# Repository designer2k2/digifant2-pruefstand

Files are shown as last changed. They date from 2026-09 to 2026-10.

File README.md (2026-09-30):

# Digifant-2 Prüfstand




Hardware for a fully-automated test bench for the VW Golf 1 Cabrio **Digifant-2** ECU:
signal simulator + capture front-end, driven by a Raspberry Pi Pico 2, with a
high-side load switch so the bench can cold-boot the ECU and cut power on
overcurrent. Scope here is the **Signal-Simulator + Erfassungseinheit** only — the
EPROM emulator is a separate future board.

The schematic is generated from Python with
[circuit-synth](https://github.com/circuit-synth/circuit-synth); the PCB is placed
and autorouted headless (`pcbnew` + Freerouting).

**[`firmware/OPERATION.md`](firmware/OPERATION.md) — how to operate the
bench: display and buttons, PC control and scripting, reading the
measurements.**

**[`BRINGUP.md`](BRINGUP.md) — step-by-step first power-on checklist, tools
needed, and the open questions to settle on the bench.**

**[`DESIGN.md`](DESIGN.md) — what every block does, part-selection rationale, the
GPIO / I²C / VW-harness maps.** [`USE_CASES.md`](USE_CASES.md) traces every real
bench use case through the schematic to concrete numbers (voltage/current/timing
headroom) — a requirements/test matrix for the hardware, and where the AD9833
decoupling-cap gap turned up before it got fixed.

## Layout

| path | what |
|---|---|
| `digifant2_pruefstand.py` | the circuit — one `@circuit` function, flat single sheet |
| `gen_custom_symbols.py` | builds `kicad-symbols/Custom_Digifant2.kicad_sym` (INA226, AD9833, 2N7002, DPAK P-FET, VW connector — pinouts verified against datasheets) |
| `gen_project.py` | `python3 gen_project.py <name>` → full KiCad project + netlist + lib tables, runs ERC/DRC via `kicad-cli`, auto-applies no-connect flags |
| `place_and_route.py` | `pcbnew` functional-zone placement → Specctra DSN → Freerouting → SES import (run inside the KiCad flatpak; `java` runs outside it) |
| `add_nc_flags.py` | stamps `no_connect` flags from an ERC report (circuit-synth has no NC API) |
| `fix_layout.py` | post-route layout surgery (real netclasses, GND/Kelvin re-routing) — see the header comment for the 2-phase, 2-process invocation it needs |
| `reroute_missing.py` | re-exports a Specctra DSN from a partially-ripped-up board so Freerouting only has to fill the reopened ratsnest |
| [`firmware/`](firmware/README.md) | Pico firmware (Pico SDK, C): USB serial command protocol, build/flash instructions, what's implemented vs. stubbed |
| `host/bench.py` | PC-side client for the firmware protocol: interactive prompt, one-shot CLI, or importable `Bench` class; `host/examples/` has a scripted rpm sweep |
| `board/` | the current KiCad project (144×150 mm, 2-layer, 4× M3 corner holes, isolated OLED + USB clearance zones) |
| [`board/bom_output/bom.html`](board/bom_output/bom.html) | interactive BOM ([InteractiveHtmlBom](https://github.com/openscopeproject/InteractiveHtmlBom)) — click a part to highlight it on the board, no KiCad needed |
| [`BOM.md`](BOM.md) | Mouser sourcing: part numbers for every line item, with confidence notes — 6 of 30 need manual confirmation, see the file |
| [`mouser_cart.csv`](mouser_cart.csv) | only the Mouser-verified part numbers, ready to paste into Mouser's bulk order tool |
| [`JLCPCB_ASSEMBLY.md`](JLCPCB_ASSEMBLY.md) | hybrid plan: JLCPCB machine-places the SMD parts, you hand-solder THT + 4 unconfirmed SMD parts — read this before submitting |
| [`jlcpcb_bom.csv`](jlcpcb_bom.csv) / [`jlcpcb_cpl.csv`](jlcpcb_cpl.csv) | JLCPCB SMT-assembly BOM + pick-and-place, 42 of 46 SMD parts (real positions from `board/`, real LCSC part numbers) |
| `UPSTREAM_BUGS.md` | circuit-synth bugs found, drafted for upstream filing |
| `kicad-symbols/`, `kicad-footprints/` | libraries — custom/community committed, stock via `./fetch_libs.sh` |
| `.github/workflows/` | CI: firmware build + tests, spell check, KiCad ERC/DRC, firmware releases (see below) |

## Build

```sh
./fetch_libs.sh                        # one-time: pull stock KiCad 9.0 libs
python3 gen_custom_symbols.py          # if the custom symbols changed
python3 gen_project.py digifant2_pruefstand_cs_v1
```

Placement + routing needs KiCad's `pcbnew` Python API (KiCad ≥ 10) and a
non-headless JRE for Freerouting — see the header of `place_and_route.py`.

## Status

Schematic ERC-clean; VW harness pinout verified against the cabby-info.com
Digifant II reference and the user's own hands-on HiL notes (see `DESIGN.md`).
Board placed + autorouted (144 × 150 mm, 2-layer, 4 × M3 holes, isolated OLED + USB
clearance zones), real Power/Gnd netclasses, GND re-routed as one connected net
(was 4 islands), dedicated Kelvin sense traces for both shunts. The tight
U1/U3/RS1/RS2 pocket (2 shorting_items, 2 clearance, 5 tracks_crossing left by
the scripted Kelvin routing) was cleaned up by hand in KiCad's interactive
router, and a B.Cu GND pour was added. Added the two AD9833 decoupling caps
(C7, C8), fully routed. Fixed RS2 (idle-valve shunt) to be truly in series
with the ECU's VW-23 driver instead of a parallel path to GND that was
corrupting the current reading — this reopened one small pocket at U3 pin 9
(2 `shorting_items`, confined to that one spot after extensive
hand-routing/Freerouting attempts, same class of residual as the historical
U1/U3/RS1/RS2 items). Gave the AD9833 knock output a defined path out
(TP1/TP2 test points for VW-4/VW-5) instead of a dead end. Added 12 more
THT scope-probe test points (TP3–TP14, real drilled holes — an earlier pass
used bare SMD pads and put 10 of them physically underneath the Pico module,
both corrected) on the main GPIO signals, both buses, and both 12 V rails.
Found and fixed a real bug along the way: footprints cloned via
`pcbnew.FOOTPRINT(template)` inherit the template's UUID unless you
explicitly reset it, which had corrupted DRC's item-identity tracking for
every cloned part this session (C7/C8 and all of TP1–TP14) — several
"violations" turned out to be real defects reported against the wrong
footprint. See DESIGN.md's "Known open points" for details if you script
further additions. Remaining warnings are cosmetic (silkscreen overlap,
lib_footprint_mismatch, and one starved_thermal note on a single Pico GND
pad with only 1 pour spoke instead of 2 — connected fine, just a slightly
weaker thermal/mechanical joint). Thermal copper for D1/Q2 still optional to
add by hand. Added a 12×16 perfboard-style proto area (PROTO1, isolated THT
pads on 0.1″ pitch) in the empty space bottom-right of J0. Checked the whole
board against JLCPCB's published fab minimums (trace/spacing, via/hole sizes,
hole-to-hole, copper-to-edge, board thickness) — everything copper- and
hole-related had 1.5×–14× margin already. The one real miss was silkscreen:
KiCad's default 0.1mm line width and 0.8mm text height are both below
JLCPCB's stated minimums (0.15mm / 1.0mm), risking thin/dropped silkscreen.
Bumped the project defaults and widened/enlarged every existing silkscreen
line and text item on the board to meet those minimums.

Checked +3V3 for adequate trace width (it's on the thinnest `Default`
netclass, 0.2mm, despite feeding ~15 chips) — worked out the real numbers
(thermal capacity ~0.77A at 10°C rise, worst-case drop a few mV) and it's
fine as-is; not worth the rerouting risk in this densely-packed board.
Checked decoupling instead: per each part's own datasheet, U1 and U3 (the
two INA226 current-sense amps) had no bypass cap at all, unlike U2/U4 which
already have theirs (C6, C2/C7/C8). Added C9 (U1) and C10 (U3), 100nF 0805,
tapped directly off the existing +3V3 B.Cu trunk and the GND pour a few mm
south of the packed U1/U3/RS1/RS2 pocket (no room to place them right at the
pins) — verified DRC-clean (the only residuals are the same
new-copper-vs-stale-zone-fill noise that clears on a zone refill, same as
after the TP resort). U6/U7/U8 (the sensor-disconnect analog switches) are
still without a bypass cap; lower priority since they're not
noise-sensitive, but could use the same treatment.

Added the thermal copper for D1/Q2 that was flagged as a real (not
cosmetic) risk in USE_CASES.md — D1 dissipates ~1.25W at sustained ~2.5A
with no thermal relief otherwise. Both pours verified electrically
connected to their pads (not just overlapping) and DRC-clean. Q2's is
small since there's almost no open board space around its DPAK tab; D1's
is generous since F1/RS1 (same nets, either side) leave a wide open
corridor.

**All 14 test points (TP1–TP14) are now fully routed** — the user hand-routed
7 of the 10 remaining GPIO test points after the resort (TP3, TP10, TP11,
TP4, TP12, TP5, TP6); the last 3 (TP9, TP8, TP7 — all on U5's east side, the
tightest part of the board) were routed with a grid-based pathfinder (A* over
a 0.1mm grid, spatial-bucket-indexed for speed) purpose-built for this corridor
after several rounds of manual/heuristic routing kept snagging on real
obstacles: the Pico's own pin column has no gap wide enough for a second
trace anywhere along its length (confirmed by direct probing — routed escape
stubs from other GPIOs fill in what would otherwise be a 0.49mm theoretical
gap between pin pads), so both TP8 and TP9 had to detour around the *south*
end of the Pico footprint entirely, and — since that detour corridor is
itself only wide enough for one trace at a time — needed genuinely different
physical crossing points, not just parallel lanes. Verified via real
`kicad-cli pcb drc`, not just the pathfinder's own clearance model (which
undercounted real collisions during development in two ways worth noting for
next time: it modeled non-circular pads by their half-width instead of their
half-diagonal, and it didn't check hole-to-hole spacing against a net's own
via near its own pad — both are now fixed in the approach, see `DESIGN.md`).
GND zone refilled after all of the above (TP9/TP8 routing, C9/C10, D1/Q2
thermal pours) — DRC dropped from 136 to 101 violations, all pre-existing
cosmetic categories plus the one known `starved_thermal` note, zero
clearance/short/crossing issues. (The "whole-board refill introduces ~115
spurious violations" finding earlier this session was a testing artifact —
running `kicad-cli` against a bare copy of the `.kicad_pcb` without its
paired `.kicad_pro` silently falls back to stricter default netclass rules;
with the project file present, the refill is clean.)

Trimmed the board from 144×169mm to 144×150mm — the bottom 19mm was
completely empty (bare GND pour, nothing below PROTO1/J3 until the old
mounting holes). H3/H4 moved up to keep the same 4.5mm hole-to-edge margin
as H1/H2; DRC stayed clean (99 violations, same pre-existing cosmetic set).

Added functional silkscreen labels next to J0 (the VW harness connector) and
every test point, instead of leaving bare unlabeled pads. J0 gets each pin's
real VW harness number (VW-2, VW-9, ... or GND / +12V SW) in the clear strip
just outside its footprint. The TPs already had descriptive text (e.g.
`GP2_CRANK`) sitting on them from earlier in the session — turned out it was
on **F.Fab**, a documentation-only layer that doesn't actually get printed on
the physical board, so none of it was ever going to be visible with a probe
in hand. Moved it to F.SilkS and shortened the long ones (e.g.
`GP6_THROTTLE_IDLE_SW` → `IDLE SW`) since the west-margin TP column only has
about 10mm of clearance between the board edge and the Pico's pin column —
the original full-length strings would have run off the board edge once
actually rendered as real silkscreen (checked via real bounding-box widths,
not by eye). This did add some new `silk_overlap` hits — mostly TP labels
sitting close to the Pico module's own tiny per-pin silkscreen text in that
same tight corridor — all cosmetic, same accepted category as the rest of
this board's silkscreen warnings, verified via DRC to introduce zero
clearance/short/crossing issues.

Added fab-identification text on the back silkscreen (B.SilkS, previously
completely empty — no back components, nothing on that layer at all):
project name, revision, date, and designer, so a bare board can still be
identified later. Set via the board's title block (`${TITLE}`,
`${REVISION}`, `${ISSUE_DATE}`, `${COMPANY}`) rather than hardcoded text, so
updating the revision/date for a future respin is a one-place edit in
KiCad's Page Settings, not a silkscreen re-edit. Verified the variables
resolve correctly (checked the exported SVG's embedded text, since this
sandbox can't render the actual glyphs) and confirmed zero new DRC
violations. Not yet fabbed.

## Continuous integration

Every push and pull request runs on GitHub Actions:

| Workflow | What it checks |
|---|---|
| **CI** (`ci.yml`) | Builds the firmware with Pico SDK 2.1.1, warnings as errors, and uploads `pruefstand.uf2` as a build artifact. Runs `firmware/test/run_all.sh`: all PC unit tests, the command parser, `host/bench.py` over a virtual serial port, and the crank PIO program in an emulator. |
| | Spell check with [codespell](https://github.com/codespell-project/codespell) over code, comments and docs (`.codespellrc`). |
| **Board** (`board.yml`, only when `board/` changes) | KiCad 10 ERC, and DRC with schematic parity. Fails on errors (unconnected nets, clearance, shorts); the known cosmetic warnings are only reported. Full reports are attached to the run. |

Before opening a pull request, the same checks run locally with
`firmware/test/run_all.sh` (after a firmware build) and `codespell`.

**Firmware releases:** bump `FW_VERSION` in `firmware/src/cmd.h`, commit, then
push a matching tag, e.g. `git tag fw-v0.9.0 && git push origin fw-v0.9.0`. CI
checks the tag against `FW_VERSION`, runs everything above, and publishes a
GitHub Release with `pruefstand-<version>.uf2` to download and flash.

## License

MIT (see `LICENSE`) for everything authored here — scripts, custom symbols, the
board design. Bundled third-party files (the Raspberry Pi Pico symbol/footprint
from [ncarandini/KiCad-RP-Pico](https://github.com/ncarandini/KiCad-RP-Pico),
CC-BY-SA-4.0) keep their own licenses — see `NOTICE`.

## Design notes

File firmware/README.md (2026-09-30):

# Pruefstand firmware (Raspberry Pi Pico 2, Pico SDK / C)

USB serial command protocol plus the hardware blocks behind it. **To use the
bench, start with [`OPERATION.md`](OPERATION.md)** (display, buttons, PC
control, how to read the measurements); this file is the developer reference. The PC side
(`../host/bench.py`) and later Claude Code drive the bench through this.
Milestones so far: 1 skeleton and protocol, 2 crank signal, 3 sensor DAC,
4 current/voltage sensing, 5 knock generator, 6 ignition/injector capture,
7 crank-synchronised knock bursts, 8 OLED and button menu, 0.9 review fixes
(ECU over-current trip, output parking, watchdog, capture/burst timing).
Every hardware block on the board now has a real driver.

## Build and flash

```sh
git clone --depth 1 --branch 2.1.1 https://github.com/raspberrypi/pico-sdk.git ~/pico-sdk
(cd ~/pico-sdk && git submodule update --init --depth 1 lib/tinyusb)
export PICO_SDK_PATH=~/pico-sdk

cmake -S . -B build -DPICO_BOARD=pico2
make -C build -j
```

Needs `cmake` and `gcc-arm-none-eabi` (plus `libnewlib-arm-none-eabi`); the same
toolchain covers the RP2350's Cortex-M33 (`PICO_BOARD` is forced to `pico2` in
`CMakeLists.txt`, so `-DPICO_BOARD=pico` above is only for clarity, not required
-- the original Pico/RP2040 isn't supported). To flash, hold BOOTSEL while
plugging in the Pico 2 and copy `build/pruefstand.uf2` onto the `RP2350` drive.

The whole program is linked to run from RAM (`copy_to_ram`, ~60 KB of 264 KB),
so interrupt handlers never wait on flash-cache misses.

## What is real and what is a stub

| Module | State | Hardware |
|---|---|---|
| ECU power with over-current trip, idle switch, sensor disconnect | **real** | GP13 + U1, GP6, GP8/9/11 |
| VW-17 reference (`read` → `afm_ref_mv`) | **real** | GP26/ADC0, ×3 divider |
| Crank / Hall signal (`rpm`, `crank`) | **real** | GP2 → Q1, PIO0 SM0 |
| Sensor DACs (`dac`) | **real** | MCP4728 @ 0x60 |
| Current/voltage sense (`read` → `ecu_*`, `valve_*`) | **real** | INA226 @ 0x40 / 0x41 |
| Knock DDS (`knock`, `burst`) | **real**, continuous or crank-synced bursts | AD9833 on SPI0 |
| Ignition / injector capture (`capture`) | **real** | GP14 / GP15, crank reference on GP2 |
| OLED + buttons | **real** | SSD1306 @ 0x3C on J3, SW1–SW3 on GP20–22 |

Power-up state, set before any pin becomes an output: ECU **off**, idle switch
**open**, all three sensors **connected**, crank stopped (VW-18 high), DAC
outputs at 0 V. USB is the Pico's only power (VSYS/VBUS aren't wired to the
board), so unplugging it resets the bench to this state; R16 keeps the ECU off
while the Pico is unpowered.

A 2 s watchdog resets the Pico if the main loop hangs (e.g. a hard fault),
which also drops the ECU rail. `status` reports `boot=watchdog` after such a
reset, `boot=power` otherwise.

## ECU power and over-current trip

`ecu on|off` switches the ECU rail (Q2). While it's on, the main loop reads U1
every 150 ms (one new INA226 result each time); two results in a row above the
trip current switch the ECU off and latch a fault: `status` shows
`ecu_fault=overcurrent`, `ecu on` is refused, and the OLED shows `ECU TRIP`
until `ecu reset` (or − on the ECU menu item). `ecu trip <mA>` sets the limit,
100–4000 mA, default **2500 mA** (ECU ~0.6 A plus a cold idle valve ~1.8 A,
below F1's 3 A).

U1 averages over ~141 ms, so this catches a harness short or a failing ECU
within about 0.3 s, not short spikes; F1 is still the fast protection. If U1
isn't answering there is no trip (`read` then shows `ecu_a=na`).

While the ECU is off, the sensor DACs are held at 0 V and the knock generator
in reset, so they can't feed current into the unpowered ECU's inputs through
its protection diodes. Setpoints are kept (and shown by `status`) and applied
when the ECU is switched on: rail first, then the outputs; on switch-off the
outputs are parked first. So to check a DAC output with a multimeter, switch
the ECU on (with or without an ECU connected).

Signal polarities to keep in mind (see `src/pins.h`): GP2 high pulls VW-18
*low* (Q1 is an open-drain pull-down), and the ignition/injector capture inputs
(GP14/GP15) see *active-low* pulses.

## Crank / Hall signal

A PIO state machine generates the square wave on GP2 with cycle-exact timing.
Each phase length is queued in the TX FIFO and topped up from an interrupt,
so a busy main loop (e.g. USB output) can't stretch a period. Range: `rpm`
0–8000, where 0 stops the wave with VW-18 held high. The 32-bit phase counters
reach down to about 1 rpm, so cranking speeds are no problem (the RP2350's
PWM block has the same fundamental limit as the RP2040's -- an 8.4 fixed-point
clock divider over a 16-bit counter -- and can't go below ~9 Hz, which is why
it isn't used).

Waveform, adjustable at runtime:

- `crank ppr <n>`: pulses per **crank** revolution. Default **2**: a
  4-cylinder distributor Hall sender with 4 vanes, turning at half crank speed.
- `crank duty <pct>`: percent of each period VW-18 is **high**. Default **50**.

**Both defaults come from the user's own distributor HiL notes** (a 30 Hz,
50% duty square wave at 900 rpm -- exactly 2 pulses per crank rev -- named
"DIZZY_FOUR_CYLINDER"). Still worth a scope check against the real 2H sender
(see `BRINGUP.md`) before trusting it blindly; they only change the timing,
nothing else depends on them.

A new `rpm`/`ppr`/`duty` takes effect once the phases already queued in the
FIFO have played out: up to about two and a half periods (~90 ms at 850 rpm,
2 ppr).

Timing is `crank_timing.c`, plain C: period = 60 s / (rpm × ppr) in system
clock cycles, split by duty, minus the program's fixed 4-cycle overhead per
phase. `test/test_crank_timing.c` checks it against hand-computed values, and
`test/emu_crank_pio.py` runs the assembled `crank.pio` in an independent PIO
emulator to confirm the N + 4 cycles-per-phase model it relies on.

## Sensor DAC (MCP4728)

All four channels use the chip's internal 2.048 V reference, which is more
accurate than the Pico's 3V3 rail:

| Channel | Output | Gain | Step | Range |
|---|---|---|---|---|
| `air` | VOUTA → R2 220 Ω → VW-9 | ×2 | 1 mV | 0–3300 mV |
| `water` | VOUTB → R3 220 Ω → VW-10 | ×2 | 1 mV | 0–3300 mV |
| `afm` | VOUTC → R4 220 Ω → VW-21 | ×2 | 1 mV | 0–3300 mV |
| `lambda` | VOUTD → R5 1 kΩ → VW-2 | ×1 | 0.5 mV | 0–2047 mV |

At gain ×2 the chip could reach 4.096 V, but the output can't exceed its
3.3 V supply, hence the 3300 mV limit (the top few tens of mV may clip).

Every write is an MCP4728 Multi-Write (datasheet DS22187E, fig. 5-8) that
carries the reference and gain bits along with the value. The chip powers up
from its own EEPROM settings, so this way a DAC reset can't leave a channel
silently mis-scaled. EEPROM is never written. At boot all four channels are set
to 0 V. A failed write returns `ERR dac not responding on i2c` and leaves the
old setpoint; after any failure (including at boot) the firmware rewrites all
four channels once a second until the chip answers. `status` shows
`dac_i2c=ok` only while the chip holds the values shown.

At boot, before the I²C peripheral starts, SCL is clocked until SDA is released
and a STOP is sent, in case a Pico reset interrupted a transfer and left a chip
holding the bus.

**`dac` sets the DAC output pin, not the voltage the ECU measures.** There's a
series resistor between them (220 Ω, or 1 kΩ for lambda), so the two only match
if the ECU input draws no current. If the ECU's NTC inputs have an internal
pull-up to 5 V (common for temperature inputs), the voltage at VW-9/VW-10 will
sit above the setpoint. That offset needs calibrating against the real ECU
(measure the pin with the sensor switched to `open`, then again under load)
before `dac` values can be mapped to temperatures.

## Current and voltage sense (INA226)

| `read` field | Chip | Measures |
|---|---|---|
| `ecu_a` | U1 @ 0x40, RS1 0.020 Ω | total ECU current, 0.125 mA steps, up to 4.09 A |
| `ecu_v` | U1 VBUS | `+12V_ECU`, upstream of the Q2 switch (~0.1 V above VW-14) |
| `valve_a` | U3 @ 0x41, RS2 0.033 Ω | idle-valve current, 0.076 mA steps, up to 2.48 A |
| `valve_v` | U3 VBUS | `+12V_ECU_SW`, the valve feed |

Current is computed directly from the shunt-voltage register (V_shunt / R_shunt),
so the chip's calibration and current registers aren't used. U3's IN+ sits on
the ECU side of RS2, so its raw reading is negative for normal valve current;
the firmware flips the sign so `valve_a` is positive.

Each chip averages 64 samples of 1.1 ms shunt + 1.1 ms bus conversions, giving
one new result every ~141 ms. That smooths the idle valve's PWM into an average
current; reading `read` faster than that just returns the same result again.

A chip is only configured after it answers with TI's manufacturer ID (0x5449).
If one is missing or stops answering, its fields read `na`, and it's retried on
the next `read`.

## Knock generator (AD9833)

`knock <hz>` outputs a continuous sine at 1–20000 Hz on TP1 (to VW-4), `knock
off` stops it. The AD9833 runs from Y1's 25 MHz clock, so the frequency step is
0.093 Hz. Each change holds the chip in reset, loads FREQ0 as two 14-bit halves,
zeroes PHASE0 and releases reset, so the tone always starts at phase 0. Off
means held in reset: the output sits at a DC midscale level with no AC. While
the ECU is off the chip is held in reset whatever `knock` is set to (see "ECU
power"); the tone starts when the ECU is switched on.

SPI0 runs at 8 MHz in mode 2 (clock idles high, data clocked in on the falling
edge), with FSYNC (GP16) toggled per 16-bit word. The register layout follows
the AD9833 datasheet, cross-checked against the Linux kernel's `ad9834` driver
and the RobTillaart Arduino library, since the datasheet PDF couldn't be fetched
from this sandbox.

### Crank-synchronised bursts

`burst <start_deg> <len_deg> [every]` switches from a continuous tone to bursts:
on each crank reference (VW-18 falling edge, the same one `capture` uses) the
tone starts `start_deg` crank degrees later and runs for `len_deg`. With
`every` = N only every Nth reference gets a burst, e.g. `every 2` at 2 ppr is
once per crank revolution, like a single knocking cylinder on a 4-cylinder.
`knock <hz>` still sets the frequency and `knock off` silences everything;
`burst off` goes back to a continuous tone.

Degrees are converted to microseconds with the *measured* reference period,
so bursts follow RPM changes from the next reference on. A burst has to start
and end within one reference period (start + len < 360/ppr, i.e. < 180° at the
default 2 ppr), so it can never overlap the next one. If the RPM rises suddenly
and a reference arrives while a burst is still on, it's cut off at that
reference and the next one is scheduled with the new period.

Timing: the capture interrupt handles the reference edge and arms a hardware
alarm for the burst start; the alarm fires again for the stop. Starting or
stopping is a single 16-bit SPI word (~2 µs at 8 MHz), and releasing reset
starts the tone at phase 0, so every burst has the same waveform. If the start
time has already passed by the time the reference is handled (start 0°), the
burst starts immediately rather than being skipped. The alarm callback checks
that its alarm is still wanted and actually due before touching the chip: an
alarm interrupt that fired while the reference interrupt was running stays
latched and runs right after it, and the SDK only checks the high word of the
target, so without that check it could start a burst early or cut one short.

**Amplitude is still fixed.** The AD9833's output level can't be set, and R12
(200 Ω) with C2 (100 nF to ground) low-pass the output with a corner near
8 kHz, so the level at TP1 falls across the knock band: about 85% of full at
5 kHz, 62% at 10 kHz, 47% at 15 kHz, 37% at 20 kHz. Knock *intensity* can't be
varied independently of frequency without a hardware change.

## Ignition and injector capture

`capture` reads back what the ECU is doing on VW-25 (ignition, GP14) and VW-12
(injector, GP15). Both are low-side outputs pulled up to 3V3, so a pulse is the
**low** phase: injector open time, and probably ignition dwell.

| Field (`ign_` / `inj_`) | Meaning |
|---|---|
| `_n` | completed pulses since boot |
| `_glitch` | pulses shorter than the interrupt latency, ignored |
| `_period_us` | falling edge to falling edge |
| `_low_us` | width of the last pulse |
| `_fall_deg`, `_rise_deg` | crank degrees from the last VW-18 falling edge to the pulse's falling / rising edge |

Values read `na` if no pulse has ended in the last 2 s, and the angles also
need the bench's own crank signal running (`rpm` > 0).

One GPIO interrupt timestamps every edge on GP14, GP15 and GP2 with the 1 µs
hardware timer, reading the clock once on entry so every edge handled in that
interrupt gets the same time. GP2 is driven by the crank PIO, but its pad input
still sees the level, so the crank reference is timestamped by the same
interrupt path as the ECU outputs. An ECU edge latched together with a
reference is counted as just before it (angle ≈ 360/`ppr`). If both edges of a
pulse arrive within one interrupt, the pin level decides: low means a pulse
ended and the next began; high means a pulse shorter than the interrupt
latency, which is counted in `_glitch` and otherwise ignored. The capture pins'
internal pull-downs are off, so only the external pull-ups set the high level.
Timestamps are 64-bit, and a reference more than 2 s after the previous one
(crank stopped and restarted) doesn't produce a period, so angles resume from
the second reference after a restart. Angle = delay since the reference ÷ reference period ×
360 / `ppr`, using the *measured* reference period rather than the setpoint.
Both edges of a pulse are measured from the reference that came before the
falling edge, so a pulse straddling a reference reads e.g. 170° → 200°, not
170° → 20°. Interrupt latency adds a few µs; one crank degree at 6000 rpm is
27.8 µs.

**Two conventions still need confirming on the real ECU:** which VW-18 edge
Digifant-2 uses as its reference (the falling edge is used here), and which
ignition edge is the spark (probably the end of the low phase, i.e.
`ign_rise_deg`). Both edges are reported, so nothing is lost either way, only
the offset between them changes.

## Standalone operation: OLED and buttons

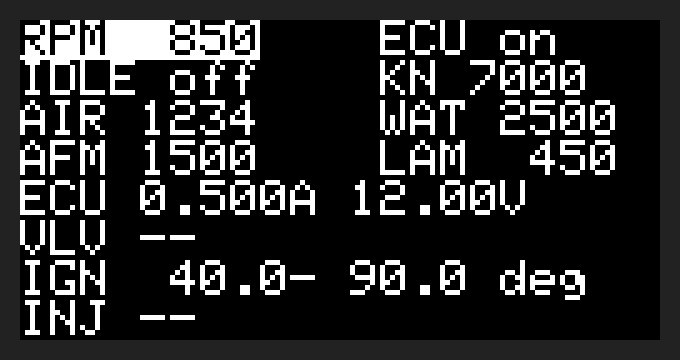
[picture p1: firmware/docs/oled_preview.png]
OLED screen, rendered on the PC with test data


A 0.96″ **SSD1306 128×64** I²C OLED on J3 shows the bench's state, refreshed
every 200 ms and immediately after a button press. The top four rows are the
adjustable items; the selected one is drawn inverted:

| Item | − / + |
|---|---|
| `RPM` | ±50 rpm, 0–8000 (held: auto-repeat) |
| `ECU` | − off, + on (no toggle, no repeat) |
| `IDLE` | − off, + on (no toggle, no repeat) |
| `KN` | ±500 Hz knock tone, down to off; `*` = burst mode |
| `AIR`, `WAT`, `AFM`, `LAM` | ±50 mV on that DAC channel |

**MENU** (SW1) steps to the next item. Buttons are debounced (20 ms) and
repeat after 400 ms, then every 100 ms. The bottom four rows are readouts: ECU
current and supply, idle-valve current and supply, ignition edge angles (or its
low time with the crank stopped), and injector pulse width and angle.

Buttons and USB commands change the same state, so either can be used at any
time. Without a display the buttons still work, and the display is picked up
within 2 s if it's plugged in later. The panel is assumed to be an SSD1306;
1.3″ modules often use an SH1106 instead, which needs a different init and
column offset.

Rendering and the menu logic are in `ui_core.c` (no hardware), the SSD1306
driver in `oled.c` (init sequence as in Adafruit's SSD1306 library), and the
font is the Adafruit GFX 5×7 font (BSD, see `NOTICE`).

## Protocol

ASCII over USB CDC (baud rate is ignored). One command per line (`\n` or `\r\n`),
case-insensitive. Every command gets exactly one reply line: `OK ...` with
`key=value` fields, or `ERR <reason>`. No echo. Numbers are plain decimal
digits (no sign). `bench.py` drops any unread input before sending a command,
so a reply that arrives after a timeout isn't mistaken for the next answer.

| Command | Reply |
|---|---|
| `ping` | `OK pong fw=0.9.0` |
| `help` | `OK <usage of every command>` |
| `status` | `OK fw=… boot=power/watchdog ecu=on/off ecu_fault=none/overcurrent ecu_trip_ma=… idle=on/off rpm=… crank_ppr=… crank_duty=… sensor_<air/water/lambda>=conn/open dac_<air/water/afm/lambda>=<mV> dac_i2c=ok/err knock_hz=… burst=on/off burst_start_deg=… burst_len_deg=… burst_every=…` |
| `read` | `OK afm_ref_mv=… ecu_v=… ecu_a=… valve_v=… valve_a=…` (`na` if not available) |
| `capture` | `OK ign_n=… ign_glitch=… ign_period_us=… ign_low_us=… ign_fall_deg=… ign_rise_deg=… inj_…` (same fields for `inj_`) |
| `ecu on\|off` | `OK ecu=…`, or `ERR ecu tripped …` while a fault is latched |
| `ecu reset` / `ecu trip <100..4000 mA>` | `OK ecu_fault=none` / `OK ecu_trip_ma=…` |
| `idle on\|off` | `OK idle=…` |
| `sensor air\|water\|lambda conn\|open` | `OK sensor_<name>=…` |
| `rpm <0..8000>` | `OK rpm=…` (very low rpm at 1 ppr and extreme duty can exceed the 32-bit phase counter and is rejected) |
| `crank ppr <1..60>` / `crank duty <1..99>` | `OK crank_ppr=…` / `OK crank_duty=…`; a `ppr` that an active burst wouldn't fit is refused |
| `dac air\|water\|afm\|lambda <mV>` | `OK dac_<name>=…` (ranges per channel, see above) |
| `knock off\|<1..20000 Hz>` | `OK knock_hz=…` |
| `burst <start_deg> <len_deg> [every]` / `burst off` | `OK burst=on burst_start_deg=… …` / `OK burst=off` |

## Testing without hardware

Everything below runs in one go, as CI does (after building the firmware, for
the PIO header; `pip install -r test/requirements-test.txt`, plus `socat`):

```sh
test/run_all.sh build
```

The individual steps:

`cmd.c` and the `*_codec.c` / `crank_timing.c` files have no Pico dependencies,
so they build for the PC against the fakes in `test/` (in-memory state, VW-17
fixed at 5000 mV, ECU reading 12 V / 0.5 A unless a test changes it, valve
INA226 "missing"). `knock.c` and `dac.c` themselves run on the PC against
`test/fake_sdk/`, a small simulated Pico SDK with a settable clock, one
hardware alarm, and logs of every SPI word and I²C write. It runs no real
interrupts, so concurrency is not tested; a stale, latched alarm interrupt is
modelled by calling the alarm callback directly:

```sh
gcc -Itest/fake_sdk -Isrc -o /tmp/bench-sim test/host_main.c test/fake_sdk/sim.c \
    test/fake_board.c test/fake_crank.c test/fake_dac.c test/fake_sense.c test/fake_capture.c \
    src/cmd.c src/crank_timing.c src/dac_codec.c src/ecu.c src/knock.c src/knock_codec.c
printf 'ecu on\nstatus\n' | /tmp/bench-sim

# ECU over-current trip and output parking order:
gcc -Isrc -o /tmp/test_ecu test/test_ecu.c src/ecu.c test/fake_board.c test/fake_sense.c \
    && /tmp/test_ecu

# crank timing math, and the PIO program in an emulator:
gcc -Isrc -o /tmp/test_crank test/test_crank_timing.c src/crank_timing.c && /tmp/test_crank
python3 test/emu_crank_pio.py

# MCP4728 frame bytes, decoded back to volts with the datasheet formula:
gcc -Isrc -o /tmp/test_dac test/test_dac_codec.c src/dac_codec.c && /tmp/test_dac

# dac.c: parking at 0 V while the ECU is off, and rewriting after a failed write:
gcc -Itest/fake_sdk -Isrc -o /tmp/test_dacd test/test_dac_driver.c src/dac.c src/dac_codec.c \
    test/fake_sdk/sim.c && /tmp/test_dacd

# INA226 register conversions and the shunt/current math:
gcc -Isrc -o /tmp/test_sense test/test_sense_codec.c src/sense_codec.c -lm && /tmp/test_sense

# AD9833 SPI word sequences:
gcc -Isrc -o /tmp/test_knock test/test_knock_codec.c src/knock_codec.c && /tmp/test_knock

# burst timing math, and knock.c's alarm state machine on a simulated clock
# (including interrupt latency and stale alarm callbacks):
gcc -Itest/fake_sdk -Isrc -o /tmp/test_burst test/test_knock_burst.c test/fake_sdk/sim.c \
    src/knock.c src/knock_codec.c && /tmp/test_burst

# button debounce/repeat, menu actions, and the OLED framebuffer (ASCII art +
# a PBM image; convert with e.g. `convert /tmp/oled.pbm -negate -scale 500% oled.png`):
gcc -Itest/fake_sdk -Isrc -o /tmp/test_ui test/test_ui.c test/fake_sdk/sim.c \
    test/fake_board.c test/fake_crank.c test/fake_dac.c test/fake_sense.c test/fake_capture.c \
    src/ui_core.c src/gfx.c src/crank_timing.c src/dac_codec.c src/ecu.c src/knock.c \
    src/knock_codec.c -lm && /tmp/test_ui /tmp/oled.pbm

# capture bookkeeping against a simulated 850 rpm engine, plus stop/restart,
# edges latched together, and glitches:
gcc -Isrc -o /tmp/test_cap test/test_capture_core.c src/capture_core.c -lm && /tmp/test_cap

# or behind a virtual serial port, to exercise host/bench.py too:
socat PTY,link=/tmp/ttyBench,raw,echo=0 EXEC:/tmp/bench-sim,pty,raw,echo=0 &
python3 ../host/bench.py --port /tmp/ttyBench "rpm 850" read
```

That's how milestones 1–8 and the 0.9 fixes were checked. Nothing has run on a
real Pico yet. For the first power-on on real hardware, follow
[`../BRINGUP.md`](../BRINGUP.md), a staged checklist with expected values for
every block.

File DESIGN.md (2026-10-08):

# Design notes

What every block does and why the parts were chosen. The schematic is generated
by `digifant2_pruefstand.py`; each function there is one block below.

## Overview

A Raspberry Pi Pico 2 drives a set of analog and digital front-ends that stand in
for every sensor and signal the Digifant-2 ECU expects, while two INA226 current
monitors and a switchable 12 V rail let the bench watch what the ECU does and
cut its power. Everything the ECU sees goes through **J0**, a 12-position 5 mm
screw-terminal block wired to the real VW-155906373 harness connector.

Rails: `VIN_12V` (bench supply) → `+12V_PROT` (post-fuse) → `+12V_POST_D1`
(post reverse-polarity diode) → `+12V_ECU` (post shunt, *always* live, this is
what U1 measures) → **Q2 load switch** → `+12V_ECU_SW` (feeds the ECU harness,
the idle valve, and the crank pull-up). Logic runs off the Pico's own `+3V3`,
which the Pico regulates from its USB connection to the host PC — this board
never powers the Pico.

## Blocks

### `power_section` — bench input and protection
| ref | part | why |
|-----|---|-----|
| J1 | 5.08 mm screw terminal | bench 12 V in; ~10 A rated, no concern |
| F1 | **3 A** fuse, 1206 | worst case is ECU (~0.6 A) + cold idle-valve inrush (~1.8 A) + logic ≈ 2.5 A — a 2 A fuse nuisance-trips |
| D1 | **SS54** Schottky, SMC | reverse-polarity protection; SS54 is 5 A — SS34's 3 A has no margin and runs ~1.3 W hot at 2.5 A |
| RS1 | **0.02 Ω** 1 % shunt, 2512 | 40 mV at 2 A, well inside the INA226 ±81.92 mV range; 0.08 W in a 1 W part |
| C1 | 100 µF / 25 V | bulk on the *switched* rail so it also supplies (and RS1 measures) the ECU's cold-boot inrush |

`RS1` uses a plain 2-pin resistor symbol — there is no stock 4-pad Kelvin 2512
footprint. For an accurate reading, route U1's `IN+/IN−` as their own thin traces
tapped right at the RS1 pads during layout, not off the power copper.

### `ecu_power_switch` — high-side load switch to the ECU
Lets firmware cold-boot the ECU and drop the rail on an overcurrent reading from
U1 (RS1 sees the switch plus every downstream load).

| ref | part | role |
|-----|---|---|
| Q2 | P-MOS, −30 V, ≥5 A, DPAK (TO-252) | high-side pass element between `+12V_ECU` and `+12V_ECU_SW`; give the drain tab a copper pour |
| Q3 | 2N7002, SOT-23 | level-shifts the 3 V3 `GP13` enable to the 12 V gate swing |
| R13 | 10 k | pulls Q2 gate to its source → **off by default** |
| R14 | 4.7 k | limits Q3 sink current |
| R15 | 1 k | series into Q3 gate |
| R16 | **100 k** | holds Q3 gate low when the Pico is unpowered — fail-safe: the ECU rail only comes up on an explicit command |
| C3 | 10 nF | with R13, ~100 µs turn-on slope to tame inrush |

### `ecu_current_sense` — total ECU current (U1)
INA226 across RS1, I²C address **0x40** (A0 = A1 = GND). Reads bus voltage and
current for the whole switched rail. `VS` from 3 V3. `ALERT` unused (NC).
**C9 (100 nF)** bypasses `VS` to GND, per the INA226 datasheet's layout
guidance — added late (U1 originally had none, unlike U2/U4 which always had
theirs); tapped off the +3 V3 trunk and the GND pour a few mm south of the
packed U1/U3/RS1/RS2 pocket since there's no free room right at the pins.

### `idle_valve` — real N71 valve as load, low-side current sense (U3)
The bench-mounted real idle-air-control valve plugs into **J2** (JST-XH,
3 A/contact), placed right next to RS2/U3 (not off in the button row) to keep
the valve's drive/return/sense traces short. The ECU's own low-side driver on
VW-23 PWMs it; the bench watches the current.

| ref | part | why |
|-----|---|-----|
| J2 | JST-XH 2-pin | to the real valve; ~1 A average, ~1.8 A peak — within XH rating |
| RS2 | **0.033 Ω** 1 % shunt, 2512 | 0.1 Ω would clip the INA226 above ~0.8 A; 0.033 Ω gives ~60 mV at 1.8 A peak |
| U3 | INA226, address **0x41** (A0 = 3 V3) | low-side sense of the valve current |

RS2 sits truly **in series** between the valve (J2) and VW-23 — not as a
separate tap to GND running in parallel with the ECU's own low-side driver
(the original layout's bug: both paths shared the same GND, so return current
split between RS2 and the ECU's internal switch, and U3 only ever saw whatever
fraction happened through RS2 — understating the real current, worst exactly
when the ECU driver is on). U3's IN+ stays on VW-23's net (the pin that
already had a routed path to J0) and IN− moved to the valve-side node
(`VALVE_RETURN_SENSE`) — current-reading sign is a firmware convention either
way, and keeping IN+ where it was avoided re-routing a long existing run.
**C10 (100 nF)** bypasses `VS`, same reasoning and placement approach as U1's C9.

### `dac_analog_sim` — sensor spoofing (U2)
MCP4728, 4-channel 12-bit I²C DAC, address **0x60**, `~LDAC` low. Each output goes
through a series resistor into the harness:

| DAC out | R | VW pin | simulates | disconnect |
|---|---|---|---|---|
| VOUTA | R2 220 Ω | VW-9 | intake-air temperature (NTC) | U6, GP8 |
| VOUTB | R3 220 Ω | VW-10 | coolant temperature (NTC) | U7, GP9 |
| VOUTC | R4 220 Ω | VW-21 | air-mass meter (LMM) | — |
| VOUTD | R5 **1 k** | VW-2 | lambda / O₂ | U8, GP11 |

**Sensor-fault simulation:** the two NTC channels and the lambda channel each pass
a **TS5A3159A** SPDT analog switch (~1 Ω, SOT-23-6, U6–U8). GPIO high → COM–NO →
sensor connected; GPIO low → COM–NC (open) → the ECU sees an **open sensor** and
should set the corresponding fault code. R22–R24 pull the control lines up so all
three read connected at power-on; C6 decouples the DAC and switches. Lambda's
series R is **1 k** (not 220 Ω) so it looks less like an ideal voltage source to
the ECU's O₂ input. Set MCP4728 channel D to the internal 2.048 V reference for
fine resolution in the 0–1 V lambda window.

### `crank_driver` — crank / Hall signal (Q1)
Open-drain 2N7002 with **RG1 (100 Ω)** gate resistor and **RPU1 (1 k)** pull-up to
the switched 12 V rail. Pico `GP2` toggles it → a clean 12 V square wave on VW-18
for the ECU's engine-speed input. ~12 mA when on. **VW-18 confirmed** by the
user's own working HiL notes: the crank signal needs ≥8–10 V amplitude (5 V is
not enough), which only makes sense pulled up to the 12 V rail as done here —
this also resolves the earlier VW-8-vs-18 ambiguity from public pinout sources
in favour of VW-18.

### `edge_capture` — read the ECU's ignition & injector outputs
The ECU's output pins are pulled up to the Pico's 3 V3 (**R8 10 k** on VW-25
ignition, **R10 1 k** on VW-12 injector) with a **330 Ω** series resistor
(R9 / R11) as an ESD / current guard into the GPIO. `GP14` = ignition,
`GP15` = injector. R10's 1 k on the injector line is validated by the user's own
bench notes: a 10 k pull-up was too weak for the ~2.4 ms idle injector pulse
(didn't fully charge/discharge between cycles); even 2.2 k still showed some
droop, so 1 k here has real margin.

### `knock_sim` — knock-sensor burst generator (U4)
AD9833 DDS on SPI (`GP16` FSYNC / `GP18` SCLK / `GP19` SDATA). **Y1**, a real
4-pin **XO91 25 MHz** active oscillator (not a bare crystal — MCLK is a clock
*input*), feeds MCLK. The output passes an **R12 (200 Ω) + C2 (100 nF)** RC to
**TP1** (signal) and **TP2** (ground) — a defined pair of test points to wire
to the ECU harness's VW-4 (signal) / VW-5 (ground, 2H) via a short external
pigtail, rather than dead-ending at a single pad with no return reference. J0
is already full at 15/15 positions (VW-4/5/7, the knock sensor's real pins,
were never broken out there), so this stays a small standalone tap rather than
expanding J0. A proper 2-pin JST connector (matching J2's style) was tried
first, but this corner of the board is criss-crossed with existing traces on
both layers (`+12V_ECU_SW`, `VW_PIN10/11/12`, `GP8/GP9/GP13/GP26` all thread
through here) — every placement tried for a through-hole 2-pin connector
shorted a different existing net, so two small bare test pads (same
`TestPoint_Pad_D1.5mm` footprint as the original TP1) were used instead; they
fit where the bulkier connector wouldn't. AD9833 `COMP` and `CAP_2V5` are
decoupling-only pins; each gets its own **100 nF cap to AGND (C7, C8)**, per
ADI's recommended application circuit.

### `operator_ui` — local controls
**J3**, a 4-pin header, carries `GND / +3V3 / SCL / SDA` for an I²C OLED
(SSD1306 at 0x3C — no bus conflict with the INA226s or DAC). Check the module's
pin order before wiring. J3 has its own ~40 mm-deep clear band at the bottom of
the board (nothing else placed within it) since a 0.96″ OLED module (~27–33 mm)
plugged in flat would otherwise overhang neighbouring parts. **SW1–SW3** are
momentary buttons to ground on `GP20 / GP21 / GP22` (menu / − / +).

### `debug_test_points` — scope probe points (TP3–TP14)
THT test pads (`TestPoint_THTPad_D1.5mm_Drill0.7mm` — a real 0.7 mm drilled
hole, same as the knock output's TP1/TP2; **not** the bare SMD pad this board
used earlier, corrected after review) on the signals most likely to get
probed while debugging firmware: crank drive (TP3), idle-switch drive (TP4),
ignition/injector capture (TP5/TP6), the SPI bus to the AD9833 (TP7 CS / TP8
SCK / TP9 MOSI), the I²C bus (TP10 SDA / TP11 SCL), the status LED data line
(TP12), and both 12 V rails — sensed (TP13, `+12V_ECU`) and switched (TP14,
`+12V_ECU_SW`). TP3–TP12 sit in the clear margin strip west of the Pico
module (x < 10 mm) rather than near their signal's own Pico pin — the Pico's
real footprint courtyard is a physical keepout once it's soldered down, and
the first placement pass put 10 of these test points *underneath* it,
unreachable with a probe. **+3V3 was deliberately left without a dedicated
point**: it was tried at four different anchor locations (three different
Pico pins, then a decoupling cap elsewhere) and every one routed through the
same congested corridor near the Pico, each time producing a real
clearance/short against unrelated nets. Not worth forcing — +3V3 is already
exposed at many existing pins (R6/R7, C2–C6, any INA226 `VS` pin) if you need
to probe it.

**Resorting TP3–TP12 to declutter (avoid crossing traces)**: the original
placement order didn't match the Pico pins' physical top-to-bottom order,
guaranteeing crossing wires in the west margin. Resorted to
`TP3, TP10, TP11, TP4, TP12, TP9, TP8, TP5, TP6, TP7` (matching pin order) and
ripped up all 10 nets to reroute clean. The user hand-routed 7 of them; the
last 3 (TP9/GP19_SPI_MOSI, TP8/GP18_SPI_SCK, TP7/GP16_SPI_CS — all on U5's
*east* side, the far side of the Pico from the TP margin) needed real
pathfinding, not hand-placement — direct probing confirmed the Pico's pin
column (x≈12.16) has **zero** usable gap anywhere along its length for a
second trace: adjacent pins are 2.54mm apart, and while two bare THT pads
alone would in theory leave a 0.49mm gap at the midpoint, every one of those
gaps is already occupied by some other GPIO's own escape trace by this point
in the board's routing, closing it off entirely. Both TP8 and TP9 had to
detour around the *south* end of the Pico footprint (the only other opening,
confirmed the same way), and since even that detour corridor is only wide
enough for one trace, they needed genuinely different crossing points, not
parallel lanes 0.4mm apart.

Routed with a purpose-built A* pathfinder (0.1mm grid, spatial-bucket-indexed
obstacle lookup for speed, shortcutting the raw grid path down to a handful of
straight segments afterward) rather than more manual attempts, after
Freerouting's auto-router reliably completed in ~3 minutes but then hung
indefinitely in its own route-optimization phase on this exact 10-net batch
(tried 180s/400s/580s timeouts, never produced a `.ses`). Two bugs in the
pathfinder's own clearance model cost real iteration time and are worth
remembering for any future scripted routing here:
1. **Non-circular pads approximated by half-width, not half-diagonal** — a
   1.7×1.7mm square pad modeled as a r=0.85mm circle understates its real
   reach along the diagonal (true corner distance ≈1.2mm), so a track that
   looked clear by ~0.14mm was actually a real DRC short once diagonal
   approach was accounted for.
2. **Hole-to-hole spacing wasn't checked for a net's own via near its own
   pad** — same-net copper can touch/overlap freely for *clearance* purposes,
   but a via's *drill hole* still needs the board's minimum hole-to-hole
   spacing from any other hole, including one on the same net (TestPoint THT
   pad ⌀0.7mm + via drill ⌀0.3mm need ≥0.65mm center-to-center, not just
   >0mm).

### `status_led` — one addressable RGB pixel (D2)
**SK6812** (5050) on a single GPIO (`GP10`), driven by the Pico's PIO. SK6812 is
picked over WS2812B because its data threshold is in spec at 3.3 V — no level
shifter, no 5 V rail, and it frees two GPIOs versus a plain 3-pin RGB LED.
**R17 (330 Ω)** on the data line, **C4 (100 nF)** decoupling. Chain from `DOUT`
to add more pixels. Colour meaning is up to firmware.

### `throttle_switches` — idle-switch emulation
**Corrected by the user's own HiL notes** ("F60 Leerlaufschalter Pin 6 Masse und
Pin 11"): VW-6 is **not** a second switch contact, it's the sensor / idle-switch
**common ground** — wired straight to GND in `main_circuit`. There is only
**one** idle switch, on **VW-11**, which the ECU pulls up internally; closing it
(or here, Q5) pulls VW-11 to VW-6/GND ("Pin 11 auf Pin 6 verbinden für Leerlauf
aktiv"). No full-throttle switch is broken out — the earlier "two switches"
reading of the public pinout tables was wrong. **Q5** (2N7002, open-drain)
emulates the contact under Pico control (`GP6`); **R19 (100 k)** holds the gate
low so it reads "not idle" when the Pico is unpowered.

### `afm_ref_sense` — airflow-pot reference measurement
The airflow-meter potentiometer is read *ratiometrically*: the ECU sources a
reference on VW-17 and reads the wiper on VW-21. Since the bench injects the
wiper voltage with the DAC, firmware needs VW-17's actual level to scale it
correctly — and a drooping VW-17 is itself a useful fault indicator.
**R20 (20 k) / R21 (10 k)** divide VW-17 (~5 V nominal, headroom to ~9 V) into
the Pico's `GP26 / ADC0`; **C5 (100 nF)** filters. Ratio is 1:3 (not the
original 1:2.5) so the stated 9 V worst case lands at 3.0 V — 0.6 V of real
margin below the ADC's absolute-max input rating (unchanged between RP2040 and
RP2350: both clamp to VDDIO + ~0.3 V), instead of landing right on it. Sense-only, ~30 kΩ load on
the ECU's reference.

### Bus-voltage measurement
Both INA226s report **bus voltage** as well as current. **U1**'s VBUS is on the
load side of RS1, so it reads the **ECU supply voltage** directly (minus a
~0.1 V drop across the Q2 switch to VW-14 — correct for in firmware, or move
VBUS to `+12V_ECU_SW` for the exact pin-14 voltage). **U3**'s VBUS is on the
valve supply rail, so it reads the **voltage the idle valve is fed**. No extra
parts — it's an INA226 register read.

### Controller — Raspberry Pi Pico 2 (U5)
Module footprint (castellated + through-hole). All 8 GND pins tied to the plane.
`RUN` and `ADC_VREF` to 3 V3, `AGND` to GND. `VBUS / VSYS / 3V3_EN / SWCLK /
SWDIO` left unconnected — the Pico is powered and programmed over its own USB.
I²C pull-ups **R6 / R7 (4.7 k)** on `GP4` (SDA) / `GP5` (SCL).

**Socketed, not soldered directly** (per the user's own assembly report,
2026-10-08): solder two 1×20 + a short 1×3 female header strip into U5's
existing through-hole pads instead of the module's own leads, so the Pico 2
can be swapped without desoldering. The footprint (`RPi_Pico_SMD_TH`) was
designed for direct solder, either castellated-edge SMD or through-hole, not
specifically for header posts — but its pads happen to already be at the
genuine 2.54 mm pitch and 17.78 mm row spacing, with a 1.02 mm drill that's
close to (if a little tight for) a standard header pin. This works on the
already-fabbed board as a practical retrofit; **test-fit one header pin in a
spare hole first**, since the hole size was never dimensioned for this use.
No footprint/board change was needed for it. See `BOM.md` for the header
part.

## GPIO map

| GP | function |
|----|---|
| 2  | crank / Hall drive → Q1 |
| 4  | I²C0 SDA |
| 5  | I²C0 SCL |
| 6  | idle switch (VW-11) → Q5 — high = idle active |
| 7  | free (VW-6 turned out to be ground, not a 2nd switch) |
| 8  | intake-air-temp sensor connect (U6) — low = open-circuit |
| 9  | coolant-temp sensor connect (U7) — low = open-circuit |
| 10 | SK6812 status LED (PIO) |
| 11 | lambda sensor connect (U8) — low = open-circuit |
| 13 | ECU power-switch enable (high = ECU on) |
| 14 | ignition edge capture (in) |
| 15 | injector edge capture (in) |
| 16 | AD9833 FSYNC |
| 18 | AD9833 SCLK |
| 19 | AD9833 SDATA |
| 20 / 21 / 22 | buttons: menu / − / + |
| 26 / ADC0 | airflow-pot reference (VW-17), divided |

## I²C bus (GP4/GP5, 3 V3, 4.7 k pull-ups)

| addr | device | reads |
|---|---|---|
| 0x3C | OLED (external, on J3) | — |
| 0x40 | U1 INA226 | total ECU current **+ ECU supply voltage** |
| 0x41 | U3 INA226 | idle-valve current **+ valve supply voltage** |
| 0x60 | U2 MCP4728 | (sensor-sim DAC, write-only) |

## VW harness (J0, 15 of the 25 ECU pins)

Verified against the cabby-info.com Digifant II 25-pin reference (VW Cabriolet,
engine 2H, ECU 037906022xx) **and the user's own hands-on Digifant HiL notes**
(2024–2026 bench work on real ECUs) — the latter settled two points the public
pinout tables left ambiguous. ✅ = confirmed, ⚠️ = see notes.

| VW pin | function | bench use | |
|---|---|---|---|
| 2  | oxygen sensor input | lambda sim out (DAC → R5 → U8) | ✅ |
| 6  | sensor / idle-switch common ground | wired to GND | ✅ own HiL notes ("F60 ... Pin 6 Masse") |
| 9  | intake-air-temp sensor | NTC air sim (DAC → R2 → U6) | ✅ |
| 10 | coolant-temp sensor | NTC water sim (DAC → R3 → U7) | ✅ |
| 11 | idle switch (single contact, pulls to VW-6/GND) | Q5 open-drain to GND | ✅ own HiL notes |
| 12 | injector drive (ECU output) | edge capture → GP15 | ✅ |
| 13 | ground (battery −) | GND | ✅ |
| 14 | ECU main power (relay T87) | switched +12 V rail | ✅ |
| 17 | airflow-pot reference (ECU source, ~5 V) | divided → GP26/ADC0 | ✅ sense-only, confirmed by own HiL notes |
| 18 | Hall sender / crank signal | crank square wave (Q1) | ✅ own HiL notes: needs ≥8–10 V amplitude, resolves the earlier VW-8-vs-18 ambiguity |
| 19 | ground (engine / sensors) | GND | ✅ |
| 21 | airflow-pot wiper (ECU input) | LMM sim out (DAC → R4) | ✅ |
| 22 | idle-valve feed | switched +12 V rail | ✅ |
| 23 | idle-valve return (ECU PWM, low-side) | through RS2, sensed by U3 | ✅ |
| 25 | to ignition control unit (ECU output) | edge capture → GP14 | ✅ |

Not broken out (add terminals if needed): VW-1 (start/circuit 50), 3 (fuel-pump
relay, switches ground — a nice future diagnostic LED per the user's own HiL:
"Fuelpump Out BLUE, Pin 3 Masse geschalten"), 4/5/7 (knock sensor + / ground /
shield), 8, 16 (A/C), 20 (MIL).

## Schematic readability (open, 2026-10-08)

**Confirmed unreadable, per a real assembly report** — rendered the current
flat single-sheet schematic to check: nearly every connection is drawn as a
disconnected net-label flag rather than a real wire (circuit-synth's flat
placement output), so there's no signal flow to follow visually at all, just
scattered text pairs to match by eye. No fix attempted yet; this needs its
own dedicated, iteratively-verified session, not a rushed pass, because:
- The obvious fix (hierarchical sheets, grouping by function) runs straight
  into circuit-synth's hierarchical label/pin bugs (see `UPSTREAM_BUGS.md`,
  issue #619 and the sheet-pin investigation) — real electrical risk if
  applied without an ERC check after every change.
- A safer flat-sheet reorganization (visually separated, labelled zones per
  function; real wires for short local connections, net labels only for
  genuinely long-distance ones) is still a large, component-by-component
  manual job best done with its own ERC-verified passes, not scripted blind.

## Board

144 × 150 mm, 2-layer, 4 × M3 corner holes (non-plated, 4.5 mm inset) — plain
clearance holes, no threads cut into the board itself; add your own M3
standoffs and screws (see `BOM.md`). No board change needed, they were
already there.

**Silkscreen fixes (2026-10-08, from a real assembly report — PCB-level, so
only on the *next* fab run, not retrofittable to a board already printed):**
- **U6/U7/U8 (TS5A3159A, SOT-23-6) were missing their pin-1 marker.** The
  stock `Package_TO_SOT_SMD:SOT-23-6` footprint has one (a small silkscreen
  triangle); it was silently dropped when circuit-synth embedded its own
  simplified copy of the footprint into the board, a known failure mode for
  this tool (see `UPSTREAM_BUGS.md`). Restored directly in the `.kicad_pcb`
  via a `pcbnew` script (not a full regeneration, which would also discard
  the hand-routing and GND pour). **On the board you already have:** the
  physical chip's own package marking (per TI's datasheet) is the reliable
  way to find pin 1, not the PCB silkscreen.
- **J0's per-pin function labels (`VW-25`, `GND`, …) sat on the side the
  harness bundle lies across once wired**, becoming unreadable after
  installation. Moved to the other side of the connector, clear of the
  R21–R23/U6–U8 row beside it (one label, `+12V SW` at pin 8, shortened to
  `+12VSW` and set 0.85 mm instead of 1.0 mm tall — the only spot too tight
  for the full-size text). **On the board you already have:** use the VW
  harness pin map above instead.
- **J3 had no per-pin labels at all**, just the bare `J3` reference. Added
  `GND`/`3V3`/`SCL`/`SDA` next to each pad (top to bottom, matching the
  schematic). **On the board you already have:** pin 1 (top) is `GND`.

All three checked DRC-clean (same pre-existing cosmetic violation count, zero
new) and confirmed by rendering the actual silkscreen layer before committing.

Was 144 × 169 mm — trimmed 19mm off the bottom, which was entirely empty (bare
GND pour, no components or traces below PROTO1/J3 at y≈135 until the old
mounting holes at y=164.5). H3/H4 moved up to y=145.5 to keep the same
4.5mm hole-to-edge margin as H1/H2; GND zone outline and fill updated to
match, verified DRC-clean (99 violations, same pre-existing cosmetic set,
zero new issues). U5's USB
end has a 23 mm clear band above it toward J1 (was only ~7.5 mm, X-overlapping —
a plugged-in USB cable would have fouled J1's screw terminal). J3 (OLED
header) has its own ~40 mm clear band at the bottom, isolated from every other
part, so a 0.96″ module can plug in flat without overhanging D2/J2. General
passives are 0805 for hand assembly.

**PROTO1** — a 12×16 grid of isolated 1.6 mm/0.8 mm-drill THT pads (2.54 mm /
0.1″ pitch, ~30×38 mm) in the empty area bottom-right of J0, below where J0's
own footprint ends (y > 92 mm) and clear of the H4 mounting hole's keepout.
Perfboard-style: every pad is its own net (unconnected), solder in whatever
you need for one-off additions or bodge wires. PCB-only, like the mounting
holes — no schematic symbol, since it's not part of the actual circuit
(`extra_footprint` is the one expected DRC warning this produces, matching
what H1–H4 would also show if their `exclude_from_bom`/`exclude_from_pos_files`
attributes didn't already suppress it).

**Netclasses** (2026-09-11, following a deep layout review): `Power` (0.8 mm
track — VIN_12V, +12V_PROT, +12V_POST_D1, +12V_ECU, +12V_ECU_SW,
VW_PIN23_VALVE_RETURN) and `Gnd` (0.5 mm track — GND) are now real KiCad
netclasses in the project, not just a one-off width baked into the autorouter
session — any further hand-routing on these nets inherits the right width.
Clearance stays 0.15 mm across all classes; some MSOP-10/SOT-23-6 pads are only
~0.15 mm apart, so a tighter class clearance fails DRC against the part's own
adjacent pins.

**GND** was previously an ad-hoc daisy chain that split into 4 disconnected
islands (the whole operator-UI cluster — buttons, status LED, OLED header —
had no ground return except through the Pico module's internal plane) and
physically routed the ECU's full return current *through* U1/U3's ground pads,
corrupting the current-sense reference. It's ripped up and re-routed as part
of the normal autoroute pass now, giving one connected net with sane 0.5 mm
copper. A literal B.Cu ground pour is still worth adding by hand in the KiCad
GUI (Draw Filled Zone, B.Cu, GND net) once you're routing — scripted pour +
via-stitching attempts kept landing on other nets' copper in this dense a
board and weren't worth fighting further.

**Kelvin sensing**: U1/U3's IN+/IN− now get short, dedicated 0.2 mm traces
straight to RS1/RS2's pads instead of being unrouted or (U3's case) sharing
18.7 mm of the general GND daisy chain. This is genuinely the tightest spot on
the board — 0.5 mm-pitch MSOP-10 pins right next to a 2512 shunt — and a
handful of DRC items (a couple of clearance/crossing flags right around
U1/U3/RS1/RS2) are left for a quick manual nudge in KiCad's interactive
router, same as the historical INA226-fanout items.

**+12V_ECU_SW** no longer detours 135 mm through J2 with two extra vias — it's
ripped up and re-routed directly from Q2's tab as part of the same autoroute
pass, ~65 mm point-to-point.

**Thermal copper** added for D1 and Q2 (F.Cu zones, `ZONE_CONNECTION_FULL`
so they're solidly tied to the pad, not thermal-relief spokes). D1 got the
generous treatment (~7mm×9mm and ~5mm×9mm either side of its two pads) since
it's the documented real risk — F1 and RS1 sit on the same nets as D1's two
pads with open board space between them, so each pour spans pad-to-neighbor
with room to spare. Verified electrically connected via
`GetConnectivity().GetConnectedItems()`, not just visually overlapping
(a previous scripted attempt landed disconnected from the pad — this time
filled only the two/three new zones directly, `ZONE_FILLER.Fill([zone,
...])`, rather than a whole-board refill, and confirmed connectivity before
accepting it). Q2's pour is much smaller (~2.7mm×2.8mm) — the DPAK tab area is
boxed in on every side by other nets' traces (Q2_GATE, +12V_ECU,
+12V_POST_D1) with almost no clear board space, so this is a modest
supplement on top of the footprint's own 5-pad thermal tab design (which is
the primary heatsinking mechanism for a TO-252 part) rather than a real pour.

## Ideas from the user's own HiL notes, not yet in this design

- **Per-signal indicator LEDs / test points.** The user's earlier hand-built HiL
  had a labelled LED + test point on each key signal (600 Ω series each): power
  in (green), Hall/crank in (green), Hall supply out (green), ignition out
  (red), injector out (blue), idle-valve out (yellow), fuel-pump out (blue).
  This board currently has one shared status LED (D2) instead — cheap to add
  discrete ones later if per-signal visibility is worth the board space.
- **VW-3 (fuel pump relay) monitoring** — not broken out here; easy add if
  wanted, per the note above.

## Digifant 1 (G40/G60) — explicitly out of scope for this board

This board targets **Digifant II (2H)** only. Per the user's own repair notes,
Digifant I (G40/G60) has real, documented differences on this same connector —
do not assume pin-compatibility if a G40/G60 variant is ever built:
- **VW-5** is knock-sensor ground on 2H, but a **CO potentiometer** (0–3 kΩ,
  ~900 Ω nominal) on G40/G60.
- **Ignition output is inverted on G60** (its output stage is already inside the
  ECU) and wants a stronger pull-up than 2H.
- Fault-code readout differs too (K-Line on G40 vs. a blink-code method on G60) —
  irrelevant to this board's scope but relevant to a future shared bench.

A G40/G60 variant would need its own adapter harness (and probably a switched
pull-up / polarity option), not just different firmware on this board.

## Known open points

- ~~TP12/GND "imprecisely located" shorting_items~~ — turned out to have a
  real root cause, found and fixed: every footprint cloned via
  `pcbnew.FOOTPRINT(template)` this session (C7/C8, then all of TP1–TP14)
  inherited the **same UUID as the template**, since that constructor doesn't
  auto-generate a new one. All 14 TP footprints (and C7/C8) shared one UUID
  each with their siblings — which doesn't break connectivity, but corrupts
  DRC's item-identity tracking, so violations got reported against whichever
  sibling happened to be resolved first, at wildly wrong distances (one
  report cited two footprints 70mm apart as a "courtyard overlap"). Fixed
  with `footprint.ResetUuid()` (and each pad's) on every affected clone.
  **If you ever see a DRC violation citing two items an implausible distance
  apart, check for duplicate UUIDs before trusting the reported pairing** —
  `pcbnew.FOOTPRINT(existing_object)` needs an explicit `ResetUuid()` call
  after cloning, every time.
- ~~DRC violations around U1/U3/RS1/RS2~~ — fixed by hand in KiCad's
  interactive router; DRC is now clean (0 unconnected/shorts/clearance).
- ~~GND ground pour~~ — added (B.Cu). One pad (U5 GND pad 42) has only 1
  thermal-relief spoke into it instead of the zone's preferred 2
  (`starved_thermal` warning) — connected fine, optionally strengthen the
  spoke count in zone properties. D1/Q2 thermal copper still optional.
- ~~AD9833 knock output has no defined path to the ECU~~ — now reaches a
  defined pair of test points (TP1 signal, TP2 ground) for an external pigtail
  to VW-4/VW-5. See `knock_sim` above for why it's test points and not a
  proper connector.
- ~~RS2 gave the idle valve a permanent parallel-to-GND path~~ — fixed: RS2 is
  now truly in series between J2 and VW-23 (`VALVE_RETURN_SENSE` on the valve
  side, `VW_PIN23_VALVE_RETURN` on the ECU side). One new tight spot from this
  fix: U3 pin 9's own local GND-mesh neighbours (pin 1/pin 7's path back to the
  wider ground network) sit right where U3 pin 9's new sense connection also
  needs to run — 2 `shorting_items` confined to that one pocket. Tried by hand
  and via Freerouting from several angles; every attempt converges on the same
  conflict, meaning it's genuinely as tight as the U1/U3/RS1/RS2 pocket itself
  — same quick manual-nudge treatment.
- ~~AD9833 `COMP` / `CAP_2V5` decoupling caps~~ — added (C7, C8), fully routed;
  C8's GND connection (previously a short unrouted ratsnest line) got picked
  up for free by the Freerouting pass used for the RS2 fix above.

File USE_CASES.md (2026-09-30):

# Use-case verification matrix

Software-engineering approach applied to the hardware: every real bench
operation is a "requirement," traced through the actual schematic to concrete
numbers (voltage, current, timing, GPIO budget), the way a test matrix traces
requirements to acceptance tests. ✅ verified against real numbers below, ⚠️
works but with a caveat worth knowing, ❌ genuine gap.

This complements DESIGN.md's "Known open points" rather than duplicating it —
where a use case exposes one of those points, it's cited; three items below
were **new findings** from this pass, not previously written down (one, the
VW-17 divider, has since been fixed).

## Power / sequencing

| Use case | Path | Status | Verification |
|---|---|---|---|
| Cold-boot the ECU on firmware command | `ecu_power_switch` (Q2/Q3/R13-16/C3) | ✅ | Q3 ON drives Q2 gate to ~3.84 V (12 V × R14/(R13+R14)), Vgs ≈ −8.2 V — comfortably past a P-FET's few-volt Vgs(th). R13·C3 ≈ 10 kΩ × 10 nF = 100 µs turn-on slope, tames inrush. |
| Fail-safe OFF when Pico is unpowered/USB unplugged | R13 (gate→source), R16 (Q3 gate→GND) | ✅ | Both pull-downs reference the 12 V rail or GND directly, not +3V3 — stay valid with zero board logic power. Q2 cannot turn on without an explicit GP13 command, which itself requires +3V3 (Pico running) to issue — so "12 V applied before USB" is inherently safe: by the time the rail *could* come up, +3V3 (and therefore the DAC/sensor-sim outputs) is already live too. |
| Overcurrent shutdown | U1 (INA226 on RS1) → firmware → GP13 | ⚠️ | Hardware gives firmware everything needed (continuous current read, rail cutoff); the trip threshold/response itself is a firmware policy, not verifiable from the board alone. |
| Sustained near-max-current operation (ECU + valve inrush, ~2.5 A) | F1, D1, RS1 | ⚠️ **ties to an existing open point** | RS1 dissipates only ~0.13 W (2.5 A² × 0.02 Ω) — fine. **D1 (SS54) dissipates ~1.25 W at 2.5 A** (≈0.5 V forward drop) in an SMC package with no thermal copper added yet (DESIGN.md's open point) — this is the concrete consequence of that gap: without the copper pour, D1 running near the fuse limit for any length of time is a real thermal risk, not just a nice-to-have. |

## ECU current/voltage sensing

| Use case | Path | Status | Verification |
|---|---|---|---|
| Measure total ECU current, 0–2.5 A | U1 + RS1 (0.02 Ω) | ✅ | INA226 PGA range ±81.92 mV / 0.02 Ω = ±4.10 A — 64% headroom over the 2.5 A worst case. |
| Measure ECU supply voltage | U1 VBUS (on `+12V_ECU`) | ⚠️ | Reads upstream of Q2, so it's off by the switch's ~0.1 V drop from the actual VW-14 voltage — documented already, just firmware-correctable. |
| Measure idle-valve current, 0–1.8 A peak | U3 + RS2 (0.033 Ω) | ⚠️ **new finding** | INA226 range ±81.92 mV / 0.033 Ω = ±2.48 A — only ~38% headroom over the 1.8 A nominal peak. A **valve fault (stalled/locked coil, higher inrush)** — exactly the condition you'd most want to *see* — could clip this reading. Worth keeping in mind if fault-injection testing on the valve itself is ever a goal; not a problem for normal PWM operation. |
| Observe the ECU's own idle-valve PWM waveform cleanly | RS2, U3, VW-23 | ✅ **fixed** | RS2 was a permanent parallel path to GND alongside the ECU's own VW-23 driver, splitting the return current between the two and understating U3's reading. Now truly in series (100% of the current crosses RS2 before reaching VW-23) — U3 reads the real total and the ECU's own drive is undisturbed except RS2's own ~60mV drop. |
| Measure idle-valve supply voltage | U3 VBUS (on switched rail) | ✅ | Independent of the PWM node, reads what the valve is actually fed. |

## Sensor simulation

| Use case | Path | Status | Verification |
|---|---|---|---|
| Simulate intake-air-temp (NTC) value | U2 VOUTA → R2 (220 Ω) → VW-9 | ✅ | 12-bit DAC, 0–VDD range through a low-impedance series R — no loading concern against a typical ECU NTC input (MΩ-class). |
| Simulate coolant-temp (NTC) value | U2 VOUTB → R3 (220 Ω) → VW-10 | ✅ | Same as above. |
| Simulate airflow-meter (LMM) output | U2 VOUTC → R4 (220 Ω) → VW-21 | ✅ | Same; no fault-injection switch on this channel (by design — LMM doesn't have a documented open-sensor fault mode in scope here). |
| Simulate lambda/O₂ voltage | U2 VOUTD → R5 (1 kΩ) → VW-2 | ✅ | 1 kΩ (not 220 Ω) specifically so the source doesn't look like an ideal voltage source to the ECU's O₂ input — matches a real sensor's output impedance better. |
| Inject open-sensor fault: air, coolant, lambda | U6/U7/U8 (TS5A3159A) | ✅ | GPIO low → COM floats (NC pin left open) → ECU sees a genuine open circuit, not just a forced voltage — this is what actually exercises the ECU's fault-detection path, not just a wrong reading. |
| Sensors read "connected" at power-on (no false fault before firmware runs) | R22–R24 (100 kΩ pull-ups to +3V3) | ✅ | But **contingent on +3V3 being present** — see the sequencing note above; the whole DAC/switch subsystem is unpowered without it anyway, so there's no window where a false "open" fault could appear without also having no signal at all. |
| Read the airflow-pot reference (VW-17) to scale the injected wiper voltage | R20/R21 divider → GP26/ADC0 | ✅ **fixed** | R20 was 15 k (ratio 0.4, worst case 9 V → 3.6 V — at the ADC's absolute-max rating, zero margin; the same limit on RP2040 and RP2350). Now 20 k (ratio 0.333): 9 V → 3.0 V, 0.6 V of real margin; nominal 5 V → 1.67 V, still comfortably mid-range. |

## Digital I/O emulation

| Use case | Path | Status | Verification |
|---|---|---|---|
| Drive crank/Hall signal at cranking-to-redline frequencies | Q1 (open-drain) + RPU1 (1 kΩ→12 V) | ✅ | RC-limited rise time is ~1 kΩ × (trace+input capacitance, tens of pF) ≈ tens of ns — no issue up into the MHz range, far beyond any real crank signal frequency (Hz–low kHz). Amplitude ≥8–10 V confirmed against the user's own HiL notes. |
| Idle-switch emulation (open/closed) | Q5 (open-drain) + R19 (100 kΩ→GND) | ✅ | Fails safe to "not idle" (open) with no board power, same reasoning as the ECU power switch. |
| Capture ignition edges | R8 (10 kΩ pull-up) + R9 (330 Ω series) → GP14 | ✅ | 0.32 mA load on the ECU's output when pulled low — negligible burden. |
| Capture injector edges, including the ~2.4 ms idle pulse | R10 (1 kΩ) + R11 (330 Ω) → GP15 | ✅ | Already bench-validated by the user (10 kΩ too weak, even 2.2 kΩ marginal) — 1 kΩ has real margin. |
| Measure ignition angle | Q1 crank drive (GP2) + R8/R9 ignition capture (GP14) | ✅ (firmware) | The bench *generates* the crank signal itself, so firmware already has an exact timestamp for every crank edge — no separate crank-sensing path needed. Angle = time from that known crank-edge timestamp to the captured ignition-edge timestamp, converted with the RPM the bench is already simulating. R9's 330 Ω + GPIO input capacitance adds tens of ns of propagation delay — negligible next to one crank-degree (27.8 µs at 6000 RPM). This gives angle *relative to the bench's own injected trigger edge*; an absolute "degrees BTDC" figure additionally needs Digifant-2's real trigger-wheel convention, a calibration/firmware detail, not a hardware one. |
| Generate a knock-sensor burst (5–15 kHz typical resonant range) | U4 (AD9833) + Y1 | ✅ **fixed** | AD9833 covers that range trivially (up to ~12.5 MHz max). Output now reaches a defined pair of test points (TP1 signal, TP2 ground) for a pigtail to VW-4/VW-5, instead of dead-ending with no return reference. |
| Local UI: menu/±  buttons | SW1–SW3 → GND | ⚠️ | No external pull-up in hardware — relies on firmware enabling the RP2350's internal pull-ups. Standard practice, just a firmware dependency to remember, not a board defect. |
| I²C bus: OLED + both INA226s + DAC coexist | 0x3C / 0x40 / 0x41 / 0x60, shared SDA/SCL | ✅ | No address collisions. 4.7 kΩ pull-ups are a normal Fast-Mode (400 kHz) value for a short on-board bus with this few devices. |
| GPIO budget for the two "not yet in this design" ideas (per-signal LEDs, fuel-pump monitor) | Pico GPIO map | ✅ | 8 GPIOs free (0, 1, 3, 7, 12, 17, 27, 28) — plenty of headroom if those get added later. |

## Explicitly out of scope (verified as correctly excluded, not gaps)

| Use case | Why it's out of scope |
|---|---|
| Digifant I (G40/G60) compatibility | Real, documented pin differences (VW-5 knock-gnd vs. CO-pot, inverted G60 ignition polarity) — DESIGN.md already states a variant needs its own harness/board revision, not firmware. |
| EPROM emulator / address tracing | Separate future board by design; this one is signal-sim + capture only. |

## Summary: what to act on before you'd call every use case covered

1. ~~**VW-17 divider headroom**~~ — fixed (R20 15k→20k).
2. ~~**RS2's shared ground path**~~ — fixed: truly in series now, not a parallel tap to GND.
3. ~~**AD9833→ECU coupling**~~ — fixed: TP1/TP2 give it a defined external path.
4. **D1 thermal copper** — already on the to-do list, but now tied to a specific consequence: don't run sustained near-3 A tests until it's added.
5. Everything else in this matrix is either ✅ verified with real numbers, or an inherent/expected limitation (average-current sensing on a PWM node, firmware-side pull-ups, firmware-defined trip thresholds) rather than something the hardware needs to change for.

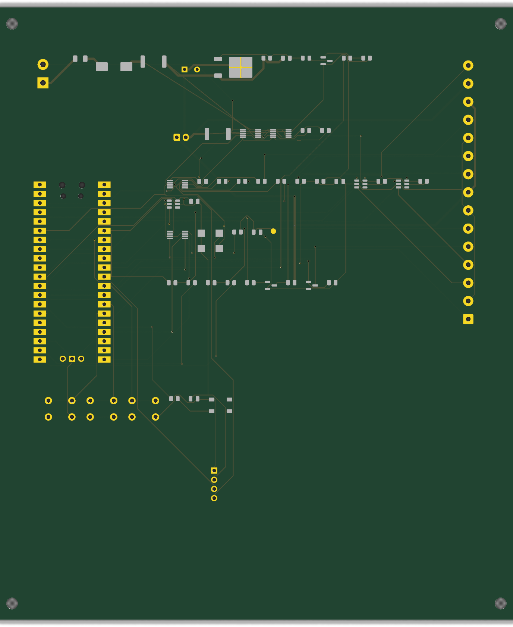
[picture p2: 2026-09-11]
board/board_top.png

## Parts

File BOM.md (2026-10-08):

# Bill of Materials — Mouser sourcing

Researched against mouser.com (2026-09-12). **Confidence matters here — read it per row.**
"Verified" means an actual Mouser product page was found for that exact part.
"Pattern-matched" means it's the same manufacturer part-numbering family as a
verified sibling value (e.g. Yageo's `RC0805FR-07<value>L` resistors — five
other values in this exact series were independently verified on Mouser, so
the same convention for these mid-values is reliable but wasn't individually
page-confirmed). "Could not confirm" means: **do not order this part number —
it may not exist.** Search Mouser yourself or use an alternate distributor.

Also see [`board/bom_output/bom.html`](board/bom_output/bom.html) for the
interactive per-footprint BOM (no Mouser data, but useful to see where each
part sits on the board).

**2026-10-08, cross-checked against a real assembly report:** `mouser_cart.csv`
(the actual order file) had never included R9/R11/R17 (330Ω), R12 (200Ω) or
RG1 (100Ω) — present in this table since the start, but missed when the cart
was built, so they were never actually ordered. Fixed now; order these five
separately if you've already placed the original cart. U1/U3 (qty 2 INA226)
and U4 (AD9833) are, and have been since the 2026-09-20 correction pass,
correct in `mouser_cart.csv` — if your kit is short on these, the order was
likely placed from an older snapshot; check your own Mouser order history
against the current file rather than re-ordering blind.

| Ref(s) | Qty | Description | Mfr / Mfr P/N | Mouser P/N | Confidence |
|---|---|---|---|---|---|
| U5 | 1 | Raspberry Pi Pico 2 (RP2350, THT/castellated) | Raspberry Pi / SC1631 | [SC1631](https://www.mouser.com/en/ProductDetail/Raspberry-Pi/SC1631) | Mfr P/N confirmed against Digikey's listing (SC1631 = plain Pico 2, no wireless -- SC1632/3/4 are the H/W/WH variants); Mouser's own page timed out twice when checked automatically, so check it live before ordering. **The originally-ordered SC0915 (RP2040 Pico) is not used here anymore -- it's now a spare, a Pico 2 needs to be ordered separately.** |
| U1, U3 | 2 | INA226 current/power monitor, MSOP-10 | TI / INA226AIDGST | [INA226AIDGST](https://www.mouser.com/en/ProductDetail/Texas-Instruments/INA226AIDGST) | Swapped to the `T` suffix (small reel, ~250 units) instead of `R` (standard reel, ~2500) — same die/package/pinout, just a smaller reel size that makes more sense for a qty-2 order. **RS Components alternative: RS 742-2889**, confirmed across several regional RS sites. |
| U2 | 1 | MCP4728 quad 12-bit DAC, MSOP-10 | Microchip / MCP4728-E/UN | [MCP4728-E-UN](https://www.mouser.com/ProductDetail/Microchip-Technology/MCP4728-E-UN) | Verified |
| U4 | 1 | AD9833 DDS waveform generator, MSOP-10 | Analog Devices / AD9833BRMZ-REEL7 | [AD9833BRMZ-REEL7](https://www.mouser.com/en/ProductDetail/Analog-Devices/AD9833BRMZ-REEL7) | Corrected by the user while ordering — plain AD9833BRMZ isn't orderable, needs the -REEL7 tape-and-reel suffix (same die, just packaging). **RS Components alternative: RS 183-2180** — RS sells the plain `AD9833BRMZ` (no reel suffix needed), confirmed at £10.84/unit (UK). |
| U6, U7, U8 | 3 | TS5A3159A SPDT analog switch, SOT-23-6 | TI / TS5A3159ADBVR | [TS5A3159ADBVR](https://www.mouser.com/ProductDetail/Texas-Instruments/TS5A3159ADBVR) | Verified — **but flagged as possibly EOL at TI in search results; confirm current lifecycle/stock before ordering qty 3** |
| RS1 | 1 | 0.02Ω 1% current-sense shunt, 2512 | Bourns / CRA2512-FZ-R020ELF | [CRA2512-FZ-R020ELF](https://www.mouser.com/ProductDetail/Bourns/CRA2512-FZ-R020ELF) | Verified |
| RS2 | 1 | 0.033Ω 1% current-sense shunt, 2512 | Vishay Dale / WSL2512R0330FEA | [71-WSL2512R0330FEA](https://www.mouser.com/ProductDetail/Vishay-Dale/WSL2512R0330FEA) | Found by the user — the originally-listed Bourns `CRA2512-FZ-R033ELF` exists on Mouser (652-) but shows 0 stock; this Vishay WSL2512 part is the same value/package and in stock. |
| Q2 | 1 | P-channel MOSFET, DPAK, ≤-30V, ≥5A (ECU high-side switch) | Vishay / SUD50P06-15-GE3 | [SUD50P06-15-GE3](https://www.mouser.com/ProductDetail/Vishay-Semiconductors/SUD50P06-15-GE3) | Verified — spec is well over-built (-60V/-50A) for a real, exact-package match; fine to use, or substitute a tighter-spec DPAK P-FET if you prefer |
| Q1, Q3, Q5 | 3 | 2N7002 N-MOSFET, SOT-23 | onsemi / 2N7002 | [512-2N7002](https://www.mouser.com/ProductDetail/onsemi/2N7002) | Found by the user on Mouser |
| D1 | 1 | SS54 Schottky diode, SMC/DO-214AB, 5A/40V | Diodes Inc. / SS54FSH | [821-SS54FSH](https://www.mouser.com/ProductDetail/Diodes-Incorporated/SS54FSH) | Found by the user on Mouser — Diodes Inc.'s SS54 in the same SMC package, confirms the originally-listed Comchip part just wasn't the right distributor. |
| D2 | 1 | SK6812 addressable RGB LED, PLCC-4, 5.0×5.0mm, P3.2mm pad pitch | OPSCO / SK6812 | [LCSC C5378720](https://www.lcsc.com/product-detail/C5378720.html) | **Confirmed: not stocked on Mouser.** Best lead found: OPSCO's plain SK6812 (not RGBW) on LCSC, C5378720, 4-pin SMD-4P, in stock. Its listed body is 5.4×5.0mm vs our footprint's 5.0×5.0mm — **verify the 3.2mm pad pitch against its datasheet before ordering**; PLCC-4 SK6812 clones commonly share pad pitch despite small body differences, but this wasn't independently confirmed. Also usable: AliExpress or Adafruit (search "SK6812 5050 RGB") — **not** SK6812MINI/MINI-E (3.5mm) or 2020/EC (2mm), which don't fit the footprint, and **not** RGBW (fits mechanically, but is a 32-bit-per-pixel format the firmware would need to handle — Adafruit's own SK6812 boards are RGBW). WS2812B 5050 is the usual drop-in fallback if SK6812 can't be sourced — check pin 1 against its datasheet before soldering. Note: D2 runs from +3V3, below the typical SK6812 VDD spec (~3.5–5.3V); usually still works, blue/green may be dimmer. **RS Components does not have a usable match: their own SK6812 (RS 1808086) is a 3535 package, confirmed too small for this 5050/PLCC-4 footprint.** |
| F1 | 1 | 3A fuse, 1206/3216 SMD | Bel Fuse / TR/3216FF3-R | [504-TR/3216FF3-R](https://www.mouser.com/ProductDetail/Bel-Fuse/TR-3216FF3-R) | Found by the user on Mouser — Bel's naming embeds the rating (FF3 = 3A fast-acting) |
| C1 | 1 | 100µF/25V radial electrolytic, 8mm dia., 3.5mm pitch | Panasonic / ESH107M035AG3AA | [80-ESH107M035AG3AA](https://www.mouser.com/ProductDetail/Panasonic/ESH107M035AG3AA) | Found by the user on Mouser — decodes to 100µF/35V (not 25V as designed, but higher voltage rating is a safe substitute, pure margin upgrade) |
| J1 | 1 | 2-pos 5.08mm PCB screw terminal, THT | Phoenix Contact / 1935161 | [1935161](https://www.mouser.com/ProductDetail/Phoenix-Contact/1935161) | Best match, not exact — this Phoenix part is a **fixed** 5.00mm block; the board footprint (`TerminalBlock_bornier-2_P5.08mm`) implies pluggable. Mechanically close (0.08mm off pitch), functionally fine, but check fit before ordering many. |
| J0 | 1 | 15-pos 5.00mm screw terminal, THT | Molex / 39543-0015 | [39543-0015](https://www.mouser.com/ProductDetail/Molex/39543-0015) | Found by the user on Mouser — confirmed 15 positions / 5.00mm pitch (matches the `MX126-5.0-15P` footprint exactly). Not confirmed pluggable vs. fixed one-piece style; either works mechanically/electrically, fixed just loses the unplug-the-whole-harness convenience. |
| J2 | 1 | JST XH 2-pos, 2.50mm pitch, vertical THT header | JST / B2B-XH-A(LF)(SN) | [B2B-XH-ALFSN](https://www.mouser.com/ProductDetail/JST-Commercial/B2B-XH-ALFSN) | Verified — two very similar part numbers turned up (`B2B-XH-ALFSN` and `B2B-XH-2LFSN`); double-check the page shows 2-position before ordering |
| — | 1 | J2's mating housing: JST XH 2-pos female, 2.50mm pitch | JST / XHP-2 | [XHP-2](https://www.mouser.com/es/ProductDetail/JST-Commercial/XHP-2) | Was missing from the BOM entirely — needed to actually connect the idle valve to J2. **Crimp-only** (needs a JST crimp tool for a reliable joint on the valve's ~1.8A peak PWM current); a pre-crimped JST-XH 2-pin pigtail cable (Amazon/eBay/ProtoSupplies, not Mouser) is the practical no-tooling alternative. |
| — | 2 | Female crimp contact for the above | JST / SXH-001T-P0.6 | [306-SXH-001T-P0.6](https://www.mouser.com/ProductDetail/JST-Commercial/SXH-001T-P0.6) | Verified, in stock, $0.12/unit. One per pin. |
| J3 | 1 | 4-pos 2.54mm vertical pin header, THT, male | Samtec / TSW-104-07-G-S | [TSW-104-07-G-S](https://www.mouser.com/ProductDetail/Samtec/TSW-104-07-G-S) | Verified — this is the gold-plated variant (pricier); cheaper tin-plated 4-pos headers exist in the same Mouser category if cost matters and gold plating isn't needed |
| TP1–TP14 | 14 | Test point, THT (substitute for a bare 1.5mm pad) | Keystone Electronics / 5011 | [534-5011](https://www.mouser.com/ProductDetail/Keystone-Electronics/5011) | Corrected by the user while ordering — original entry (5010) was wrong, real part/Mouser SKU is 5011 (Mouser prefix 534-). Mouser doesn't sell bare test-point pads, this is the standard THT substitute. TP1/TP2 = knock signal/ground (VW-4/VW-5); TP3–TP14 = scope-probe points on key GPIO signals, both buses, and both 12V rails |
| SW1, SW2, SW3 | 3 | 6×6mm tactile push-button, THT, 2-pin | Omron / B3F-1000 | [B3F-1000](https://www.mouser.com/ProductDetail/Omron-Electronics/B3F-1000) | Verified — confirm actuator height/force (100gf, 4.3mm button) matches the footprint's expectations |
| Y1 | 1 | 25MHz SMD oscillator, 7×5mm, 3.3V, LVCMOS | IQD Frequency Products / XLH736025000000X | [972-XLH736025000000X](https://www.mouser.com/ProductDetail/IQD/XLH736025000000X) | Found by the user on Mouser — confirmed 7mm×5mm package and 3.135–3.465V supply range (covers 3.3V nominal), LVCMOS output. Different manufacturer than originally guessed (IQD, not EuroQuartz) but matches the footprint and electrical requirements. |
| R8, R13, R21 | 3 | 10kΩ, 0805 | Yageo / RC0805FR-0710KL | [RC0805FR-0710KL](https://www.mouser.com/ProductDetail/YAGEO/RC0805FR-0710KL) | Verified |
| R6, R7, R14 | 3 | 4.7kΩ, 0805 | Yageo / RC0805FR-074K7L | [RC0805FR-074K7L](https://www.mouser.com/ProductDetail/YAGEO/RC0805FR-074K7L) | Verified |
| R5, R10, R15, RPU1 | 4 | 1kΩ, 0805 | Yageo / RC0805FR-071KL | [RC0805FR-071KL](https://www.mouser.com/ProductDetail/YAGEO/RC0805FR-071KL) | Verified |
| R16, R19, R22, R23, R24 | 5 | 100kΩ, 0805 | Yageo / RC0805FR-07100KL | [RC0805FR-07100KL](https://www.mouser.com/ProductDetail/YAGEO/RC0805FR-07100KL) | Verified |
| R2, R3, R4 | 3 | 220Ω, 0805 | Yageo / RC0805FR-07220RL | [RC0805FR-07220RL](https://www.mouser.com/ProductDetail/YAGEO/RC0805FR-07220RL) | Verified |
| R20 | 1 | 20kΩ, 0805 | Yageo / RC0805FR-0720KL | [RC0805FR-0720KL](https://www.mouser.com/en/ProductDetail/YAGEO/RC0805FR-0720KL) | Verified — added late, was missing from the original pass entirely |
| R9, R11, R17 | 3 | 330Ω, 0805 | Yageo / RC0805FR-07330RL | — | Pattern-matched (same verified RC0805 series) — confirm on mouser.com before ordering. **Never made it into `mouser_cart.csv` and so were missing from the actual order; added now.** RS Components alternative: RS 242-6990. |
| R12 | 1 | 200Ω, 0805 | Yageo / RC0805FR-07200RL | — | Pattern-matched — confirm on mouser.com before ordering. **Also missing from the actual order; added to the cart now.** RS Components alternative: RS 242-6931 (MOQ ×100 on the listing checked). |
| RG1 | 1 | 100Ω, 0805 | Yageo / RC0805FR-07100RL | — | Pattern-matched — confirm on mouser.com before ordering. **Also missing from the actual order; added to the cart now.** RS Components alternative: RS 618-5135. |
| C3 | 1 | 10nF, 0805, X7R, 50V | Yageo / CC0805JRX7R9BB103 | [CC0805JRX7R9BB103](https://www.mouser.com/ProductDetail/YAGEO/CC0805JRX7R9BB103) | Verified |
| C2, C4, C5, C6, C7, C8, C9, C10 | 8 | 100nF, 0805, X7R, 50V | Yageo / CC0805KRX7R9BB104 | [CC0805KRX7R9BB104](https://www.mouser.com/ProductDetail/YAGEO/CC0805KRX7R9BB104) | Verified — C9/C10 added late (INA226 `VS` decoupling for U1/U3), was missing from this row entirely until now |
| — | 4 | M3×10mm male-female hex standoff, nylon (matches the board's 3.2mm non-plated mounting holes) | Essentra / MTS-10S | search "Essentra MTS-10S" on mouser.com | Not independently verified live on Mouser — confirm before ordering. Screw length into the standoff's female end depends on your enclosure/base; a separate M3 screw is also needed for the male end if there's no tapped base. RS Components also stocks this part, but two lookups gave inconsistent stock numbers and one showed an 8-week backorder — search "MTS-10S" on RS directly rather than trust a number here. |
| — | 2 | 1×36 2.54mm female header strip, break-away (socket the Pico 2 instead of soldering it directly — see DESIGN.md "Controller") | Sullins / PPPC361LFBN-RC | search "Sullins PPPC361LFBN-RC" on mouser.com | Not independently verified live on Mouser — confirm before ordering. Break each strip to two 20-pin + a short 3-pin length per side to match U5's pad rows; **test-fit one pin in a spare board hole first** — the existing through-hole pads (1.02mm drill) weren't originally dimensioned for header posts, just happen to be at the right 2.54mm pitch. **No RS Components match found** — RS stocks short RS PRO female sockets (2-5 position, 2.54mm, single row) but nothing confirmed in a long break-away length; search RS for "female header 2.54mm 1 row" yourself, or source just this one part from Mouser/Digikey/LCSC. |

## Summary: not orderable as-is

Just **D2** (SK6812 LED) — not stocked on Mouser at all, a lead found on
LCSC instead (see its row; pad pitch not independently confirmed). The two
mounting-hardware rows (standoffs, Pico 2 socket headers) are new and also
not independently confirmed live — everything else now has a specific, real
Mouser part number, largely thanks to the user checking the live site
against each entry — several of the original "Verified" entries turned out
to be wrong or unorderable (wrong digit, missing packaging suffix, zero
stock, wrong distributor) and got corrected in the process. Treat any
*remaining* unedited "Verified" row with the same healthy skepticism if
something doesn't match when you actually try to order it.

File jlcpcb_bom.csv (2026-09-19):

Comment | Designator | Footprint | LCSC Part #
100nF | C2,C4,C5,C6,C7,C8,C9,C10 | C_0805_2012Metric | C49678
10nF | C3 | C_0805_2012Metric | C83170
SS54 | D1 | D_SMC | C16103
SK6812 | D2 | LED_SK6812_PLCC4_5.0x5.0mm_P3.2mm | C5378720
2N7002 | Q1,Q3,Q5 | SOT-23 | C332103
P-MOS -30V >=5A | Q2 | TO-252-2 | C141584
1k | R10,R15,R5,RPU1 | R_0805_2012Metric | C17513
330R | R11,R17,R9 | R_0805_2012Metric | C17630
200R | R12 | R_0805_2012Metric | C17540
10k | R13,R21,R8 | R_0805_2012Metric | C17414
4.7k | R14,R6,R7 | R_0805_2012Metric | C17673
100k | R16,R19,R22,R23,R24 | R_0805_2012Metric | C17407
220R | R2,R3,R4 | R_0805_2012Metric | C17557
20k | R20 | R_0805_2012Metric | C4328
100R | RG1 | R_0805_2012Metric | C17408
INA226 (0x40) | U1 | MSOP-10_3x3mm_P0.5mm | C49851
MCP4728 (0x60) | U2 | MSOP-10_3x3mm_P0.5mm | C108207
INA226 (0x41) | U3 | MSOP-10_3x3mm_P0.5mm | C49851
AD9833 | U4 | MSOP-10_3x3mm_P0.5mm | C1519069
TS5A3159A | U6,U7,U8 | SOT-23-6 | C128405

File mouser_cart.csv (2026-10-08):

Mouser Part Number | Quantity | Description | Reference Designators
SC1631 | 1 | Raspberry Pi Pico 2 | U5
INA226AIDGST | 2 | INA226 current/power monitor MSOP-10 | U1,U3
MCP4728-E-UN | 1 | MCP4728 quad DAC MSOP-10 | U2
AD9833BRMZ-REEL7 | 1 | AD9833 DDS MSOP-10 | U4
TS5A3159ADBVR | 3 | TS5A3159A SPDT analog switch SOT-23-6 | U6,U7,U8
CRA2512-FZ-R020ELF | 1 | 0.02R 1% shunt 2512 | RS1
71-WSL2512R0330FEA | 1 | 0.033R 1% shunt 2512 | RS2
SUD50P06-15-GE3 | 1 | P-MOS DPAK ECU load switch | Q2
512-2N7002 | 3 | 2N7002 N-MOSFET SOT-23 | Q1,Q3,Q5
821-SS54FSH | 1 | SS54 Schottky diode SMC 5A/40V | D1
972-XLH736025000000X | 1 | 25MHz SMD oscillator 7x5mm 3.3V LVCMOS | Y1
B2B-XH-ALFSN | 1 | JST XH 2-pos vertical header | J2
TSW-104-07-G-S | 1 | 4-pos 2.54mm vertical header | J3
534-5011 | 14 | THT test point (substitute for bare pad) | TP1,TP2,TP3,TP4,TP5,TP6,TP7,TP8,TP9,TP10,TP11,TP12,TP13,TP14
B3F-1000 | 3 | 6x6mm tactile switch | SW1,SW2,SW3
RC0805FR-0710KL | 3 | 10k 0805 | R8,R13,R21
RC0805FR-074K7L | 3 | 4.7k 0805 | R6,R7,R14
RC0805FR-071KL | 4 | 1k 0805 | R5,R10,R15,RPU1
RC0805FR-07100KL | 5 | 100k 0805 | R16,R19,R22,R23,R24
RC0805FR-07220RL | 3 | 220R 0805 | R2,R3,R4
RC0805FR-0720KL | 1 | 20k 0805 | R20
RC0805FR-07330RL | 3 | 330R 0805 | R9,R11,R17
RC0805FR-07200RL | 1 | 200R 0805 | R12
RC0805FR-07100RL | 1 | 100R 0805 | RG1
CC0805JRX7R9BB103 | 1 | 10nF 0805 X7R 50V | C3
CC0805KRX7R9BB104 | 8 | 100nF 0805 X7R 50V | C2,C4,C5,C6,C7,C8,C9,C10
1935161 | 1 | 2-pos 5.08mm PCB terminal block (fixed; footprint wants pluggable -- check fit) | J1
39543-0015 | 1 | 15-pos 5.00mm screw terminal (pluggable vs fixed not confirmed) | J0
504-TR/3216FF3-R | 1 | 3A fast-acting SMD fuse 1206/3216 | F1
80-ESH107M035AG3AA | 1 | 100uF/35V radial electrolytic (35V not 25V -- safe upgrade) | C1
MTS-10S | 4 | M3x10mm nylon male-female hex standoff (not independently confirmed on Mouser -- check live) | mounting
PPPC361LFBN-RC | 2 | 1x36 2.54mm female header break-away for socketing U5 (not independently confirmed on Mouser -- check live; test-fit before ordering more) | U5

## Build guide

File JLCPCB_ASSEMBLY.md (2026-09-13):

# JLCPCB SMD assembly — how to use `jlcpcb_bom.csv` / `jlcpcb_cpl.csv`

Hybrid sourcing plan: let JLCPCB machine-place the 0.5mm-pitch ICs and 0805
passives (the fiddly stuff), hand-solder the rest yourself (THT connectors,
switches, the Pico module, and 4 SMD parts JLCPCB doesn't have a confirmed
part number for — see below). See [`BOM.md`](BOM.md) for full-board Mouser
sourcing if you'd rather hand-solder everything.

`jlcpcb_cpl.csv` positions/rotations came straight from the actual
`board/digifant2-pruefstand.kicad_pcb` (via `pcbnew`, not estimated) — 42
SMD parts, all on the top side. `jlcpcb_bom.csv` LCSC part numbers were
researched against lcsc.com; every number in the file was individually
confirmed there, nothing pattern-guessed made it into these two files
(unconfirmed items were excluded instead — see below).

## Before you submit: check placement rotation in JLCPCB's preview

JLCPCB's pick-and-place rotation convention doesn't always match KiCad's raw
`0°` orientation, especially for parts with a clear pin-1/polarity marking.
**Use JLCPCB's online assembly preview (it renders every part's actual
orientation) and visually check these before ordering** — a wrong rotation
here means a part soldered in backwards:

- **D1** (SS54 diode) — cathode band orientation
- **D2** (SK6812 LED) — has a required orientation (pin 1 / data-in corner)
- **Q1, Q2, Q3, Q5** (MOSFETs, SOT-23 / DPAK) — gate/drain/source pinout
- **U1–U4, U6–U8** (MSOP-10 / SOT-23-6 ICs) — pin 1 orientation

Everything else (0805 resistors/caps) is symmetric and rotation-safe.

## 4 SMD parts excluded — hand-solder these separately

No individually-confirmed LCSC part number turned up for these, so they're
**not** in `jlcpcb_bom.csv`/`jlcpcb_cpl.csv` — order them via
[`BOM.md`](BOM.md)'s Mouser numbers (or find your own LCSC listing) and
hand-solder after the assembled board arrives:

- **F1** (3A/1206 fuse) — only a Mouser/LCSC category was confirmed, no single SKU
- **RS1** (0.02Ω 1% shunt, 2512) — Mouser SKU confirmed (`CRA2512-FZ-R020ELF`), not independently found on LCSC
- **RS2** (0.033Ω 1% shunt, 2512) — value unconfirmed at *any* distributor; either track down `CRA2512-FZ-R033ELF` yourself, or substitute a confirmed 0.030Ω/0.025Ω part and adjust the INA226 calibration constant in firmware
- **Y1** (25MHz XO91-style oscillator) — exact EuroQuartz part confirmed to exist elsewhere, not pinned to a Mouser or LCSC SKU this pass

These 4, plus the always-hand-soldered THT parts (J0–J3, TP1–TP14, SW1–SW3, C1,
U5/Pico), are the same set flagged in `BOM.md`.

## Notable per-part caveats (already reflected in the BOM, just so you know why)

- **D1**: LCSC part `C16103` is the **SS54C** variant (DO-214AB/SMC — matches
  this board's footprint). Plain "SS54" on LCSC (`C22452`) is a *different,
  smaller* DO-214AC/SMA package — don't substitute it.
- **D2**: `C5378720` (OPSCO SK6812) is confirmed in stock and the right
  family/package class, but the exact PLCC-4 5.0×5.0mm footprint wasn't
  independently re-verified pin-for-pin against this board's footprint —
  worth a quick visual check against the datasheet before ordering qty 1.
- **U6/U7/U8** (TS5A3159ADBVR): flagged as possibly EOL at TI in one search
  pass, not corroborated in a second — check TI's lifecycle page before
  ordering qty 3, in case a last-time-buy applies.
- **100k resistor** (`C17407`): two LCSC listings for the same
  `0805W8F1003T5E` part number turned up (`C17407` and `C149504`) — either
  should work, `C17407` is what's in the BOM.

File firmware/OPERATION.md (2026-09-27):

# Operating the Prüfstand

How to use the Digifant-2 test bench: what it does, how to drive it from the
buttons and display or from a PC, how to read what it measures, and which
safety behaviour to expect. Written for technically minded users who know
their way around an engine ECU but haven't seen this bench before.

- Setting the board up for the first time: [`../BRINGUP.md`](../BRINGUP.md)
- Firmware internals, full protocol reference, tests: [`README.md`](README.md)
- Hardware design and pinouts: [`../DESIGN.md`](../DESIGN.md)

All screen images below are rendered from the firmware's own display code
(see [Regenerating the images](#regenerating-the-images)), so they show
exactly what the OLED shows. The readings in them are example values.

## What the bench does

The bench stands in for the engine around a real Digifant-2 ECU (VW 2H
engine). It generates the signals the ECU expects and measures what the ECU
sends back:

```mermaid
flowchart LR
    PC["PC<br/>bench.py / scripts"] -- USB serial --> Pico["Raspberry Pi Pico<br/>firmware"]
    UI["OLED + 3 buttons"] --- Pico
    Pico --> CRANK["crank / Hall signal<br/>VW-18"]
    Pico --> DAC["sensor voltages<br/>air, coolant, air-flow, lambda<br/>VW-9 / 10 / 21 / 2"]
    Pico --> SW["idle switch VW-11<br/>sensor open-circuit faults"]
    Pico --> KNOCK["knock tone / bursts<br/>TP1 to VW-4"]
    Pico --> PWR["ECU power switch<br/>+ current / voltage sense"]
    CRANK & DAC & SW & KNOCK & PWR --> ECU["Digifant-2 ECU"]
    ECU -- "ignition VW-25<br/>injector VW-12" --> CAP["pulse capture<br/>width + crank angle"]
    ECU -- "idle valve VW-23" --> VALVE["real idle valve on J2<br/>current sense"]
    CAP & VALVE --> Pico
```

| Simulated for the ECU | Range |
|---|---|
| Engine speed (Hall signal on VW-18, 0 / 12 V square wave) | 0–8000 rpm, pulses per rev and duty adjustable |
| Intake-air and coolant temperature (NTC inputs VW-9, VW-10) | 0–3300 mV each, or open circuit (sensor fault) |
| Air-flow meter wiper (VW-21) | 0–3300 mV |
| Lambda / O₂ sensor (VW-2) | 0–2047 mV in 0.5 mV steps, or open circuit |
| Idle switch (VW-11) | closed / open |
| Knock sensor (TP1/TP2 to VW-4/VW-5) | 1–20000 Hz sine, continuous or in crank-synchronised bursts |
| ECU supply (VW-14) | switched on/off by the bench |

| Measured from the ECU | Resolution |
|---|---|
| Ignition output (VW-25): pulse width, period, crank angle of both edges | 1 µs, ~0.1° |
| Injector output (VW-12): open time, period, crank angle | 1 µs, ~0.1° |
| ECU current and supply voltage | 0.125 mA, 1.25 mV |
| Idle-valve current and supply voltage (valve on J2, driven by the ECU) | 0.08 mA, 1.25 mV |
| Air-flow meter reference voltage from the ECU (VW-17) | 2.4 mV |

## Connections

| Where | What |
|---|---|
| **USB** (on the Pico) | Power for all the logic, and the PC connection. Without USB the bench is off and the ECU unpowered. |
| **J1** | 12 V bench supply (use one with a current limit). Feeds the ECU and the crank signal pull-up. |
| **J0** | Screw terminals to the ECU harness, labelled by VW pin; `+12V SW` = switched ECU supply, `GND` = ground. |
| **J2** | The real idle-air-control valve (the ECU drives it through VW-23). |
| **TP1 / TP2** | Knock output / ground, wired to the ECU's VW-4 / VW-5 by a short pigtail. |
| **J3** | I²C OLED, pin order `GND / 3V3 / SCL / SDA` (check your module!). |
| **SW1 / SW2 / SW3** | MENU / − / + buttons. |

## Power-up and safe state

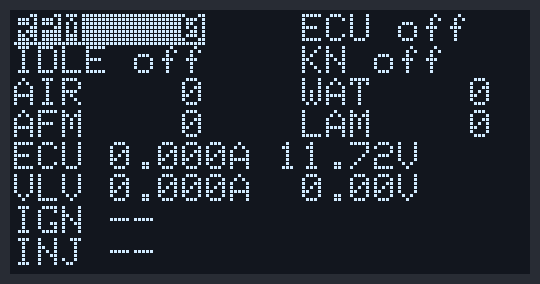
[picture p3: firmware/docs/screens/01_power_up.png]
Power-up screen


After plugging in USB the bench always starts in a safe state, whatever it
was doing before:

- ECU **off** (and it stays off until you switch it on)
- crank stopped (the crank signal's pull-up is on the switched ECU rail, so
  VW-18 only reads 12 V once the ECU is on)
- all sensor DACs at 0 mV, all three sensors connected, idle switch open
- knock generator off

The screen above is the power-up state with 12 V connected but no ECU
switched on: the ECU supply reads 11.72 V (the always-live side of the power
switch), and the valve supply reads 0 V because the switched rail is off.
`IGN --` and `INJ --` mean no pulses in the last 2 seconds.

## The display

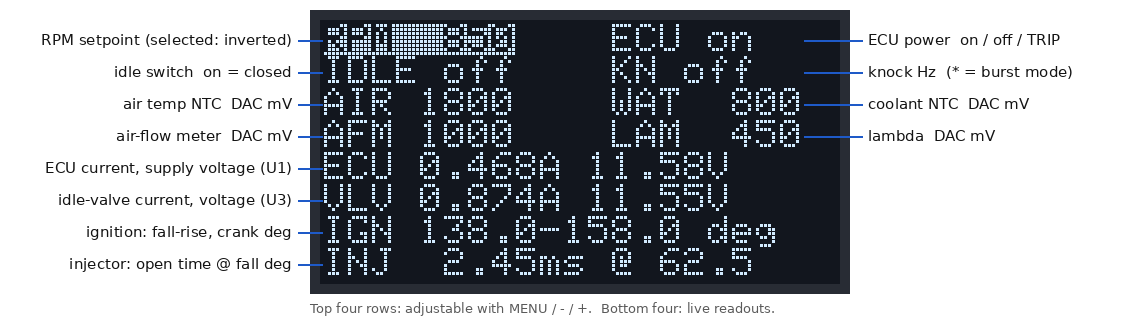
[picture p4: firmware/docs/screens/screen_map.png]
Screen map


The screen refreshes every 200 ms and immediately after a button press. The
**top four rows** are settings, adjustable with the buttons; the selected one
is drawn inverted. The **bottom four rows** are live readings:

| Row | Shows |
|---|---|
| `ECU 0.468A 11.58V` | Total current into the ECU rail and the supply voltage ahead of the ECU switch. |
| `VLV 0.874A 11.55V` | Idle-valve current (PWM from the ECU, averaged) and the switched supply. `--` if that monitor doesn't answer. |
| `IGN 138.0-158.0 deg` | Ignition output: crank angle of the pulse's start and end, measured from the crank reference (see [Crank angles](#crank-angles-and-bursts)). With the crank stopped: `IGN low 3920 us`, the width of the last pulse. |
| `INJ 2.45ms @ 62.5` | Injector open time, and the crank angle at which it opened. |

## Using the buttons

**MENU** steps to the next setting: RPM → ECU → IDLE → KN → AIR → WAT → AFM →
LAM → back to RPM. **−** and **+** change the selected setting.

| Setting | − / + | Held down |
|---|---|---|
| `RPM` | −/+ 50 rpm, 0–8000 | repeats (after 0.4 s, then every 0.1 s) |
| `ECU` | − off, + on (never toggles, so a double press can't switch it) | no repeat |
| `IDLE` | − open, + closed (throttle at idle) | no repeat |
| `KN` | −/+ 500 Hz knock tone, below 500 = off | repeats |
| `AIR`, `WAT`, `AFM`, `LAM` | −/+ 50 mV on that sensor output | repeats |

Buttons and PC commands change the same settings, so you can mix them freely:
the display always shows the current state, including changes made over USB.

### Example: switching the ECU on

Press **MENU** once: `ECU off` is selected.

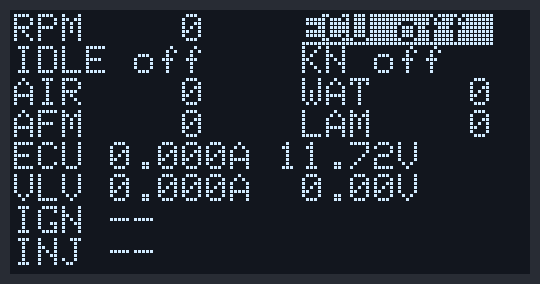
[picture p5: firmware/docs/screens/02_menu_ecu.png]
ECU selected


Press **+**: the ECU is powered. Its current appears in the `ECU` row
(here 0.41 A) and the switched rail comes up in the `VLV` row.

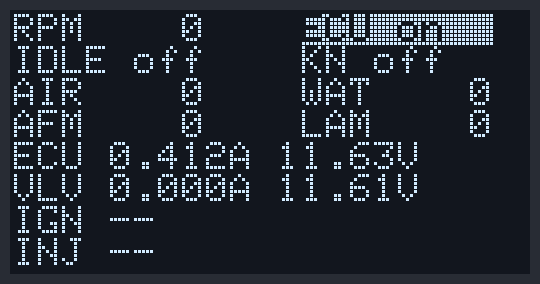
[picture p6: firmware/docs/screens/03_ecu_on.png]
ECU on


While the ECU is off, the sensor voltages and the knock tone are held at 0 V
("parked") so they can't feed current into an unpowered ECU. Your settings are
kept and applied the moment the ECU is switched on.

### Example: a warm idle at 850 rpm

With the sensors set for a warm engine (coolant `WAT 800`, air `AIR 1800`,
air-flow `AFM 1000`, lambda `LAM 450`), select **RPM** and press **+** 17
times (or hold it). The ECU sees an engine turning at 850 rpm and starts
firing: the `IGN` and `INJ` rows now show pulse timing and crank angles.

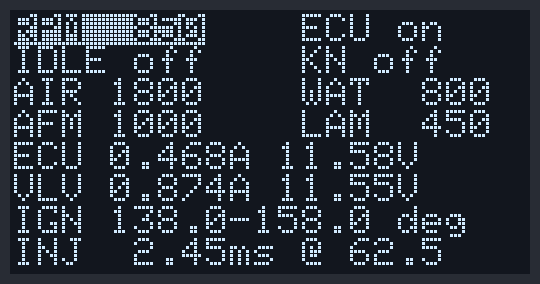
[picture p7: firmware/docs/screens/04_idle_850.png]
Warm idle at 850 rpm


How millivolts map to temperatures depends on the ECU's input circuit and is
still to be calibrated on the real bench ([`BRINGUP.md`](../BRINGUP.md),
stage 6).

### Example: simulating a cold engine

Select **WAT** and raise the coolant sensor voltage (here to 3000 mV; a
higher NTC voltage means colder). The ECU should respond with longer injector
pulses and a different idle-valve current.

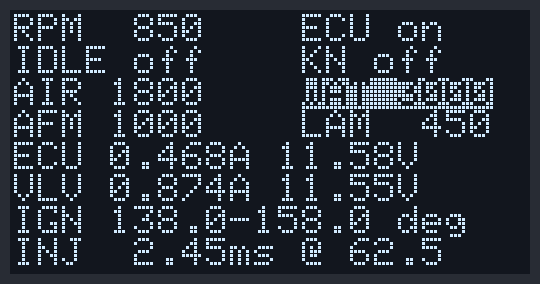
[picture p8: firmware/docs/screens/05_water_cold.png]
Coolant raised to simulate a cold engine


### Knock

**KN** sets the knock tone frequency. A `*` after it means burst mode is on
(bursts are set up from the PC, see below): the tone then only sounds in a
crank-angle window after every reference instead of continuously.

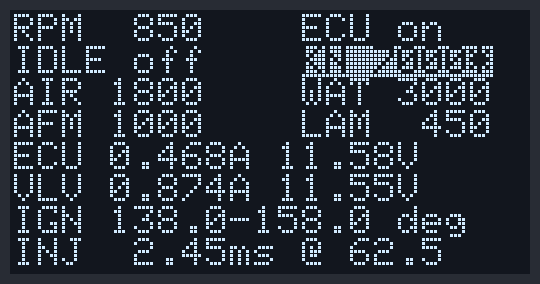
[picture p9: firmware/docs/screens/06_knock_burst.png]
Knock at 7000 Hz in burst mode


### Over-current trip

If the ECU draws more than the trip current (default 2.5 A) for two readings
in a row (~0.3 s), the bench switches the ECU off by itself and the display
shows `ECU TRIP`. The ECU can't be switched back on until the trip is
acknowledged.

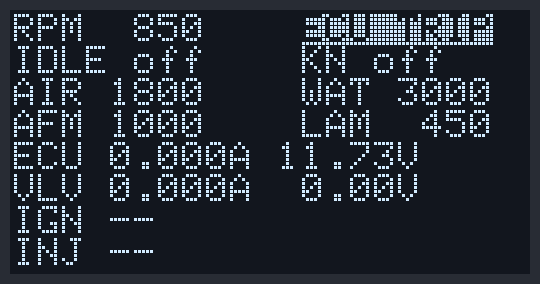
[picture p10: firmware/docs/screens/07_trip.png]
Over-current trip


To recover: find the cause, then select **ECU** and press **−** once to
acknowledge (`ECU off`), then **+** to switch on again. From the PC:
`ecu reset`, then `ecu on`.

### Crank stopped

With the crank stopped (`RPM 0`) there is no reference to measure angles
from, so the rows show the width of the last pulse instead: here the
ignition output was last low for 3.92 ms and the injector last open for
6.10 ms. Both change to `--` two seconds after the last pulse. `VLV --`
means the valve current monitor isn't answering.

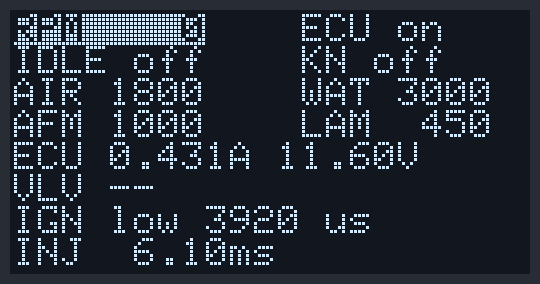
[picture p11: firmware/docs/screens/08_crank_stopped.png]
Crank stopped


## Controlling the bench from a PC

The Pico appears as a USB serial port. `host/bench.py` finds it
automatically (`pip install pyserial` first):

```sh
python3 host/bench.py                       # interactive prompt
python3 host/bench.py "ecu on" "rpm 850" capture
```

```text
bench> ecu on
OK ecu=on
bench> rpm 850
OK rpm=850
bench> capture
OK ign_n=512 ign_glitch=0 ign_period_us=35294 ign_low_us=3920 ign_fall_deg=138.0 ign_rise_deg=158.0 inj_n=256 inj_glitch=0 inj_period_us=70588 inj_low_us=2450 inj_fall_deg=62.5 inj_rise_deg=75.0
```

Every command gets exactly one line back, `OK` with `key=value` fields or
`ERR` with a reason. Commands are case-insensitive, numbers are plain
decimal. The most used ones:

| Command | Does |
|---|---|
| `status` | All settings in one line. |
| `read` | ECU and valve current/voltage, VW-17 reference. |
| `capture` | Ignition and injector pulse timing and angles. |
| `ecu on` / `ecu off` / `ecu reset` / `ecu trip <mA>` | ECU power, trip acknowledge, trip current (100–4000 mA). |
| `rpm <0..8000>` | Engine speed; 0 stops the crank signal. |
| `crank ppr <n>` / `crank duty <pct>` | Hall pulses per crank revolution (default 2) and % high (default 50). |
| `dac air\|water\|afm\|lambda <mV>` | Sensor voltages. |
| `sensor air\|water\|lambda open\|conn` | Simulate a broken sensor wire, and reconnect it. |
| `idle on\|off` | Idle switch. |
| `knock <Hz>` / `knock off` | Knock tone. |
| `burst <start_deg> <len_deg> [every]` / `burst off` | Knock in bursts: from `start_deg` after each reference, for `len_deg`, on every Nth reference. |

The full list with every field is in the [protocol reference](README.md#protocol).

### Scripting

`bench.py` is also a Python module. `Bench.cmd()` returns the reply's fields
as a dict and raises `BenchError` on `ERR`:

```python
from bench import Bench

with Bench() as b:
    b.cmd("ecu on")
    b.cmd("dac water 800")
    b.cmd("rpm 850")
    print(b.cmd("capture")["ign_rise_deg"])
```

[`host/examples/rpm_sweep.py`](../host/examples/rpm_sweep.py) is a complete
example: it sets a warm idle, steps the engine speed from 850 to 4000 rpm and
writes the ignition angles, dwell, injector time and ECU current at each step
to a CSV file, ready for plotting an advance curve:

```sh
python3 host/examples/rpm_sweep.py --out sweep.csv
```

Leave each step a moment to settle (`--settle`, default 1.5 s): the ECU needs
a few revolutions to react, and the current readings are averaged over
~0.14 s.

## Crank angles and bursts

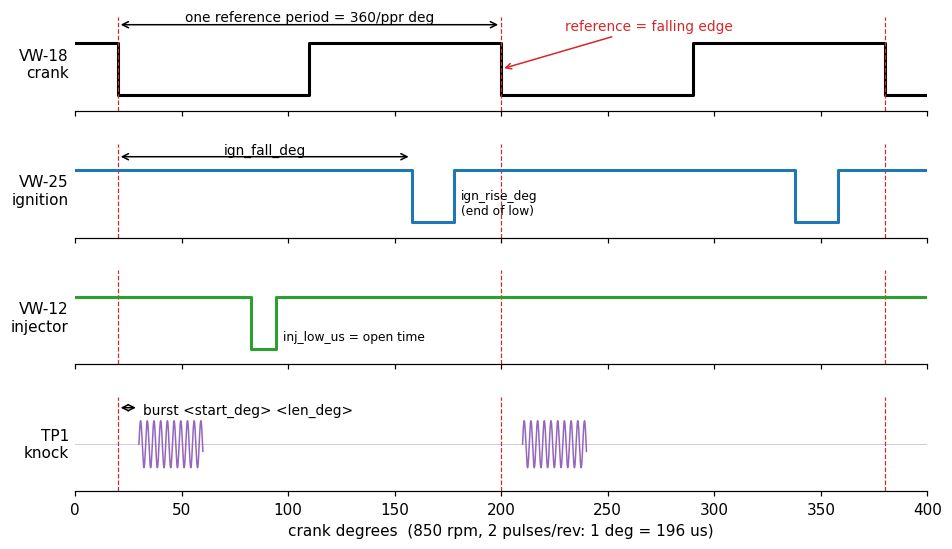
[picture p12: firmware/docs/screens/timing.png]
Timing of the crank signal, ignition, injector and knock bursts


Everything angle-related is measured from the **crank reference**: the
falling edge of the Hall signal on VW-18 (dashed red lines). With the default
2 pulses per crank revolution, one reference period is 180 crank degrees.

- Angles are computed from the *measured* time since the last reference and
  the *measured* reference period, so they stay correct while rpm changes.
- `ign_fall_deg` / `ign_rise_deg`: where the ignition output's low phase
  starts and ends. A pulse that runs past the next reference is still
  measured from the one before it (e.g. 170° → 200°, not 170° → 20°).
- `inj_fall_deg`: where the injector opens; `inj_low_us` is its open time.
- `burst 10 30` sounds the knock tone from 10° to 40° after every reference;
  `burst 10 30 2` on every second reference only (at 2 pulses/rev: once per
  crank revolution, like one knocking cylinder). A burst must fit inside one
  reference period (start + length < 360 / ppr).

Timing resolution is 1 µs: at 850 rpm one crank degree is 196 µs, at 6000 rpm
it's 28 µs.

## Safety behaviour

| Situation | What the bench does |
|---|---|
| USB plugged in / Pico reset | Safe state: ECU off, crank stopped, sensors at 0 mV, knock off. |
| USB unplugged | Everything off; a pull-down on the power switch keeps the ECU unpowered. |
| ECU off | Sensor voltages and knock tone parked at 0 V, settings kept. |
| ECU current above the trip level for ~0.3 s | ECU switched off, fault latched until `ecu reset` or − on ECU. |
| Firmware hangs | Watchdog resets the Pico after 2 s → safe state; `status` shows `boot=watchdog`. |
| Sensor DAC not answering | Writes are retried every second; `status` shows `dac_i2c=err` until it's back. |

The over-current trip reacts in ~0.3 s; short spikes are left to the board's
3 A fuse.

## Known limits and open assumptions

These are documented in detail in [`README.md`](README.md) and are to be
settled on the real bench ([`BRINGUP.md`](../BRINGUP.md), stage 6):

- **Hall waveform:** 2 pulses per crank revolution and 50 % duty are
  assumptions until measured on a real engine (`crank ppr`, `crank duty`).
- **Reference and spark edge:** the firmware measures from the VW-18 falling
  edge; which ignition edge is the spark (probably the end of the low phase)
  is still to be confirmed.
- **Sensor voltages are set at the DAC**, ahead of a 220 Ω (lambda 1 kΩ)
  series resistor; if the ECU has an internal pull-up on its NTC inputs, the
  voltage it sees is higher than the setting.
- **Knock amplitude is fixed** and falls with frequency (about 75 % at 7 kHz
  of the 1 kHz level).
- **Display:** assumes an SSD1306 OLED; SH1106-based 1.3″ modules need a
  driver change.
- The status LED has no firmware yet.
- No firmware has run on real hardware yet (September 2026).

## Regenerating the images

The screens are rendered on a PC by
[`docs/render_screens.c`](docs/render_screens.c), which drives the real
display code (`src/ui_core.c`, `src/gfx.c`) through the same steps as above,
then styled and annotated by [`docs/make_images.py`](docs/make_images.py):

```sh
firmware/docs/make_images.sh      # needs gcc, python3, Pillow, matplotlib
```

CI builds and runs the renderer on every push, so a change to the display
code that breaks it is caught; re-run the script to update the pictures.

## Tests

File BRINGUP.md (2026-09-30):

# Bring-up: first power-on of the Prüfstand

A step-by-step checklist from bare board to a real ECU running on the bench.
Each stage only adds one new risk, so if something is wrong you find it while
it's cheap. Tick the boxes as you go and fill in the results table at the end;
those answers settle the open questions the firmware still guesses at.

Commands are sent with `python3 host/bench.py` (interactive prompt; see
[`firmware/README.md`](firmware/README.md) for the full protocol). "J0 VW-18"
means the J0 screw terminal labelled `VW-18` on the silkscreen. J0's power
terminals are labelled by function instead: the two `+12V SW` terminals are
VW-14 (ECU supply) and VW-22 (idle-valve feed), and the three `GND` terminals
are VW-6, VW-13 and VW-19.

## What you need

| Tool | Used for |
|---|---|
| **Lab power supply, 12–14 V, adjustable current limit** | All 12 V stages. The current limit is the main safety net: start at 100 mA. |
| **Multimeter** | Continuity before power, rails, DAC outputs, series current. |
| **Oscilloscope, ≥ 2 channels** (20 MHz is plenty) | Crank signal on VW-18, knock tone/bursts on TP1, ignition/injector timing. |
| **Micro-USB *data* cable + PC** with Python 3 and `pip install pyserial` | Flashing and all commands. Charge-only cables are a classic trap. |
| Logic analyzer, 8 ch / 24 MHz clone + PulseView (optional, ~€10) | Decoding I²C (TP10/TP11) and SPI (TP7–TP9) if a chip doesn't answer. |
| **Power resistors: 1 × 47 Ω / 5 W, 2 × 22 Ω / 10 W** (5 % is fine; aluminium-housed, e.g. the Arcol HS series, screwed to a bit of aluminium) | Dummy loads: ~0.25 A, ~0.55 A and ~1.1 A at 12 V, for the over-current trip and the current calibration. |
| Hook-clip test leads, jumper wire, a 1.5 V AA cell | Probing, faking an ECU output pulse, testing the VW-17 ADC input. |
| 0.96″ SSD1306 OLED module (I²C, 4 pins) | Stage 4. |
| Magnifier / loupe | Checking solder joints on the SMD parts. |
| For stage 6: the J0 harness to the ECU connector, a short pigtail from TP1/TP2 to VW-4/VW-5, the idle valve for J2, ideally a **spare** Digifant-2 ECU | Real ECU. |

Test points (by their reference designators on the silkscreen): TP1/TP2 knock out/ground, TP3 crank
drive (GP2, 3.3 V logic, *inverted* vs VW-18), TP4 idle-switch drive, TP5/TP6
ignition/injector capture, TP7–TP9 SPI (FSYNC/SCK/MOSI), TP10/TP11 I²C
(SDA/SCL), TP12 LED data, TP13 `+12V_ECU` (always live after the fuse/diode),
TP14 `+12V_ECU_SW` (switched ECU rail). Ground: J1 −, any J0 `GND` terminal, or TP2.

**Never:**
- put any voltage on J0 VW-12 or VW-25: they are pulled up to 3.3 V and go
  (through 330 Ω) straight to Pico pins. The ECU only ever pulls them low.
  Don't connect a real injector or ignition module to them either.
- put more than ~9 V on J0 VW-17: its 20k/10k divider feeds the Pico's ADC,
  which tops out at 3.3 V. The ECU's ~5 V reference is fine; 12 V is not.
- power an OLED module whose pin order doesn't match J3 (see stage 4).

---

## Stage 0 — Flash the Pico before it goes on the board (optional)

Catches a dead Pico or a bad cable before soldering.

1. Firmware: build it (`firmware/README.md`, "Build and flash") or download
   `pruefstand-firmware` from the latest green run on the repo's **Actions**
   tab.
2. Hold BOOTSEL, plug in USB, copy `pruefstand.uf2` onto the `RPI-RP2` drive.

- [ ] `python3 host/bench.py ping` → `OK pong fw=0.9.0`
- [ ] `status` → `boot=power ecu=off …`; `dac_i2c=err` is expected here (no DAC on a bare Pico)

## Stage 1 — Visual and continuity, no power

- [ ] Polarity/orientation: D1 (SS54, band), C1 (electrolytic, − stripe),
      every IC's pin 1 (U1–U4, U6–U8), Y1 oscillator's pin-1 dot, Q2 (DPAK)
- [ ] No solder bridges on the fine-pitch parts (U1/U3 INA226, U4 AD9833, U2 MCP4728)
- [ ] Resistance to ground (multimeter, either polarity; anything below ~10 Ω is a short):
  - [ ] J1 + to J1 −
  - [ ] TP13 (`+12V_ECU`) to GND
  - [ ] TP14 (`+12V_ECU_SW`) to GND
  - [ ] +3V3 (J3's 3V3 pin, or either end of R6/R7) to GND
- [ ] F1 (fuse) has continuity

## Stage 2 — USB only, no 12 V

The Pico runs from USB alone and powers all the logic (INA226s, DAC, AD9833
and switches run on +3V3), so everything on the I²C bus can be checked
without any 12 V risk.

- [ ] Pico enumerates, `ping` → `OK pong fw=0.9.0`
- [ ] `status` → `dac_i2c=ok` (MCP4728 answers at 0x60)
- [ ] `read` → `ecu_v` and `valve_v` are **numbers**, not `na` (both INA226s
      answer), both ≈ 0 V; `afm_ref_mv` ≈ 0
- [ ] Idle switch: ohmmeter, red lead on J0 VW-11, black on a J0 `GND` terminal (the
      other way round the MOSFET's body diode conducts and it always reads low)
  - [ ] `idle on` → a few Ω
  - [ ] `idle off` → open
- [ ] VW-17 input: AA cell between J0 VW-17 (+) and GND (−) → `read`
      `afm_ref_mv` ≈ the cell's voltage (~1500 mV), ±50 mV. Remove the cell.
- [ ] `capture` works without an ECU: tap a jumper from J0 VW-25 to GND a few
      times → `ign_n` counts up (switch bounce may also raise `ign_glitch`,
      that's fine). Same for VW-12 → `inj_n`.

If a chip shows `na`/`err`: check its solder joints first, then look at TP10/TP11
with the logic analyzer (PulseView I²C decoder; addresses 0x40, 0x41, 0x60).

## Stage 3 — 12 V on, current limit 100 mA, no ECU

Set the supply to 12.0 V, **limit 100 mA**, then connect it to J1 with USB
already plugged in.

- [ ] Supply current with the ECU off: a few mA at most (not in current limit)
- [ ] TP13 ≈ supply minus ~0.2–0.5 V (D1 drop); TP14 ≈ 0 V
- [ ] `read` → `ecu_v` ≈ TP13 (±0.05 V), `ecu_a` ≈ 0

**ECU switch (still no ECU connected):**
- [ ] `ecu on` → TP14 ≈ TP13; `read` `valve_v` ≈ `ecu_v`; `ecu_a` ~1 mA (Q2's gate drive)
- [ ] `ecu off` → TP14 falls back to ~0 V
- [ ] Fail-safe: `ecu on`, then **unplug USB** → TP14 drops to 0 (R16 holds
      the switch off). Plug USB back in → `status` shows `boot=power ecu=off`.

**Crank signal** (needs `ecu on`: its pull-up is on the switched rail).
Scope on J0 VW-18 to GND:
- [ ] `rpm 0` → VW-18 steady high, ≈ 12 V
- [ ] `rpm 850` → square wave 0 V / ≈ 12 V, **28.3 Hz** (35.3 ms period), 50 % high
- [ ] `rpm 6000` → 200 Hz, clean edges, low level below ~0.3 V
- [ ] `crank duty 30` → high for 30 % of the period; then `crank duty 50`
- [ ] `read` `ecu_a` rises by ~6 mA with the crank running (1 k pull-up, 50 % duty)
- [ ] `rpm 0`

**Sensor DACs** (outputs are held at 0 V while the ECU is off, so `ecu on`
first). Multimeter on the J0 terminals to GND, nothing else connected:
- [ ] `dac air 1000` → VW-9 ≈ 1.000 V (within ~20 mV)
- [ ] `dac water 2500` → VW-10 ≈ 2.500 V
- [ ] `dac afm 1500` → VW-21 ≈ 1.500 V
- [ ] `dac lambda 450` → VW-2 ≈ 0.450 V
- [ ] `sensor air open` → VW-9 no longer driven (meter reads ~0 V or drifts); `sensor air conn` → 1.000 V again.
      Same for `water` (VW-10) and `lambda` (VW-2).
- [ ] `ecu off` → all four terminals ≈ 0 V, `status` still shows the setpoints;
      `ecu on` → the voltages come back
- [ ] `dac air 3300` → note the value (may clip a few tens of mV below 3.3 V)

**Knock generator** (also held off while the ECU is off). Scope on TP1, ground TP2:
- [ ] `knock 1000` → 1 kHz sine, ≈ 0.6 V peak-to-peak
- [ ] `knock 7000` → 7 kHz, smaller (the R12/C2 low-pass: ~75 % of the 1 kHz level)
- [ ] Bursts: channel 1 on J0 VW-18 (trigger on the falling edge), channel 2 on TP1.
      `rpm 850`, `knock 7000`, `burst 30 20`
      → a burst starts ≈ 5.9 ms after each VW-18 falling edge and lasts ≈ 3.9 ms
- [ ] `burst 30 20 2` → bursts on every second falling edge only
- [ ] `burst off`, `knock off`, `rpm 0`, `ecu off`

## Stage 4 — OLED and buttons

**Check the module's pin order first.** J3 is `GND / 3V3 / SCL / SDA`. Many
modules are `VCC / GND / SCL / SDA`, which would put 3.3 V onto the module's
ground: wire it with jumpers in that case, don't plug it straight in.

Unplug USB, fit the OLED, plug USB back in.
- [ ] Display shows the status screen within 2 s (if it stays dark or shows
      garbage it may be an SH1106 module, see `firmware/README.md`)
- [ ] MENU steps through RPM → ECU → IDLE → KN → AIR → WAT → AFM → LAM, the selected field inverted
- [ ] +/− on RPM changes it by 50, holding repeats; `status` agrees
- [ ] ECU: + switches on, − switches off (no toggle)
- [ ] With the display unplugged while running, the buttons still work, and
      plugging it back in brings the screen back within 2 s

The SK6812 status LED (D2) has no firmware driver yet; nothing to test there.

## Stage 5 — Dummy load: current reading and over-current trip

Supply limit **500 mA**. 47 Ω / 5 W resistor between a J0 `+12V SW`
terminal and a J0 `GND` terminal; multimeter in series in the supply lead, on its A range.

- [ ] `ecu on`, `read` → `ecu_a` ≈ 0.25 A and matches the series meter within
      ~2 % (remember the meter also sees the few mA of the board itself)
- [ ] `ecu_v` matches TP13 within ±0.05 V
- [ ] Trip: `ecu trip 100` → within ~0.3 s the ECU switches off by itself
  - [ ] `status` → `ecu=off ecu_fault=overcurrent`
  - [ ] `ecu on` → `ERR ecu tripped at … mA, send 'ecu reset' first`
  - [ ] OLED shows `ECU TRIP`; − on the ECU item clears it
- [ ] `ecu reset`, `ecu trip 2500`, `ecu on` → stays on with the 0.25 A load
- [ ] `ecu off`, remove the resistor

### Current calibration (U1 and U3)

The multimeter in series is the reference; the resistors only set the test
currents, so their exact values don't matter. One setup loads both current
monitors at once:

- load resistor on **J2** (where the idle valve plugs in)
- jumper from J0 **VW-23** to a J0 `GND` terminal (stands in for the ECU's
  low-side valve driver)
- multimeter in series with the supply lead, on its 10 A range; supply limit **1.5 A**

Current then flows `+12V SW` → J2 → load → RS2 → VW-23 → GND: U3 reads it as
`valve_a`, U1 as `ecu_a` (plus ~1 mA of the board's own draw). At each point,
`ecu on`, wait a second, then `read` three times and note the meter at the
same moment. The resistors heat up and the current drifts slightly, and the
INA226 averages over ~0.14 s, so take readings, not one snapshot. `ecu off`
before changing the load.

| Load | Expected | Meter (A) | `ecu_a` | `valve_a` | U1 error % | U3 error % |
|---|---|---|---|---|---|---|
| none (`ecu on`, J2 empty) | ~0.001 A | | | | — | — |
| 47 Ω | ~0.25 A | | | | | |
| 22 Ω | ~0.55 A | | | | | |
| 2 × 22 Ω in parallel | ~1.1 A | | | | | |

Error % = (reading − meter) ÷ meter × 100.

**What counts as good enough:** RS1/RS2 are 1 % parts and the INA226 adds
~0.1 %, so up to about ±1 % is expected. A typical multimeter's A range is
itself only 0.5–1.5 % accurate, so errors inside the meter's own tolerance
are noise, not something to correct. Worth correcting: an error that is
**consistent** across the three loads (same sign, similar size) and clearly
larger than the meter's tolerance. Note the per-sensor average; the firmware
uses the nominal 0.020 Ω / 0.033 Ω and has no correction factor yet, which
would be a small addition once these numbers exist.

- [ ] Calibration table filled in; `ecu off`, remove the load and the VW-23 jumper

## Stage 6 — Real ECU

Use a spare ECU first if you can get one. Supply limit **1 A**, J2 (idle valve)
still empty, knock pigtail not yet connected. Wire J0 to the ECU connector.

Before switching on, with the ECU connected and the bench unpowered, check
the harness once with the ohmmeter: each J0 `GND` terminal to the ECU's
ground pins (VW-6/13/19), and no short between `+12V SW` and ground.

- [ ] `ecu on` → ECU current (`read` `ecu_a`): record it (expected a few hundred mA)
- [ ] `read` `afm_ref_mv` ≈ 5000 (the ECU's airflow-meter reference)
- [ ] Set starting values for a warm idle: `dac water 800`, `dac air 1800`,
      `dac afm 1000`, `dac lambda 450`, `idle on`, then `rpm 850`. These are
      guesses; how DAC millivolts map to temperatures depends on question 4.
- [ ] `capture` → `ign_n` and `inj_n` count up; `ign_period_us` ≈ the crank
      reference period (35294 µs at 850 rpm, 2 ppr)
- [ ] Scope VW-25 (ignition) and VW-12 (injector) against VW-18 and compare
      with `capture`'s `_low_us` and angles (within a few µs / ~0.1°)

**Settle the open questions** (write the answers in the table below):

1. **Hall pulses per crank revolution and duty.** Per the user's own
   distributor HiL notes ("DIZZY_FOUR_CYLINDER"): a 30 Hz, 50% duty square
   wave at 900 rpm, i.e. 2 pulses per crank rev -- matching the firmware
   defaults already. Confirm anyway with a scope on VW-18 at idle: ppr = Hall
   frequency ÷ (rpm ÷ 60); duty = high time ÷ period. At the expected idle of
   800 rpm that's 26.7 Hz. Set them with `crank ppr` / `crank duty` if different.
2. **Which VW-18 edge is the reference.** With the crank running, note
   `ign_fall_deg`/`ign_rise_deg` at `crank duty 50`, then at `crank duty 30`
   and `crank duty 70`. If the angles stay put, the ECU times from the falling
   edge (what the firmware assumes). If they shift with the duty, it uses
   the rising edge.
3. **Which ignition edge is the spark.** Raise `rpm` in steps from 850 to
   4000 and note `ign_low_us` and both angles. The coil's dwell is held
   roughly constant in *time*: if `ign_low_us` stays roughly constant (a few
   ms) while rpm changes, the low phase is the dwell and its end,
   `ign_rise_deg`, is the spark. If instead the high phase stays constant in
   time, it's the other way round. The spark angle should then show a
   plausible advance curve as rpm rises.
4. **NTC pull-up inside the ECU.** `sensor water open` → measure J0 VW-10 to
   GND: ~5 V means the ECU has a pull-up. Then `sensor water conn` with
   `dac water 1000` and measure VW-10 again (V₁):
   pull-up R ≈ (V_open − V₁) × 220 Ω ÷ (V₁ − 1.000 V). Same for VW-9 (air).
5. **Knock input.** Wire TP1 → VW-4 and TP2 → VW-5. At `rpm 3000`,
   `knock 7000`, `burst 10 30`, compare the spark angle (from question 3)
   with `burst off`: if the ECU's knock control reacts, the spark retards
   (moves later). No change can also mean the amplitude is too low or the
   window/frequency is wrong; try other `burst` angles and `knock` 5000–9000.
6. **Idle valve.** Plug the valve into J2, raise the supply limit to 3 A.
   `read` `valve_a` should follow what the ECU does, e.g. more current with a
   cold engine (`dac water 3000`) than warm (`dac water 800`).

## Results

| Question | Result | Date |
|---|---|---|
| Hall pulses per crank revolution (expected 2, per DIZZY_FOUR_CYLINDER notes) | | |
| Hall duty, % high (expected 50, per DIZZY_FOUR_CYLINDER notes) | | |
| Reference edge (firmware uses VW-18 falling) | | |
| Spark edge (`ign_fall_deg` or `ign_rise_deg`) | | |
| NTC pull-up in the ECU (V_open, R) — air / water | | |
| ECU current at idle | | |
| `dac air 3300` actual output | | |
| Knock amplitude at TP1, 1 kHz / 7 kHz | | |
| Knock detected by the ECU (retard seen?) | | |
| OLED controller (SSD1306 / SH1106) | | |
| Current error, U1 / U3 (average %, from the calibration table) | | |
| Anything that needed rework | | |

Once the answers are in, the firmware defaults (`CRANK_PPR_DEFAULT`,
`CRANK_DUTY_DEFAULT` in `firmware/src/crank.h`) and the open-question notes in
`firmware/README.md` get updated to match. That's also the point where a
first tagged firmware release makes sense.

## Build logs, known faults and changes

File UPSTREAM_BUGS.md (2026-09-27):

# circuit-synth upstream bug reports

Bugs found in [circuit-synth](https://github.com/circuit-synth/circuit-synth)
while generating this board's schematic, and what became of them.

## Filed

### #619: pins sharing a name collapse into one connection

https://github.com/circuit-synth/circuit-synth/issues/619 (filed 2026-09-27)

`src/circuit_synth/kicad/sch_gen/circuit_loader.py` identifies a connected
pin by its **name** before its **number**. Names repeat (USB-C: two `D+`,
two `D-`; a Pico module: eight `GND`), so all same-named pins of a component
collapse into one connection and only one of them gets wired. Reproduced on
v0.12.1 (unchanged on `main` 3aaff18) with a USB-C connector: pin B6 (second
`D+`) is left unconnected, confirmed by KiCad 10 ERC. Fix: prefer the pin
number; verified locally. Probably also the root cause of upstream #35.

## Not filed

### Sheet pin placed 1.27 mm from its hierarchical label (false alarm)

`schematic_writer.py` writes each sheet pin 1.27 mm inside the sheet's right
edge while its hierarchical label sits on the edge. This looked like broken
connectivity, but KiCad snaps sheet pins onto the sheet border when it loads
the file, so the pin and label do coincide. A two-sheet reproduction on
v0.12.1 passes KiCad 10 ERC without any sheet-pin errors, and moving the
label to the pin's written position actually breaks the connection. Harmless
as far as KiCad is concerned; not reported.

### Fixed upstream / out of scope

Found on the old PyPI release 0.1.0 and fixed by v0.12.1: pin-level labels
of the wrong type, a `(ratsnest ...)` token KiCad can't open, and a
duplicated `(paper ...)` token. Default paper size and placement overflow
belong to the PCB/placement code, which v0.12.1 no longer ships in the open
version.

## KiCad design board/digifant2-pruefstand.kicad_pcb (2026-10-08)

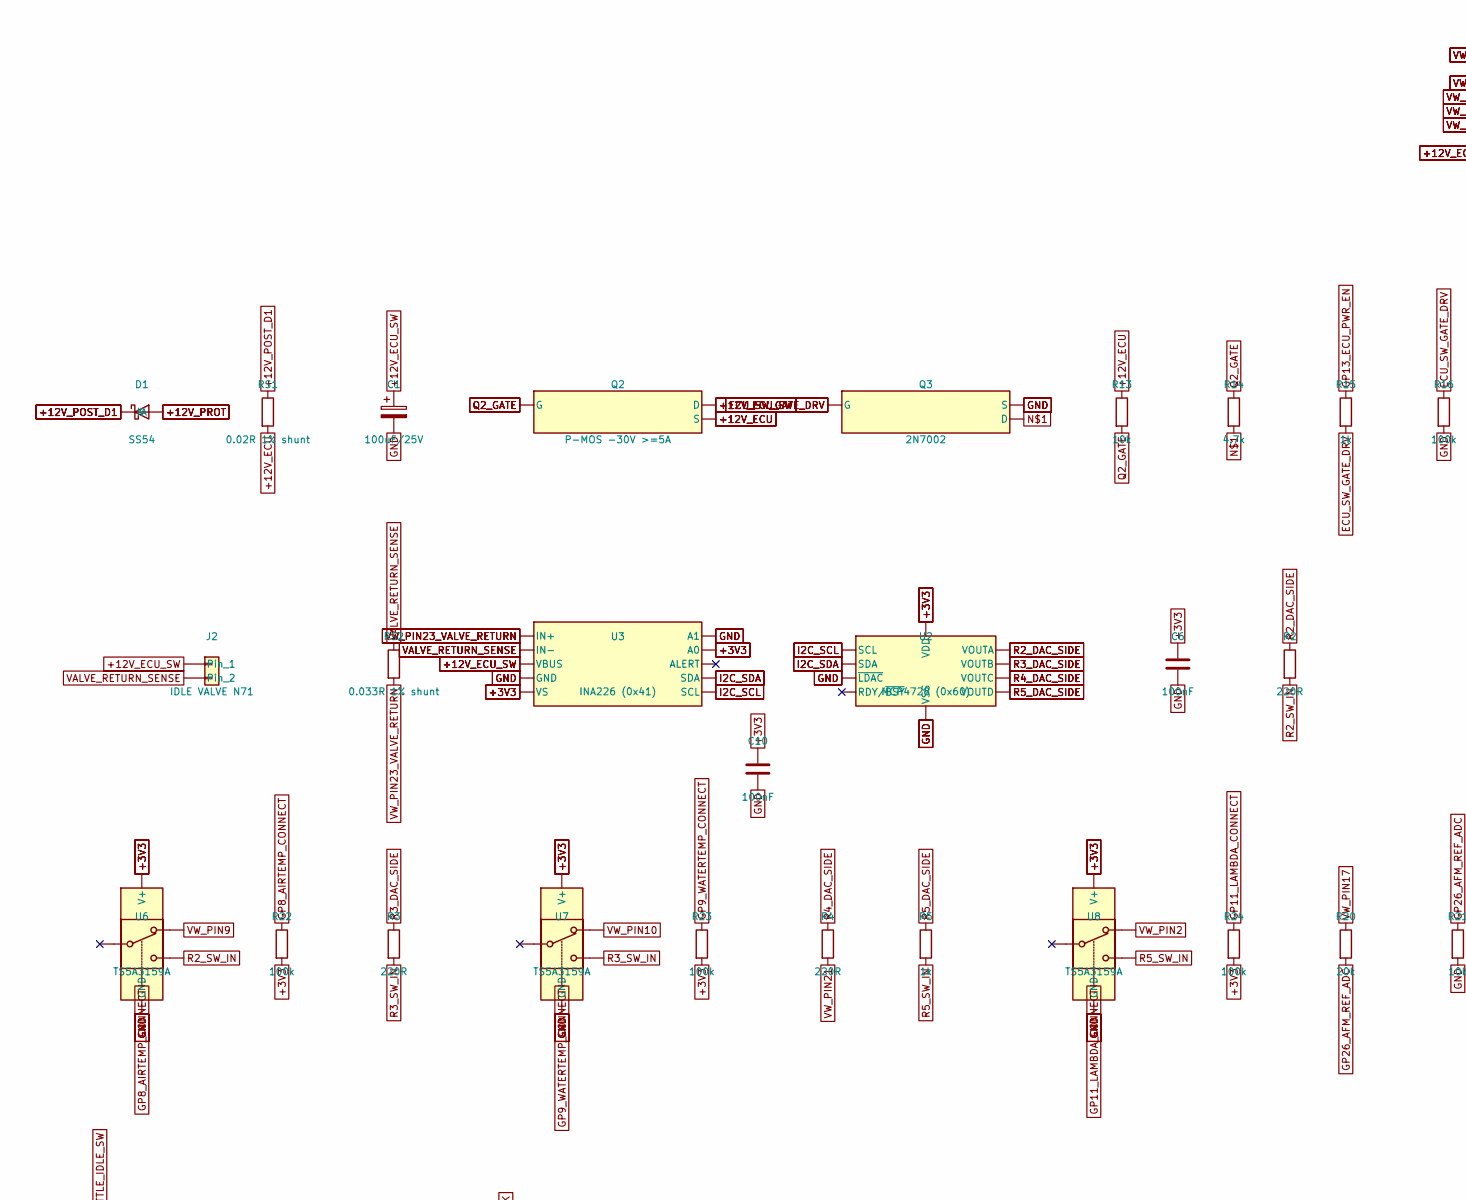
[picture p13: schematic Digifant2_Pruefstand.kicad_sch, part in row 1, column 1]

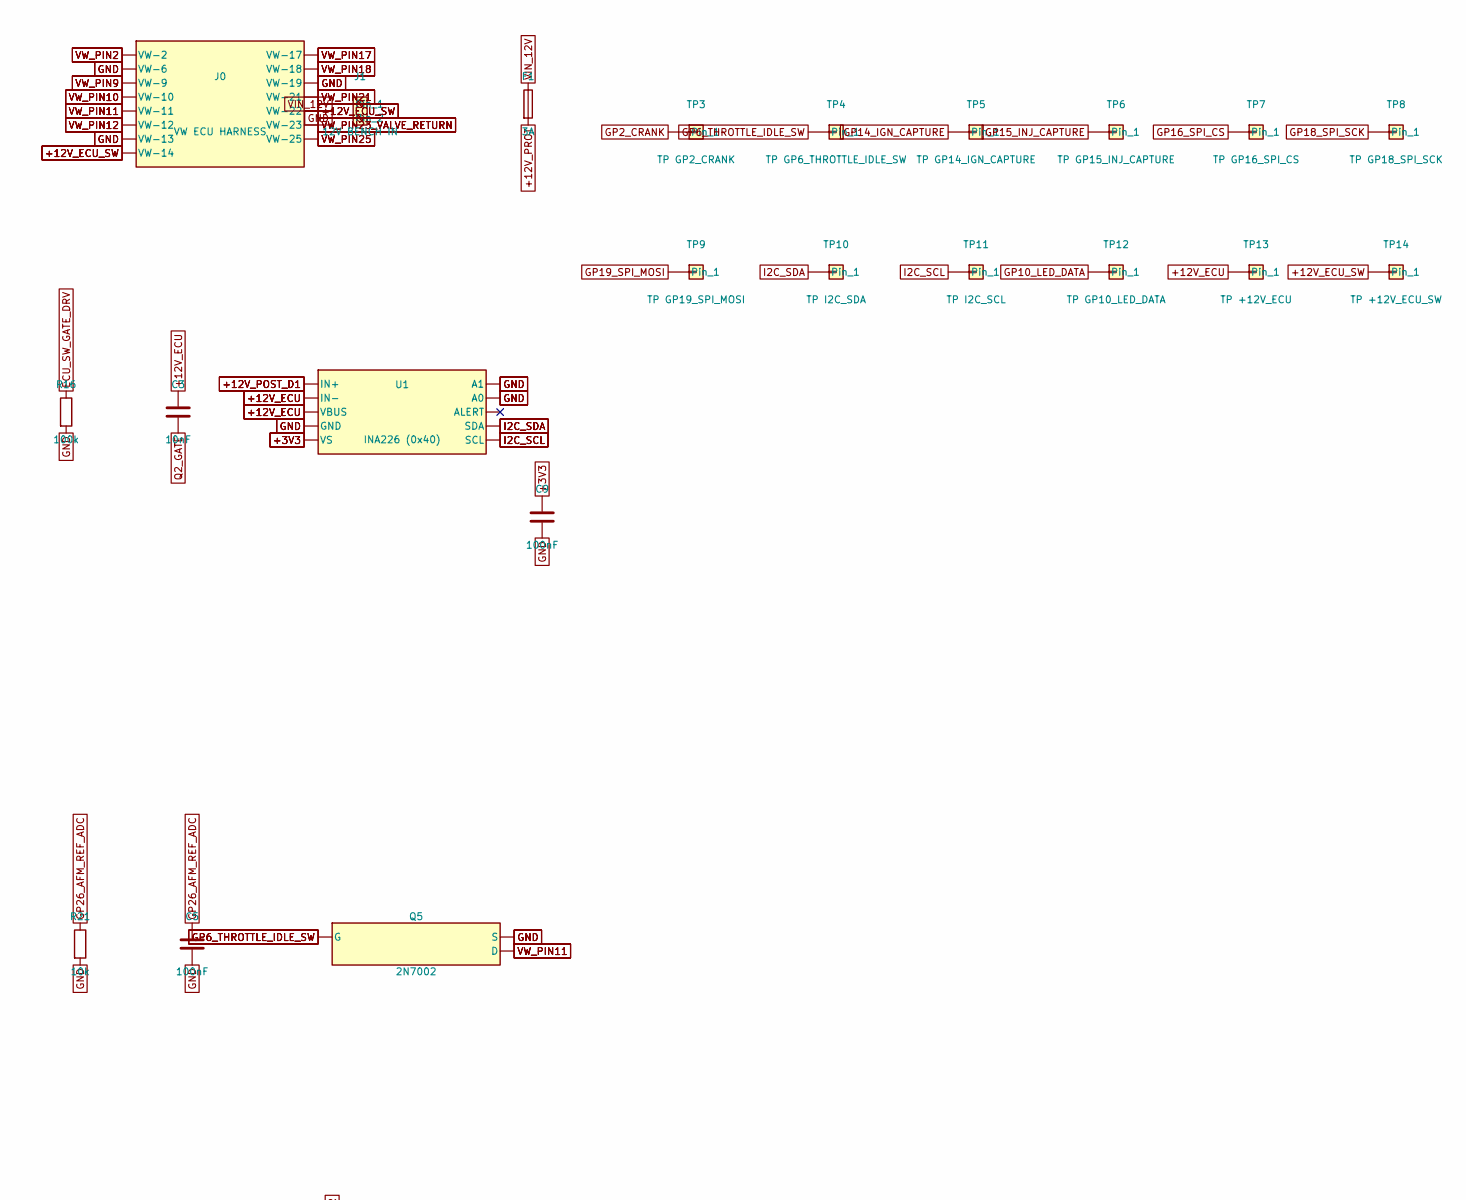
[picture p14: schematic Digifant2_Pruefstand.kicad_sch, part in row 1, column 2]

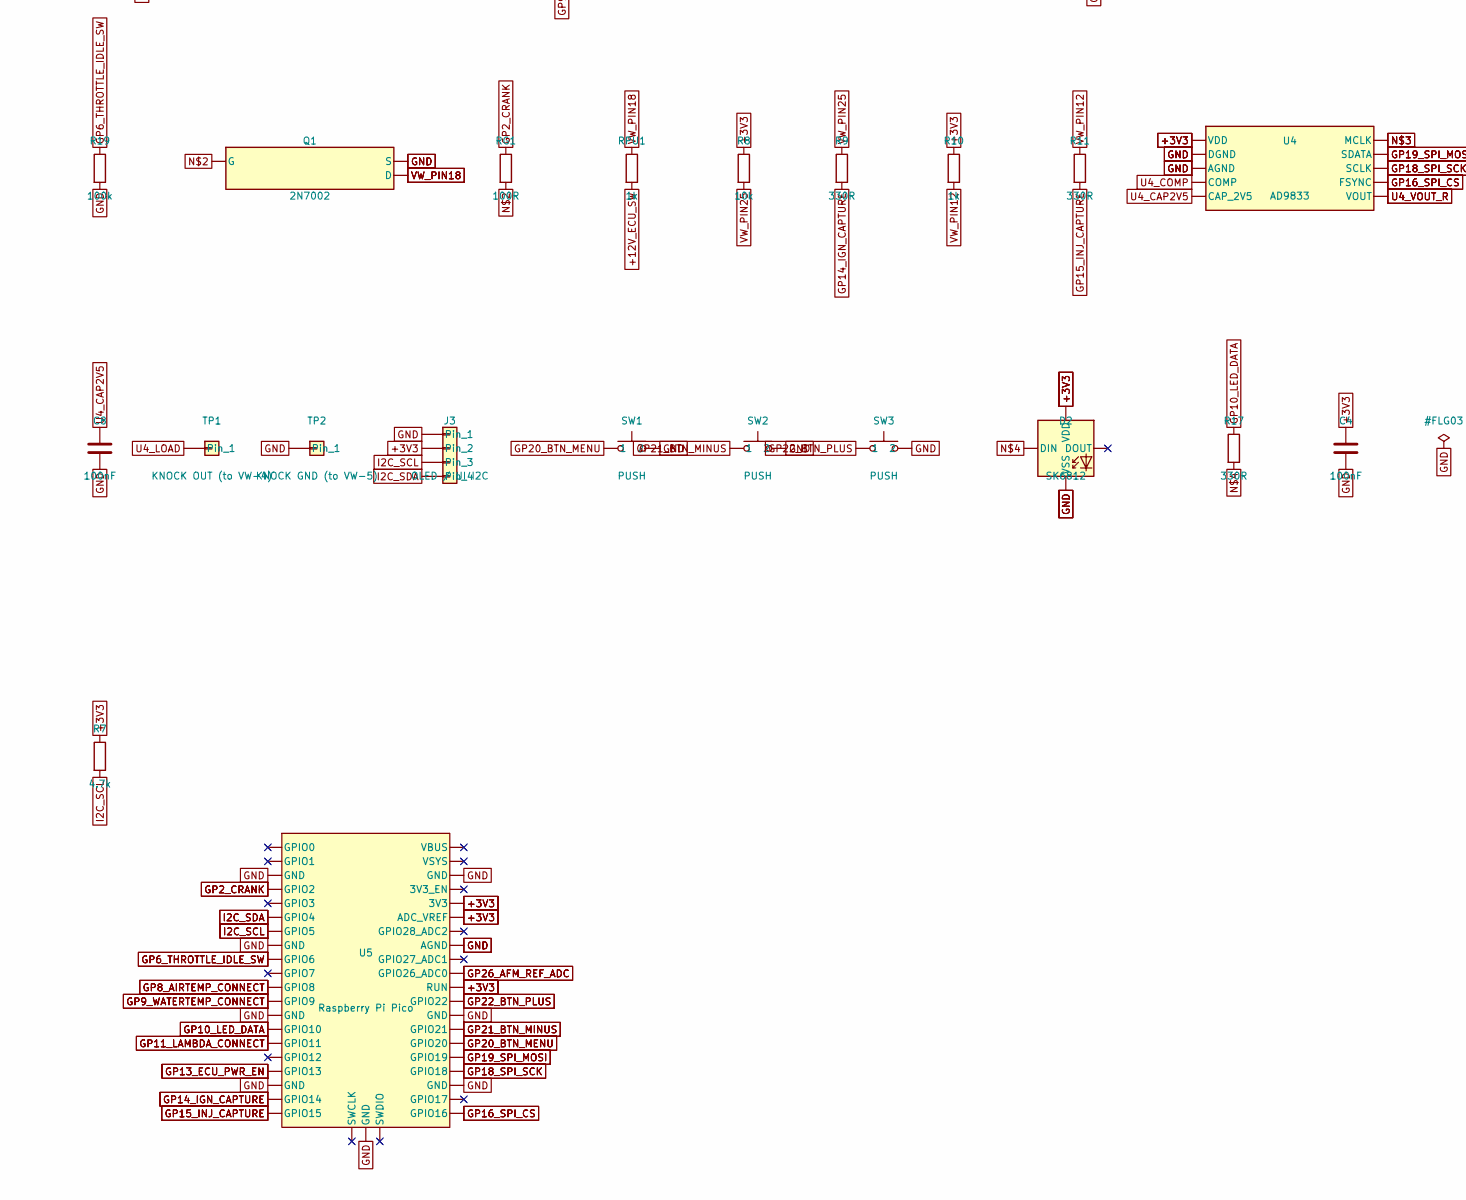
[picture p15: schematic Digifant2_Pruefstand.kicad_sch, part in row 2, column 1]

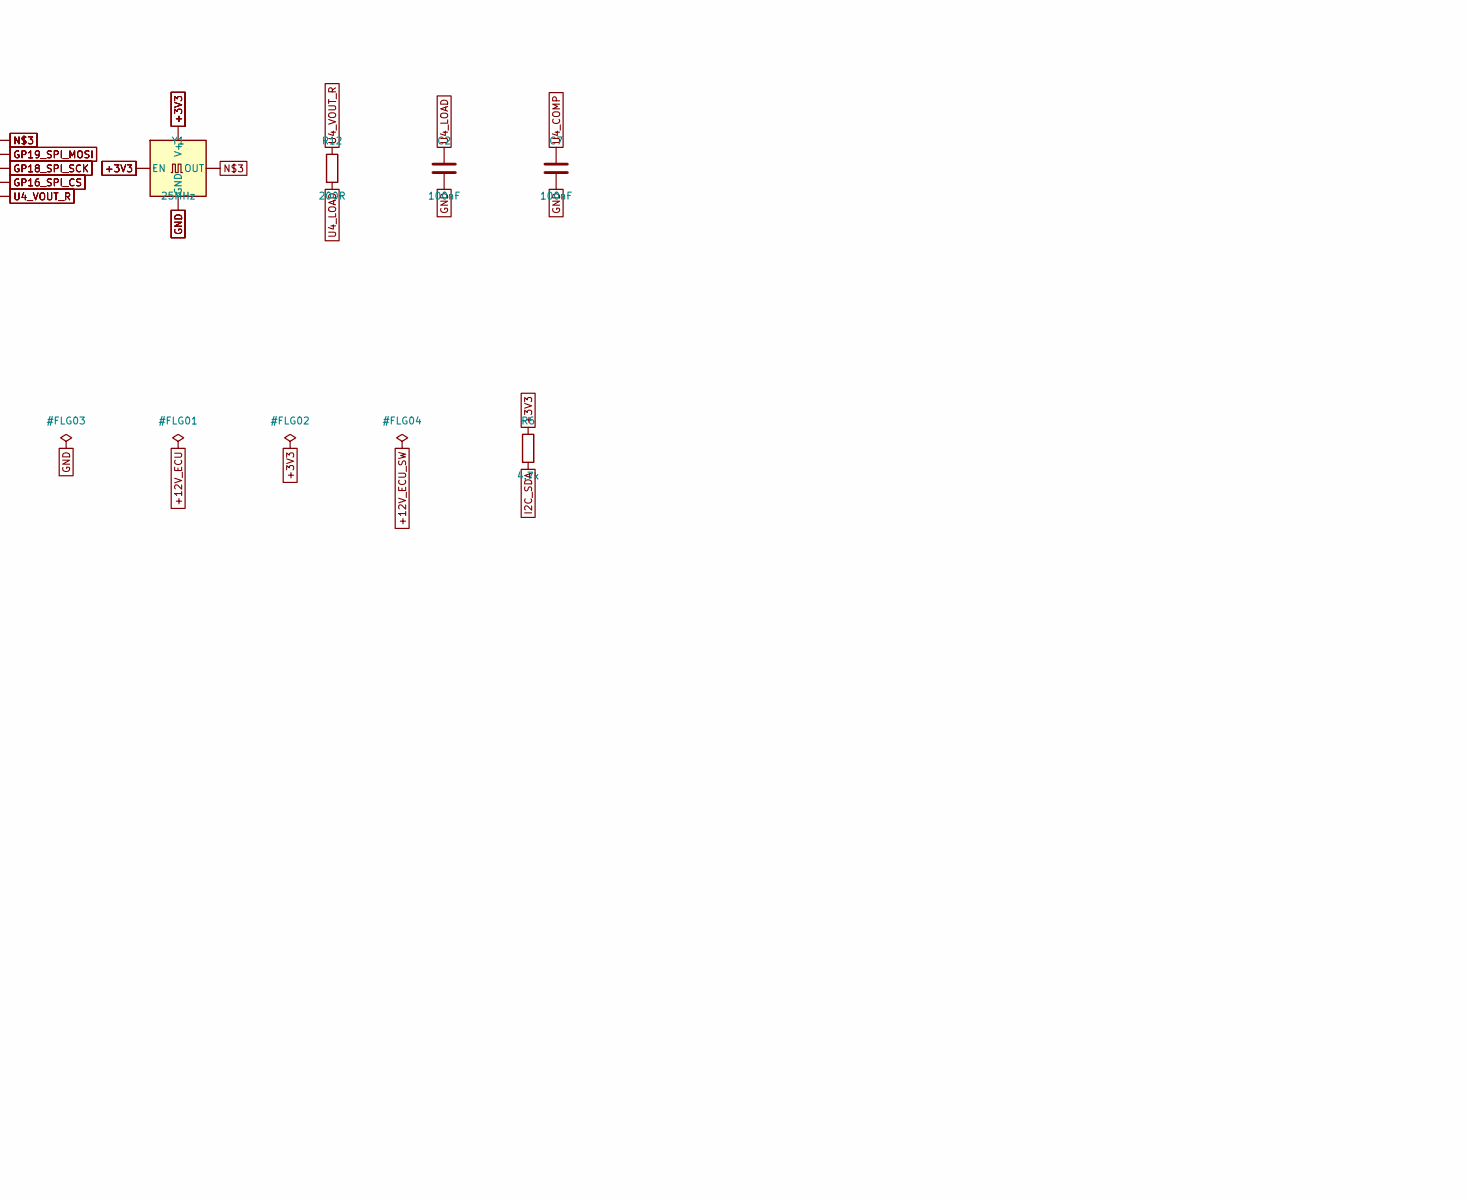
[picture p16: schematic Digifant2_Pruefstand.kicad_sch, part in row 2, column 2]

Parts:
C1: 100uF/25V; CP_Radial_D8.0mm_P3.50mm
C2, C4, C5, C6, C7, C8, C9, C10: 100nF; C_0805_2012Metric
C3: 10nF; C_0805_2012Metric
D1: SS54; D_SMC
D2: SK6812; LED_SK6812_PLCC4_5.0x5.0mm_P3.2mm
F1: 3A; Fuse_1206_3216Metric
J0: VW ECU HARNESS; TerminalBlock_MaiXu_MX126-5.0-15P_1x15_P5.00mm
J1: 12V BENCH IN; TerminalBlock_bornier-2_P5.08mm
J2: IDLE VALVE N71; JST_XH_B2B-XH-A_1x02_P2.50mm_Vertical
J3: OLED / UI I2C; PinHeader_1x04_P2.54mm_Vertical
Q1, Q3, Q5: 2N7002; SOT-23
Q2: P-MOS -30V >=5A; TO-252-2
R2, R3, R4: 220R; R_0805_2012Metric
R5, R10, R15: 1k; R_0805_2012Metric
R6, R7, R14: 4.7k; R_0805_2012Metric
R8, R13, R21: 10k; R_0805_2012Metric
R9, R11, R17: 330R; R_0805_2012Metric
R12: 200R; R_0805_2012Metric
R16, R19, R22, R23, R24: 100k; R_0805_2012Metric
R20: 20k; R_0805_2012Metric
RG1: 100R; R_0805_2012Metric
RPU1: 1k; R_0805_2012Metric
RS1: 0.02R 1% shunt; R_2512_6332Metric
RS2: 0.033R 1% shunt; R_2512_6332Metric
SW1, SW2, SW3: PUSH; SW_PUSH_6mm
TP1: KNOCK OUT (to VW-4); TestPoint_THTPad_D1.5mm_Drill0.7mm
TP2: KNOCK GND (to VW-5); TestPoint_THTPad_D1.5mm_Drill0.7mm
TP3: TP GP2_CRANK; TestPoint_THTPad_D1.5mm_Drill0.7mm
TP4: TP GP6_THROTTLE_IDLE_SW; TestPoint_THTPad_D1.5mm_Drill0.7mm
TP5: TP GP14_IGN_CAPTURE; TestPoint_THTPad_D1.5mm_Drill0.7mm
TP6: TP GP15_INJ_CAPTURE; TestPoint_THTPad_D1.5mm_Drill0.7mm
TP7: TP GP16_SPI_CS; TestPoint_THTPad_D1.5mm_Drill0.7mm
TP8: TP GP18_SPI_SCK; TestPoint_THTPad_D1.5mm_Drill0.7mm
TP9: TP GP19_SPI_MOSI; TestPoint_THTPad_D1.5mm_Drill0.7mm
TP10: TP I2C_SDA; TestPoint_THTPad_D1.5mm_Drill0.7mm
TP11: TP I2C_SCL; TestPoint_THTPad_D1.5mm_Drill0.7mm
TP12: TP GP10_LED_DATA; TestPoint_THTPad_D1.5mm_Drill0.7mm
TP13: TP +12V_ECU; TestPoint_THTPad_D1.5mm_Drill0.7mm
TP14: TP +12V_ECU_SW; TestPoint_THTPad_D1.5mm_Drill0.7mm
U1: INA226 (0x40); MSOP-10_3x3mm_P0.5mm
U2: MCP4728 (0x60); MSOP-10_3x3mm_P0.5mm
U3: INA226 (0x41); MSOP-10_3x3mm_P0.5mm
U4: AD9833; MSOP-10_3x3mm_P0.5mm
U5: Raspberry Pi Pico; RPi_Pico_SMD_TH
U6, U7, U8: TS5A3159A; SOT-23-6
Y1: 25MHz; Oscillator_SMD_EuroQuartz_XO91-4Pin_7.0x5.0mm

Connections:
+12V_ECU: C3.1, Q2.3 (S), R13.1, RS1.2, TP13.1, U1.8 (VBUS), U1.9 (IN-)
+12V_ECU_SW: C1.1, J0.8 (VW-14), J0.13 (VW-22), J2.1, Q2.2 (D), RPU1.2, TP14.1, U3.8 (VBUS)
+12V_POST_D1: D1.1 (K), RS1.1, U1.10 (IN+)
+12V_PROT: D1.2 (A), F1.2
ECU_SW_GATE_DRV: Q3.1 (G), R15.2, R16.1
GP2_CRANK: RG1.1, TP3.1, U5.4 (GPIO2)
GP6_THROTTLE_IDLE_SW: Q5.1 (G), R19.1, TP4.1, U5.9 (GPIO6)
GP8_AIRTEMP_CONNECT: R22.1, U5.11 (GPIO8), U6.6
GP9_WATERTEMP_CONNECT: R23.1, U5.12 (GPIO9), U7.6
GP10_LED_DATA: R17.1, TP12.1, U5.14 (GPIO10)
GP11_LAMBDA_CONNECT: R24.1, U5.15 (GPIO11), U8.6
GP13_ECU_PWR_EN: R15.1, U5.17 (GPIO13)
GP14_IGN_CAPTURE: R9.2, TP5.1, U5.19 (GPIO14)
GP15_INJ_CAPTURE: R11.2, TP6.1, U5.20 (GPIO15)
GP16_SPI_CS: TP7.1, U4.8 (FSYNC), U5.21 (GPIO16)
GP18_SPI_SCK: TP8.1, U4.7 (SCLK), U5.24 (GPIO18)
GP19_SPI_MOSI: TP9.1, U4.6 (SDATA), U5.25 (GPIO19)
GP20_BTN_MENU: SW1.1, U5.26 (GPIO20)
GP21_BTN_MINUS: SW2.1, U5.27 (GPIO21)
GP22_BTN_PLUS: SW3.1, U5.29 (GPIO22)
GP26_AFM_REF_ADC: C5.1, R20.2, R21.1, U5.31 (GPIO26_ADC0)
I2C_SCL: J3.3, R7.2, TP11.1, U1.5 (SCL), U2.2 (SCL), U3.5 (SCL), U5.7 (GPIO5)
I2C_SDA: J3.4, R6.2, TP10.1, U1.4 (SDA), U2.3 (SDA), U3.4 (SDA), U5.6 (GPIO4)
unnamed: Q3.3 (D), R14.2
unnamed: Q1.1 (G), RG1.2
unnamed: U4.5 (MCLK), Y1.3 (OUT)
unnamed: D2.2 (DIN), R17.2
Q2_GATE: C3.2, Q2.1 (G), R13.2, R14.1
R2_DAC_SIDE: R2.1, U2.6 (VOUTA)
R2_SW_IN: R2.2, U6.1
R3_DAC_SIDE: R3.1, U2.7 (VOUTB)
R3_SW_IN: R3.2, U7.1
R4_DAC_SIDE: R4.1, U2.8 (VOUTC)
R5_DAC_SIDE: R5.1, U2.9 (VOUTD)
R5_SW_IN: R5.2, U8.1
U4_CAP2V5: C8.1, U4.3 (CAP_2V5)
U4_COMP: C7.1, U4.1 (COMP)
U4_LOAD: C2.1, R12.2, TP1.1
U4_VOUT_R: R12.1, U4.10 (VOUT)
VALVE_RETURN_SENSE: J2.2, RS2.1, U3.9 (IN-)
VIN_12V: F1.1, J1.1
VW_PIN2: J0.1 (VW-2), U8.3
VW_PIN9: J0.3 (VW-9), U6.3
VW_PIN10: J0.4 (VW-10), U7.3
VW_PIN11: J0.5 (VW-11), Q5.3 (D)
VW_PIN12: J0.6 (VW-12), R10.2, R11.1
VW_PIN17: J0.9 (VW-17), R20.1
VW_PIN18: J0.10 (VW-18), Q1.3 (D), RPU1.1
VW_PIN21: J0.12 (VW-21), R4.2
VW_PIN23_VALVE_RETURN: J0.14 (VW-23), RS2.2, U3.10 (IN+)
VW_PIN25: J0.15 (VW-25), R8.2, R9.1

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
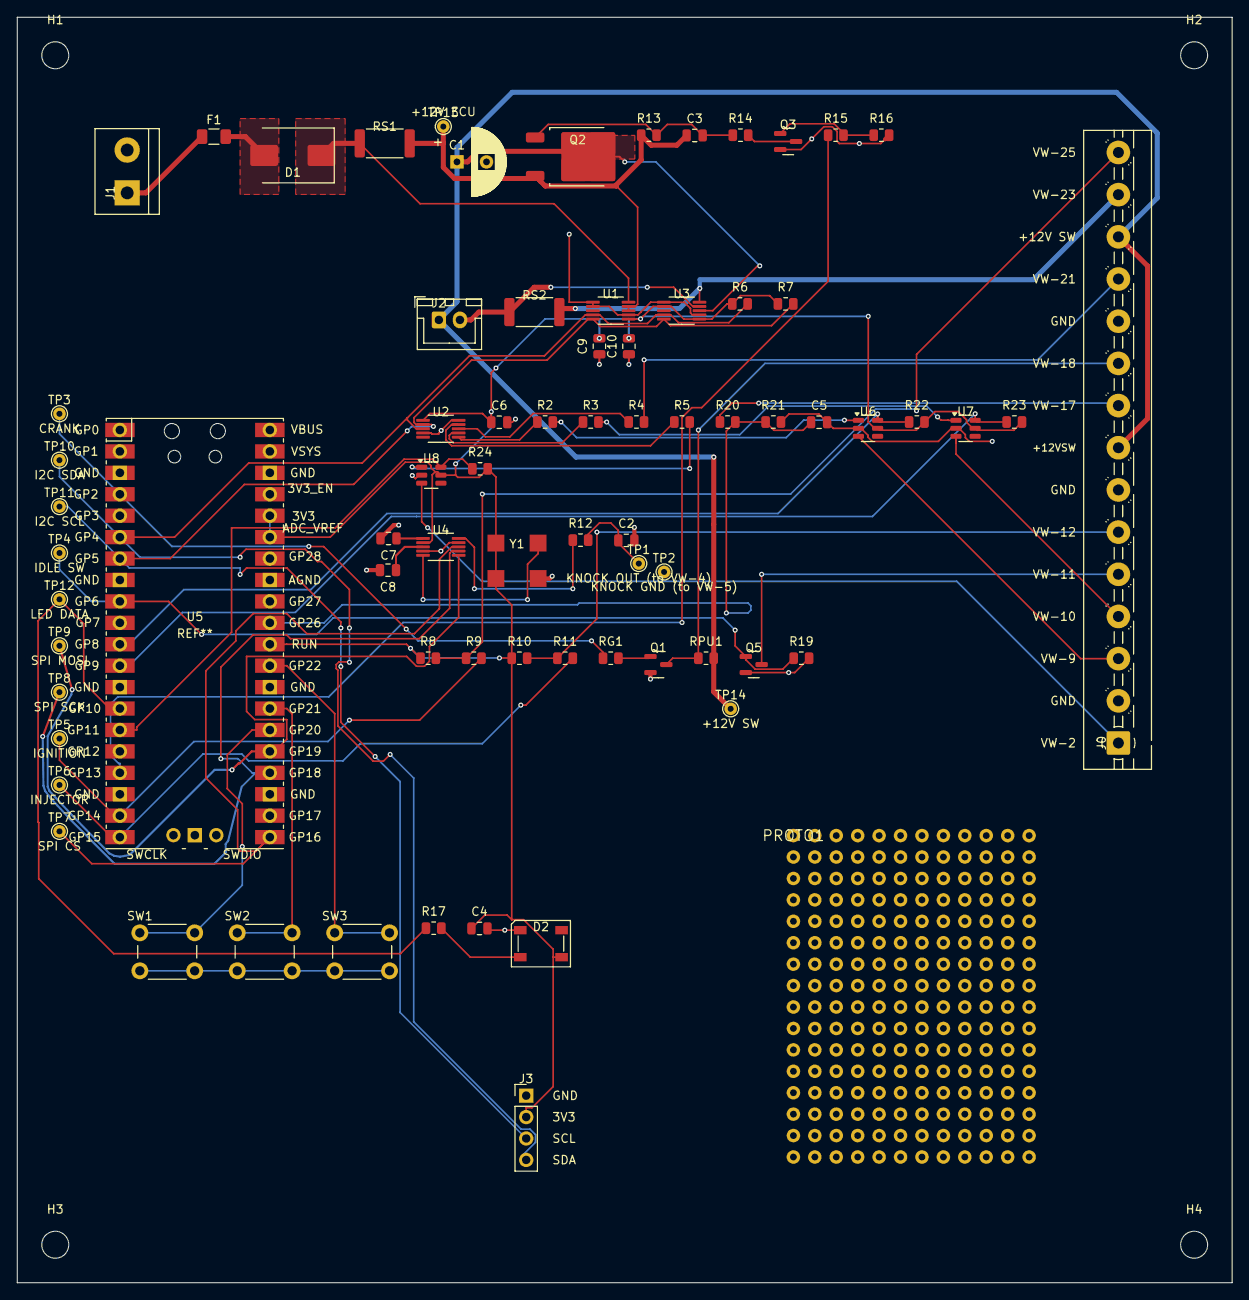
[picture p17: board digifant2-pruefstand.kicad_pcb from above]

Board: 2 copper layers, 144.0 x 150.0 mm, 78 parts (0 on the bottom side), 53 nets.

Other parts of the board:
H1, H2, H3, H4: MountingHole_3.2mm_M3
PROTO1: PROTO AREA

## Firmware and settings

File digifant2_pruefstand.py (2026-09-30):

"""
circuit-synth port of the Digifant-2 Pruefstand Signal-Simulator + Erfassungseinheit,
prototyping whether circuit-synth is a better authoring path than hand-rolled kiutils
S-expression generation (see ../digifant2-pruefstand-kicad/gen_kicad.py + its README
for the bug history that motivated this comparison).

Same scope as the original: Signal-Simulator + Erfassungseinheit only. EPROM emulator
bus and the knock-sensor's real connector pin are still explicitly out of scope.
"""
from circuit_synth import circuit, Component, Net


def power_section(vin_12v, gnd, ecu_12v, ecu_sw):
    """Bench 12V in -> fuse -> reverse-polarity protect -> shunt-sensed ECU rail.
    ecu_12v is the sensed rail (RS1 output); ecu_sw is the switched rail downstream
    of the Q2 load switch that actually feeds the ECU harness -- C1 bulk sits there
    so it also provides (and is measured through RS1 as) the ECU's cold-boot inrush."""
    j1 = Component("Connector:Screw_Terminal_01x02", ref="J1", value="12V BENCH IN",
                    footprint="TerminalBlock:TerminalBlock_bornier-2_P5.08mm")
    # 3A (not 2A): worst-case bench draw is ECU (~0.6A) + cold idle-valve peak
    # (~1.8A) + board logic (~0.1A) ~= 2.5A, which nuisance-trips a 2A fuse.
    f1 = Component("Device:Fuse", ref="F1", value="3A",
                    footprint="Fuse:Fuse_1206_3216Metric")
    # SS54 (not SS34): 5A part in the same SMC body -- SS34's 3A rating leaves no
    # margin over the ~2.5A peak and it runs ~1.3W hot at that current.
    d1 = Component("Device:D_Schottky", ref="D1", value="SS54",
                    footprint="Diode_SMD:D_SMC")
    # Device:R (2-pin), not Device:R_Shunt: the R_Shunt symbol has 4 pins (Kelvin
    # sense taps 3/4) but there is no stock 4-pad 2512 footprint, so pins 3/4 landed
    # nowhere on the PCB (kicad-cli DRC schematic-parity caught it). This design ties
    # sense to the power path anyway; for accuracy, hand-route U1's IN+/IN- as their
    # own traces tapped right at the RS1 pads during layout.
    rs1 = Component("Device:R", ref="RS1", value="0.02R 1% shunt",
                     footprint="Resistor_SMD:R_2512_6332Metric")
    c1 = Component("Device:C_Polarized", ref="C1", value="100uF/25V",
                    footprint="Capacitor_THT:CP_Radial_D8.0mm_P3.50mm")

    j1[1] += vin_12v
    j1[2] += gnd
    f1[1] += vin_12v
    protected = Net("+12V_PROT")
    f1[2] += protected
    d1["A"] += protected

    # Route through the shunt explicitly as its own net so INA226 (U1) sees both ends.
    post_diode = Net("+12V_POST_D1")
    d1["K"] += post_diode

    rs1[1] += post_diode
    rs1[2] += ecu_12v
    c1[1] += ecu_sw
    c1[2] += gnd

    return {"rs1": rs1}


def ecu_power_switch(rail_in, rail_out, gnd, gp_enable):
    """High-side P-FET load switch cutting all bench power to the ECU harness.

    Fail-safe OFF: R16 holds the driver gate low whenever the Pico is unpowered or
    GP13 is low, so the ECU rail only comes up on an explicit firmware command.
    This is what lets the bench exercise ECU cold-boot behaviour and drop the rail
    on an overcurrent reading from U1 (RS1 sees the switch + every downstream load).
    Q3 (2N7002) level-shifts the 3V3 GPIO to the 12V gate swing; R13 pulls the
    P-FET gate to its source (off) and R14 limits Q3's sink current; C3/R13 set a
    ~100us turn-on slope to tame inrush."""
    q2 = Component("Custom_Digifant2:Q_PMOS_DPAK", ref="Q2", value="P-MOS -30V >=5A",
                    footprint="Package_TO_SOT_SMD:TO-252-2")
    q3 = Component("Custom_Digifant2:Q_NMOS_2N7002", ref="Q3", value="2N7002",
                    footprint="Package_TO_SOT_SMD:SOT-23")
    r13 = Component("Device:R", ref="R13", value="10k", footprint="Resistor_SMD:R_0805_2012Metric")
    r14 = Component("Device:R", ref="R14", value="4.7k", footprint="Resistor_SMD:R_0805_2012Metric")
    r15 = Component("Device:R", ref="R15", value="1k", footprint="Resistor_SMD:R_0805_2012Metric")
    r16 = Component("Device:R", ref="R16", value="100k", footprint="Resistor_SMD:R_0805_2012Metric")
    c3 = Component("Device:C", ref="C3", value="10nF", footprint="Capacitor_SMD:C_0805_2012Metric")

    gate = Net("Q2_GATE")
    gdrv = Net("ECU_SW_GATE_DRV")
    q2["S"] += rail_in
    q2["D"] += rail_out
    q2["G"] += gate
    r13[1] += rail_in
    r13[2] += gate
    c3[1] += rail_in
    c3[2] += gate
    r14[1] += gate
    r14[2] += q3["D"]
    q3["S"] += gnd
    q3["G"] += gdrv
    r15[1] += gp_enable
    r15[2] += gdrv
    r16[1] += gdrv
    r16[2] += gnd


def status_led(vcc_3v3, gnd, gp_data):
    """Single addressable RGB pixel (SK6812, 5050 SMD) on ONE GPIO, driven by the
    Pico's PIO. SK6812 runs straight off 3V3 (VIH = 0.7*VDD ~= 2.3V, so the 3V3
    GPIO is in spec -- no level shifter, no separate 5V rail, and 2 GPIOs freed vs
    a plain 3-pin RGB LED). Chain from D2's DOUT to add more pixels later.
    Firmware picks the meaning, e.g. green = idle / blue = sim running / red = fault."""
    d2 = Component("LED:SK6812", ref="D2", value="SK6812",
                    footprint="LED_SMD:LED_SK6812_PLCC4_5.0x5.0mm_P3.2mm")
    r17 = Component("Device:R", ref="R17", value="330R", footprint="Resistor_SMD:R_0805_2012Metric")
    c4 = Component("Device:C", ref="C4", value="100nF", footprint="Capacitor_SMD:C_0805_2012Metric")
    r17[1] += gp_data
    r17[2] += d2["DIN"]
    d2["VDD"] += vcc_3v3
    d2["VSS"] += gnd
    c4[1] += vcc_3v3
    c4[2] += gnd


def ecu_current_sense(post_shunt_hi, post_shunt_lo, gnd, vcc_3v3, sda, scl):
    """INA226 U1: total ECU current across RS1 AND the ECU supply voltage.
    addr A0=GND, A1=GND -> 0x40. VBUS is tied to IN- (the load side of the shunt,
    = +12V_ECU) so the bus-voltage channel reads the ECU's actual rail and
    bus*current gives real load power. There is still a small (~0.1V @ 2A) drop
    across the Q2 load switch between here and VW-14 -- account for it in firmware
    or, if you want the exact pin-14 voltage, move VBUS to +12V_ECU_SW (reads 0
    when the switch is open)."""
    u1 = Component("Custom_Digifant2:INA226", ref="U1", value="INA226 (0x40)",
                    footprint="Package_SO:MSOP-10_3x3mm_P0.5mm")
    u1["IN+"] += post_shunt_hi
    u1["IN-"] += post_shunt_lo
    u1["VBUS"] += post_shunt_lo
    u1["VS"] += vcc_3v3
    u1["GND"] += gnd
    u1["A0"] += gnd
    u1["A1"] += gnd
    u1["SDA"] += sda
    u1["SCL"] += scl
    # ALERT (open-drain) intentionally unused -- leave unconnected, add a manual
    # no-connect flag in KiCad (same as the Pico's unused GPIOs; circuit-synth
    # has no NC-flag API in this version).
    c9 = Component("Device:C", ref="C9", value="100nF", footprint="Capacitor_SMD:C_0805_2012Metric")
    c9[1] += vcc_3v3
    c9[2] += gnd


def idle_valve(drive_12v, valve_return_sense, valve_return_ecu, gnd, vcc_3v3, sda, scl):
    """Real used N71 idle valve as load (J2), current sensed by U3 (INA226, addr 0x41).
    valve_return_ecu is the same net as VW connector pin 23 (idle-valve return) --
    J2 sits in that current loop as the bench-mounted real load.

    RS2 is wired truly IN SERIES between the valve and VW-23/the ECU's own
    low-side driver -- not as a separate tap to GND in parallel with it (the
    original layout's bug). That parallel path let return current split between
    RS2 and the ECU's internal switch (both go to the same shared GND on this
    bench), so U3 only ever saw whatever fraction happened to take RS2's path --
    understating the true valve current, worst right when the ECU driver is ON
    and current is actually flowing. With RS2 truly in series, 100% of the
    valve's return current must cross it before reaching VW-23, so U3 reads the
    real total and the ECU's own PWM drive is undisturbed except for RS2's own
    ~60mV drop (negligible against 12V)."""
    j2 = Component("Connector_Generic:Conn_01x02", ref="J2", value="IDLE VALVE N71",
                    footprint="Connector_JST:JST_XH_B2B-XH-A_1x02_P2.50mm_Vertical")
    # 0.033R (not 0.1R): the idle valve peaks near ~1.8A, and 0.1R * 1.8A = 180mV
    # clips the INA226's +-81.92mV PGA full-scale (limit would be ~0.8A). 0.033R
    # gives ~60mV at 1.8A, ~0.11W in the 2512.
    rs2 = Component("Device:R", ref="RS2", value="0.033R 1% shunt",
                     footprint="Resistor_SMD:R_2512_6332Metric")
    u3 = Component("Custom_Digifant2:INA226", ref="U3", value="INA226 (0x41)",
                    footprint="Package_SO:MSOP-10_3x3mm_P0.5mm")

    j2[1] += drive_12v
    j2[2] += valve_return_sense
    rs2[1] += valve_return_sense
    rs2[2] += valve_return_ecu

    # IN+ (not IN-) carries the ECU-side net here: on the physical board, IN+
    # is the INA226 pin that already had a routed path to VW-23 from the
    # original (buggy) topology -- keeping it means only the sense-side needs
    # new routing, not a rip-up of the existing long run to J0. Sign of the
    # current reading is a firmware convention either way.
    u3["IN+"] += valve_return_ecu
    u3["IN-"] += valve_return_sense
    # VBUS on the valve *supply* (switched rail) so U3 also reports the voltage the
    # valve is actually fed -- the return node itself is a PWM node and not useful
    # as a bus-voltage reading.
    u3["VBUS"] += drive_12v
    u3["VS"] += vcc_3v3
    u3["GND"] += gnd
    u3["A0"] += vcc_3v3
    u3["A1"] += gnd
    u3["SDA"] += sda
    u3["SCL"] += scl
    # ALERT intentionally unused, same as U1 -- see note there.
    c10 = Component("Device:C", ref="C10", value="100nF", footprint="Capacitor_SMD:C_0805_2012Metric")
    c10[1] += vcc_3v3
    c10[2] += gnd


def afm_ref_sense(vw_pin17, gnd, adc):
    """The airflow-meter potentiometer is read ratiometrically: the ECU sources a
    reference on VW-17 and reads the wiper on VW-21. We inject the wiper voltage
    with the DAC, so firmware needs to know VW-17's actual level to scale it (and
    a drooping VW-17 is itself a useful fault indicator). R20/R21 divide VW-17
    (~5V nominal, up to ~9V worst case) into the Pico's 0-3.3V ADC; C5 filters.
    R20 20k (not 15k): ratio was 10k/25k=0.4, so the stated 9V worst case divided
    to 3.6V -- right at the ADC's absolute-max input rating (VDD+0.3V, unchanged
    between RP2040 and RP2350), zero margin. 10k/30k=0.333 puts that same worst case at 3.0V (0.6V of real
    margin) while nominal 5V still lands mid-range at 1.67V."""
    r20 = Component("Device:R", ref="R20", value="20k", footprint="Resistor_SMD:R_0805_2012Metric")
    r21 = Component("Device:R", ref="R21", value="10k", footprint="Resistor_SMD:R_0805_2012Metric")
    c5 = Component("Device:C", ref="C5", value="100nF", footprint="Capacitor_SMD:C_0805_2012Metric")
    r20[1] += vw_pin17
    r20[2] += adc
    r21[1] += adc
    r21[2] += gnd
    c5[1] += adc
    c5[2] += gnd


def throttle_switches(gnd, gp_idle, vw_pin11):
    """Corrected per the user's own hands-on HiL notes (F60 idle switch: 'Pin 6
    Masse und Pin 11'): VW-6 is NOT a second switch contact, it's the sensor/
    idle-switch common ground (wired straight to GND in main_circuit) -- there is
    only ONE idle switch, on VW-11, which the ECU pulls up internally and the
    switch (or here, Q5) pulls to VW-6/GND when idle is active ('Pin 11 auf Pin 6
    verbinden fuer Leerlauf aktiv'). No full-throttle switch is broken out.
    Q5 (2N7002, open-drain) emulates the contact under Pico control; R19 holds
    the gate low so it reads 'open' (not idle) when the Pico is unpowered."""
    q5 = Component("Custom_Digifant2:Q_NMOS_2N7002", ref="Q5", value="2N7002",
                    footprint="Package_TO_SOT_SMD:SOT-23")
    r19 = Component("Device:R", ref="R19", value="100k", footprint="Resistor_SMD:R_0805_2012Metric")
    q5["G"] += gp_idle
    r19[1] += gp_idle
    r19[2] += gnd
    q5["S"] += gnd
    q5["D"] += vw_pin11


def dac_analog_sim(vcc_3v3, gnd, sda, scl, vw_pin9, vw_pin10, vw_pin21, vw_pin2,
                   gp_conn_air, gp_conn_water, gp_conn_lambda):
    """MCP4728 U2 (0x60): intake-air NTC, coolant NTC, LMM and lambda sim, each via
    a series resistor. The two NTC channels and the lambda channel additionally
    pass a TS5A3159A SPDT analog switch (~1 ohm) so firmware can open-circuit the
    'sensor' and test the ECU's open-sensor fault detection. IN high = connected;
    R22-R24 pull IN up so the ECU sees valid sensors at power-on, pull IN low to
    disconnect (COM then goes to the open NC pin). Lambda series R is 1k (not 220R)
    to look less like an ideal voltage source to the ECU's O2 input."""
    u2 = Component("Analog_DAC:MCP4728", ref="U2", value="MCP4728 (0x60)",
                    footprint="Package_SO:MSOP-10_3x3mm_P0.5mm")
    u2["VDD"] += vcc_3v3
    u2["VSS"] += gnd
    u2["SCL"] += scl
    u2["SDA"] += sda
    u2["~{LDAC}"] += gnd
    c6 = Component("Device:C", ref="C6", value="100nF", footprint="Capacitor_SMD:C_0805_2012Metric")
    c6[1] += vcc_3v3
    c6[2] += gnd

    # dac pin, series R, Rref, VW target, connect-enable GPIO (None = hard-wired),
    # switch ref, IN-pullup ref
    chans = [
        ("VOUTA", "220R", "R2", vw_pin9,  gp_conn_air,    "U6", "R22"),
        ("VOUTB", "220R", "R3", vw_pin10, gp_conn_water,  "U7", "R23"),
        ("VOUTC", "220R", "R4", vw_pin21, None,           None, None),
        ("VOUTD", "1k",   "R5", vw_pin2,  gp_conn_lambda, "U8", "R24"),
    ]
    for dac_pin, rval, rref, vw_net, gp_conn, swref, rpuref in chans:
        r = Component("Device:R", ref=rref, value=rval,
                       footprint="Resistor_SMD:R_0805_2012Metric")
        dac_net = Net(f"{rref}_DAC_SIDE")
        u2[dac_pin] += dac_net
        r[1] += dac_net
        if gp_conn is None:
            r[2] += vw_net
            continue
        mid = Net(f"{rref}_SW_IN")
        r[2] += mid
        sw = Component("Analog_Switch:TS5A3159ADBVR", ref=swref, value="TS5A3159A",
                        footprint="Package_TO_SOT_SMD:SOT-23-6")
        rpu = Component("Device:R", ref=rpuref, value="100k",
                         footprint="Resistor_SMD:R_0805_2012Metric")
        sw["V+"] += vcc_3v3
        sw["GND"] += gnd
        sw[1] += mid       # NO -- COM<->NO when IN high (sensor connected)
        sw[3] += vw_net    # COM -> ECU pin
        # pin 4 (NC) left open -> COM floats = "sensor disconnected" when IN low
        sw[6] += gp_conn   # IN
        rpu[1] += gp_conn
        rpu[2] += vcc_3v3


def crank_driver(gpio_crank, gnd, ecu_12v, vw_pin18):
    """Q1 open-drain crank/Hallgeber signal driver, RPU1 pull-up to +12V_ECU.
    VW-18 confirmed (not VW-8) by the user's own working HiL notes: the crank
    square wave needs >=8-10V amplitude (5V is not enough) -- consistent with
    pulling up to the switched 12V rail here, not a 3.3/5V logic level."""
    # Custom_Digifant2:Q_NMOS_2N7002 (not Device:Q_NMOS): the generic symbol's pin
    # *numbers* are the letters G/D/S, which resolve fine at the schematic level but
    # don't match the real SOT-23 footprint's numeric pads 1/2/3 -- confirmed via
    # the generated PCB showing all 3 pads "unconnected" despite correct schematic
    # wiring. This part has real numeric pins (1=G, 2=S, 3=D) matching the footprint.
    q1 = Component("Custom_Digifant2:Q_NMOS_2N7002", ref="Q1", value="2N7002",
                    footprint="Package_TO_SOT_SMD:SOT-23")
    rg1 = Component("Device:R", ref="RG1", value="100R",
                     footprint="Resistor_SMD:R_0805_2012Metric")
    rpu1 = Component("Device:R", ref="RPU1", value="1k",
                      footprint="Resistor_SMD:R_0805_2012Metric")

    rg1[1] += gpio_crank
    rg1[2] += q1["G"]
    q1["S"] += gnd
    q1["D"] += vw_pin18
    rpu1[1] += vw_pin18
    rpu1[2] += ecu_12v


def edge_capture(vcc_3v3, gpio_ignition, gpio_injector, vw_pin25, vw_pin12):
    """Ignition/injector edge capture: pull-up to Pico's own 3V3, series ESD guard."""
    r8 = Component("Device:R", ref="R8", value="10k", footprint="Resistor_SMD:R_0805_2012Metric")
    r9 = Component("Device:R", ref="R9", value="330R", footprint="Resistor_SMD:R_0805_2012Metric")
    r10 = Component("Device:R", ref="R10", value="1k", footprint="Resistor_SMD:R_0805_2012Metric")
    r11 = Component("Device:R", ref="R11", value="330R", footprint="Resistor_SMD:R_0805_2012Metric")

    r8[1] += vcc_3v3
    r8[2] += vw_pin25
    r9[1] += vw_pin25
    r9[2] += gpio_ignition

    r10[1] += vcc_3v3
    r10[2] += vw_pin12
    r11[1] += vw_pin12
    r11[2] += gpio_injector


def knock_sim(vcc_3v3, gnd, spi_sck, spi_mosi, spi_cs):
    """AD9833 U4 DDS burst generator. Output now reaches a defined pair of test
    points (TP1 signal + TP2 ground) instead of dead-ending at a single bare
    pad -- J0 is already full at 15/15 positions (VW-4/5/7, the knock sensor's
    real pins, were never broken out there), so this is a small standalone tap
    meant to be wired to the ECU harness's VW-4 (signal) / VW-5 (ground, 2H)
    pins via a short external pigtail -- clipped/soldered onto both pads, not
    a proper connector housing. A 2-pin JST here would be nicer, but this
    corner of the board is criss-crossed with existing traces on both layers
    (+12V_ECU_SW, VW_PIN10/11/12, GP8/GP9/GP13/GP26 all thread through here at
    various points); every placement tried for a through-hole 2-pin connector
    shorted a different existing net. Two bare test pads (TestPoint_Pad_D1.5mm,
    same as the original TP1) are small enough to actually fit."""
    u4 = Component("Custom_Digifant2:AD9833", ref="U4", value="AD9833",
                    footprint="Package_SO:MSOP-10_3x3mm_P0.5mm")
    # Active 4-pin oscillator, not a passive 2-pin crystal: AD9833's MCLK is a
    # digital clock input and needs a driven signal, not a bare crystal needing
    # its own oscillator circuit. (The original draft had a symbol/footprint
    # mismatch here -- Device:Crystal is 2-pin, but was assigned a 4-pin
    # footprint. XO91 is the real symbol matching that 7.0x5.0mm footprint family.)
    y1 = Component("Oscillator:XO91", ref="Y1", value="25MHz",
                    footprint="Oscillator:Oscillator_SMD_EuroQuartz_XO91-4Pin_7.0x5.0mm")
    r12 = Component("Device:R", ref="R12", value="200R", footprint="Resistor_SMD:R_0805_2012Metric")
    c2 = Component("Device:C", ref="C2", value="100nF", footprint="Capacitor_SMD:C_0805_2012Metric")
    c7 = Component("Device:C", ref="C7", value="100nF", footprint="Capacitor_SMD:C_0805_2012Metric")
    c8 = Component("Device:C", ref="C8", value="100nF", footprint="Capacitor_SMD:C_0805_2012Metric")

    u4["VDD"] += vcc_3v3
    u4["DGND"] += gnd
    u4["AGND"] += gnd
    u4["MCLK"] += y1["OUT"]
    y1["V+"] += vcc_3v3
    y1["EN"] += vcc_3v3
    y1["GND"] += gnd
    u4["SCLK"] += spi_sck
    u4["SDATA"] += spi_mosi
    u4["FSYNC"] += spi_cs
    # COMP (DAC bias decouple) and CAP_2V5 (internal regulator bypass) are
    # decoupling-only pins per the datasheet -- each gets its own 100nF cap to
    # AGND, per ADI's recommended application circuit (Rev. G, Figure 33/34).
    c7[1] += u4["COMP"]
    c7[2] += gnd
    c8[1] += u4["CAP_2V5"]
    c8[2] += gnd

    vout_r = Net("U4_VOUT_R")
    u4["VOUT"] += vout_r
    r12[1] += vout_r
    load = Net("U4_LOAD")
    r12[2] += load
    c2[1] += load
    tp1 = Component("Connector_Generic:Conn_01x01", ref="TP1", value="KNOCK OUT (to VW-4)",
                     footprint="TestPoint:TestPoint_THTPad_D1.5mm_Drill0.7mm")
    tp1[1] += load
    tp2 = Component("Connector_Generic:Conn_01x01", ref="TP2", value="KNOCK GND (to VW-5)",
                     footprint="TestPoint:TestPoint_THTPad_D1.5mm_Drill0.7mm")
    tp2[1] += gnd
    c2[2] += gnd


def debug_test_points(gp_crank, gp_thr_idle, gp_ignition, gp_injector,
                       gp_spi_cs, gp_spi_sck, gp_spi_mosi, sda, scl,
                       gp_led_data, ecu_12v, ecu_sw):
    """THT test pads (TestPoint_THTPad_D1.5mm_Drill0.7mm, same footprint as
    the knock-output TP1/TP2 -- a real drilled hole for a hook probe, not a
    bare SMD pad) on the signals a scope is actually likely to probe while
    debugging firmware: the GPIO-driven digital lines, both buses, and the
    two 12V rails. Placed clear of the Pico module's own footprint (its real
    courtyard is a physical keepout once it's soldered on -- a test point
    inside it is unreachable, not just visually crowded). Not exhaustive --
    +3V3 was tried at four different anchor points and every one routed
    through the same congested corridor near the Pico, so it was dropped
    rather than fight that further; +3V3 is already exposed at many existing
    component pins (R6/R7, C2-C6, any of the INA226 VS pins) if you need to
    probe it."""
    nets = [
        ("TP3", "GP2_CRANK", gp_crank), ("TP4", "GP6_THROTTLE_IDLE_SW", gp_thr_idle),
        ("TP5", "GP14_IGN_CAPTURE", gp_ignition), ("TP6", "GP15_INJ_CAPTURE", gp_injector),
        ("TP7", "GP16_SPI_CS", gp_spi_cs), ("TP8", "GP18_SPI_SCK", gp_spi_sck),
        ("TP9", "GP19_SPI_MOSI", gp_spi_mosi), ("TP10", "I2C_SDA", sda),
        ("TP11", "I2C_SCL", scl), ("TP12", "GP10_LED_DATA", gp_led_data),
        ("TP13", "+12V_ECU", ecu_12v), ("TP14", "+12V_ECU_SW", ecu_sw),
    ]
    for ref, label, net in nets:
        tp = Component("Connector_Generic:Conn_01x01", ref=ref, value=f"TP {label}",
                        footprint="TestPoint:TestPoint_THTPad_D1.5mm_Drill0.7mm")
        tp[1] += net


def operator_ui(vcc_3v3, gnd, sda, scl, btn_menu, btn_minus, btn_plus):
    j3 = Component("Connector_Generic:Conn_01x04", ref="J3", value="OLED / UI I2C",
                    footprint="Connector_PinHeader_2.54mm:PinHeader_1x04_P2.54mm_Vertical")
    j3[1] += gnd
    j3[2] += vcc_3v3
    j3[3] += scl
    j3[4] += sda

    for ref, net in (("SW1", btn_menu), ("SW2", btn_minus), ("SW3", btn_plus)):
        sw = Component("Switch:SW_Push", ref=ref, value="PUSH",
                        footprint="Button_Switch_THT:SW_PUSH_6mm")
        sw[1] += net
        sw[2] += gnd
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

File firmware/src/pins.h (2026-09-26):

#pragma once

// GPIO map, see DESIGN.md "GPIO map".

// Q1 is an open-drain pull-down: GP2 high pulls VW-18 low (inverted).
#define PIN_CRANK           2

#define PIN_I2C_SDA         4
#define PIN_I2C_SCL         5
#define I2C_PORT            i2c0

#define PIN_IDLE_SW         6   // high = idle switch closed (VW-11 to GND)

// TS5A3159A control: high = sensor connected, low = open circuit.
#define PIN_SENSOR_AIR      8
#define PIN_SENSOR_WATER    9
#define PIN_SENSOR_LAMBDA   11

#define PIN_STATUS_LED      10  // SK6812 data, PIO

#define PIN_ECU_POWER       13  // high = ECU powered (Q2 on)

// ECU outputs are low-side switches pulled up to 3V3: active pulses are LOW.
#define PIN_IGN_CAPTURE     14
#define PIN_INJ_CAPTURE     15

// AD9833 on SPI0. GP16 is SPI0 RX in hardware, so FSYNC is driven as a plain GPIO.
#define PIN_KNOCK_FSYNC     16
#define PIN_KNOCK_SCK       18
#define PIN_KNOCK_SDATA     19
#define KNOCK_SPI_PORT      spi0

#define PIN_BTN_MENU        20
#define PIN_BTN_MINUS       21
#define PIN_BTN_PLUS        22

#define PIN_AFM_REF_ADC     26
#define AFM_REF_ADC_INPUT   0
// R20 20k / R21 10k divider: VW-17 = V_adc * 3.
#define AFM_REF_DIVIDER     3

#define I2C_ADDR_INA_ECU    0x40
#define I2C_ADDR_INA_VALVE  0x41
#define I2C_ADDR_DAC        0x60
#define I2C_ADDR_OLED       0x3C

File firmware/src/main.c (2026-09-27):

#include <stdio.h>

#include "board.h"
#include "capture.h"
#include "cmd.h"
#include "crank.h"
#include "dac.h"
#include "ecu.h"
#include "hardware/watchdog.h"
#include "knock.h"
#include "pico/stdlib.h"
#include "sense.h"
#include "ui.h"

static void poll_serial(void) {
    static char line[CMD_LINE_MAX];
    static size_t len;
    static bool overflow;

    int c;
    while ((c = getchar_timeout_us(0)) != PICO_ERROR_TIMEOUT) {
        if (c == '\r' || c == '\n') {
            if (overflow) {
                printf("ERR line too long (max %d)\n", CMD_LINE_MAX - 1);
            } else if (len > 0) {
                line[len] = '\0';
                cmd_process_line(line);
            }
            len = 0;
            overflow = false;
        } else if (len < CMD_LINE_MAX - 1) {
            line[len++] = (char)c;
        } else {
            overflow = true;
        }
    }
}

// Longest main-loop stall is a USB host that stops reading: stdio_usb gives up
// after 500 ms once, then drops output. A reset leaves the ECU unpowered (R16).
#define WATCHDOG_MS 2000

int main(void) {
    cmd_set_boot_reason(watchdog_enable_caused_reboot() ? "watchdog" : "power");
    board_init();
    crank_init();
    dac_init();
    sense_init();
    knock_init();
    capture_init();
    ui_init();
    stdio_init_all();
    watchdog_enable(WATCHDOG_MS, true);

    while (true) {
        watchdog_update();
        uint32_t now_ms = to_ms_since_boot(get_absolute_time());
        ecu_poll(now_ms);
        dac_poll(now_ms);
        poll_serial();
        ui_poll();
    }
}

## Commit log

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2026-09-10 Verify VW pinout; add throttle switches, AFM ref sense, bus-voltage read
    - verified the harness against the cabby-info.com Digifant II 25-pin reference;
    DESIGN.md now marks each pin confirmed / flagged (VW-8-vs-18 crank, VW-6/11
    idle-vs-WOT unresolved)
    - J0 -> 15-pos terminal block; break out VW-6/11 (throttle switches) and VW-17
    - throttle_switches(): Q4/Q5 open-drain emulate the idle + WOT micro-switches
    on GP6/GP7, fail-safe open
    - afm_ref_sense(): R20/R21 divider + C5 feed VW-17 into GP26/ADC0 so the LMM
    sim can be scaled ratiometrically
    - U1 VBUS moved to the shunt load side -> reads the ECU supply voltage;
    U3 VBUS on the valve supply rail -> reads valve feed voltage
    - mountin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
    [Digifant2_Pruefstand.kicad_sch, digifant2-pruefstand.kicad_pcb, digifant2-pruefstand.kicad_sch]
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2026-09-11 Fix throttle-switch model + give the OLED header real clearance
    Corrections sourced from the user's own hands-on Digifant HiL notes:
    - VW-6 is sensor/idle-switch common ground, not a 2nd switch contact -- wired
    to GND directly. Only one idle switch, on VW-11 (Q5). Removed Q4/R18/GP7.
    - VW-18 confirmed for the crank/Hall signal (needs >=8-10V amplitude per the
    user's own bench notes), resolving the earlier VW-8-vs-18 ambiguity.
    - R10 1k injector pull-up validated (their bench found 10k too weak, even
    2.2k marginal).
    - Noted VW-3 fuel-pump-relay monitoring and per-signal indicator LEDs as
    possible future additions, per the user's original HiL design.
    Also: J3 (OLED header) now gets it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
    [Digifant2_Pruefstand.kicad_sch, digifant2-pruefstand.kicad_pcb, digifant2-pruefstand.kicad_sch]
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2026-09-11 Document Digifant I (G40/G60) as out of scope, per user's repair notes
    No circuit change -- this board targets Digifant II (2H) only. Captures the
    real incompatibilities (VW-5 knock-gnd vs CO-pot, inverted G60 ignition) so
    they aren't lost before a future G40/G60 variant is designed.
    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
2026-09-11 Give the Pico's USB port real clearance from J1
    J1 (12V screw terminal) was only ~7.5mm from U5's USB end, X-overlapping it --
    a plugged-in cable would likely have fouled the terminal block / its wires.
    Moved U5 down (gap now 23mm); cascaded Row A and the OLED zone down to match,
    board grew to 144x169mm.
    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
    [Digifant2_Pruefstand.kicad_sch, digifant2-pruefstand.kicad_pcb, digifant2-pruefstand.kicad_sch]
2026-09-11 Move J2 (idle valve) next to RS2/U3 to shorten its traces
    Was ~75mm away in the button row; now sits right next to the current-sense
    components it electrically belongs with.
    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
    [Digifant2_Pruefstand.kicad_sch, digifant2-pruefstand.kicad_pcb, digifant2-pruefstand.kicad_sch]
2026-09-11 Layout surgery: real netclasses, GND reconnected, Kelvin taps, direct 12V rail
    Per a deep layout review (Opus), fixed the issues that mattered electrically:
    - Real 'Power' (0.8mm) / 'Gnd' (0.5mm) KiCad netclasses -- previously the
    0.6mm widths only existed inside the Freerouting session file, so any
    hand-routed trace (including these Kelvin taps) would have defaulted to
    0.2mm with no DRC check to catch it.
    - GND was split into 4 disconnected islands (the whole operator-UI cluster --
    buttons, LED, OLED header -- had no copper ground return at all) and
    physically routed the ECU's full return current through U1/U3's own
    ground pads. Ripped up the ad-hoc daisy chain and let it re-ro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
    [digifant2-pruefstand.kicad_pcb]
2026-09-11 Docs: list fix_layout.py/reroute_missing.py, drop stale LED_THT fetch
    Found while auditing docs against the current source/board:
    - README's file table was missing the two layout-surgery scripts
    - fetch_libs.sh still fetched LED_THT.pretty/LED_D5.0mm-4_RGB, a leftover
    from before D2 became an SK6812 (no longer referenced anywhere)
    Everything else checked (GPIO map, part values, I2C addresses, VBUS wiring,
    board dims, harness table) matched the source exactly.
    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
2026-09-11 Fix: board/ had a broken intermediate committed, not the final phase2 result
    The last session's push (e09f6d9) accidentally copied in a phase2 experiment
    (north GND escape for U1/U3) instead of the accepted west-escape version —
    it DRC'd with 105 violations including real GND-vs-+12V_ECU shorts and 5
    unconnected pads, not the "handful of items" the docs claimed.
    Rebuilt phase2 fresh from the prephase2 checkpoint (clean GND/12V-rail
    reroute) with the documented west-escape Kelvin traces. This is genuinely
    the best achievable scripted result: DRC still shows a real cluster (2
    shorting_items, 2 clearance, 5 tracks_crossing, 5 unconnected) but it's
    now the correct, previously-analyzed residua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
    [digifant2-pruefstand.kicad_pcb]
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2026-09-12 Add Mouser sourcing BOM
    BOM.md: full part-by-part table with Mouser part numbers, researched
    against mouser.com. 24 of 30 line items verified with an exact Mouser
    SKU; 6 flagged as unconfirmed/not-stocked (RS2 0.033R shunt, D1 SS54
    diode, D2 SK6812 LED, J0 15-pos terminal block, Y1 oscillator, and a
    few generic parts where only the Mouser category was confirmed) rather
    than guessed, since these are real purchasing numbers.
    mouser_cart.csv: just the verified rows, ready to paste into Mouser's
    bulk order tool.
    Claude-Session: https://claude.ai/code/session_01GgbvgUaRvNV7WyBdaSUkDT
    [mouser_cart.csv]
2026-09-12 Add JLCPCB SMD-assembly BOM + CPL for a hybrid sourcing plan
    Machine-place the 42 SMD parts with a confirmed LCSC part number
    (researched against lcsc.com; nothing pattern-guessed made it into
    these files) and hand-solder the rest: THT connectors/switches/Pico,
    plus F1/RS1/RS2/Y1 where no single LCSC SKU could be confirmed this
    pass. Positions/rotations in jlcpcb_cpl.csv are real, pulled straight
    from board/digifant2-pruefstand.kicad_pcb via pcbnew.
    JLCPCB_ASSEMBLY.md flags the per-part rotation-check caveat (KiCad's
    0 degree orientation doesn't always match JLCPCB's convention for
    polarized parts) and the SS54 vs SS54C package gotcha on D1.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
    [jlcpcb_bom.csv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]
2026-09-12 Hand-route the U1/U3/RS1/RS2 pocket + add GND pour: DRC clean
    User fixed the remaining Kelvin-sense-trace violations (2 shorting_items,
    2 clearance, 5 tracks_crossing) by hand in KiCad's interactive router,
    and added a B.Cu GND pour, which also picked up the 3 previously-
    unconnected GND pads near the Pico (U5) for free.
    DRC is now clean: 0 unconnected items, 0 shorts, 0 clearance/crossing
    violations. One minor starved_thermal note remains (U5 GND pad 42 has
    1 pour spoke instead of the zone's preferred 2 -- connected fine, just
    a slightly weaker thermal/mechanical joint). Everything else is the
    same pre-existing cosmetic noise (silkscreen, lib_footprint_mismatch).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
    [digifant2-pruefstand.kicad_pcb]
2026-09-12 Add missing AD9833 decoupling caps (C7, C8) before fab
    The layout review flagged AD9833's COMP/CAP_2V5 pins as decoupling-only
    with no cap ever added -- a real gap, not cosmetic, since skipping it
    would mean a bodge-wire fix after fab. Added per ADI's recommended
    application circuit: 100nF from each pin to AGND.
    - digifant2_pruefstand.py: C7 (COMP) and C8 (CAP_2V5), both to gnd.
    - Schematic: regenerated a scratch copy to get circuit-synth's correct
    net/label placement math, then spliced just the new symbol + label
    blocks into the committed schematic (preserving all prior manual
    work). Removed the two now-stale no_connect flags on U4's COMP/
    CAP_2V5 pins. Renamed the auto-generated n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
    [Digifant2_Pruefstand.kicad_sch, digifant2-pruefstand.kicad_pcb]
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2026-09-13 Fix VW-17 divider headroom before fab: R20 15k -> 20k
    Found in USE_CASES.md's verification pass: the divider's stated 9V
    worst case (VW-17, airflow-pot reference) divided down to 3.6V through
    the old 15k/10k ratio -- right at the RP2040 ADC's absolute-max input
    rating, zero margin. Nominal 5V operation was always safe; it was
    specifically that stated fault/worst-case voltage with no headroom.
    R20 -> 20k changes the ratio from 10/25=0.4 to 10/30=0.333, so the same
    9V worst case now lands at 3.0V (0.6V of real margin) while nominal 5V
    still sits mid-range at 1.67V. Value-only change (same footprint, no
    topology change), so no re-routing needed -- updated in the circuit
    source, schematic, and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
    [Digifant2_Pruefstand.kicad_sch, digifant2-pruefstand.kicad_pcb]
2026-09-13 Add R20 to sourcing files (was missing entirely, plus value fix to 20k)
    R20 never made it into BOM.md/mouser_cart.csv/jlcpcb_bom.csv in the
    original sourcing pass -- a real gap independent of the divider-ratio
    fix in 848cfa7, just found while updating those files for it. Added
    with verified part numbers: Mouser RC0805FR-0720KL, LCSC C4328 (both
    confirmed on their respective sites, 20k value matching the new ratio).
    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
    [jlcpcb_bom.csv, mouser_cart.csv]
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2026-09-13 Fix RS2's parallel ground path and give the knock output a real path out
    Two of the three genuinely-open findings from USE_CASES.md:
    1. RS2 (idle-valve shunt) sat as a separate tap to GND, in parallel with
    the ECU's own low-side driver on VW-23 -- both reached the same shared
    GND, so return current split between RS2 and the ECU's internal switch,
    and U3 only ever measured whatever fraction happened through RS2.
    Understated the true current, worst exactly when the ECU driver was on.
    Fixed: RS2 is now truly in series (valve -> RS2 -> VW-23), so 100% of
    the return current crosses it. U3's IN+/IN- assignment was swapped
    (IN+ keeps the net that already had a routed path to J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
    [Digifant2_Pruefstand.kicad_sch, digifant2-pruefstand.kicad_pcb, mouser_cart.csv]
2026-09-13 Add 12 scope-probe test points (TP3-TP14) for firmware debugging
    Bare 1.5mm test pads (same TestPoint_Pad_D1.5mm footprint as the knock
    output's TP1/TP2) on the signals most likely to get probed while
    debugging: crank drive, idle-switch drive, ignition/injector capture,
    the AD9833 SPI bus (CS/SCK/MOSI), the I2C bus (SDA/SCL), the status LED
    data line, and both 12V rails (sensed + switched).
    Placement used an automated collision check (footprint + track distance)
    against the real board, not manual trial and error -- 12 of 13 originally
    attempted points cleared on the first or second pass. +3V3 was dropped
    after 4 different anchor attempts (3 different Pico pins, then a
    decoupling cap elsewhe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
    [Digifant2_Pruefstand.kicad_sch, digifant2-pruefstand.kicad_pcb, mouser_cart.csv]
2026-09-14 Fix test points: real THT footprint, and move 10 out from under the Pico
    Two real defects caught by user review of the previous commit:
    1. All 14 test points (TP1-TP14) used TestPoint_Pad_D1.5mm, a bare SMD
    pad with no drill -- not THT as documented/intended. Switched to
    TestPoint_THTPad_D1.5mm_Drill0.7mm (real 0.7mm hole), vendored the
    footprint, and updated fetch_libs.sh.
    2. TP3-TP12 were anchored right at their signal's own Pico pin, which
    placed 10 of the 12 physically *underneath* the Pico module's real
    footprint courtyard (x:[10,32.1] y:[47,99.1]) -- completely
    unreachable with a probe once the module is soldered on. Moved them
    to the clear margin strip west of t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
    [Digifant2_Pruefstand.kicad_sch, digifant2-pruefstand.kicad_pcb]
2026-09-14 Add a 12x16 THT proto area (PROTO1) in the empty space by J0
    Perfboard-style prototyping grid: 192 isolated 1.6mm/0.8mm-drill pads
    on 2.54mm (0.1") pitch, ~30x38mm, placed in the large empty area
    bottom-right of the board (below J0's footprint, clear of the H4
    mounting hole's keepout). Each pad is its own net -- solder in whatever
    you need for one-off additions or bodge wires, same idea as a classic
    protoboard section.
    PCB-only, same treatment as the mounting holes: no schematic symbol,
    since it isn't part of the actual circuit. Verified DRC-neutral (zone
    refilled so the GND pour properly isolates each pad; the one new
    DRC line is an expected extra_footprint warning, matching what H1-H4
    wou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
    [digifant2-pruefstand.kicad_pcb]
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2026-09-19 Correct BOM/sourcing data against live Mouser lookups
    Add C9/C10 to the BOM (100nF row, JLCPCB BOM/CPL files) - they were missing
    entirely, which would have left them off the JLCPCB assembly order and the
    pick-and-place file.
    Fix several part numbers found wrong or unorderable while placing the actual
    Mouser order: TP1-14 (5010 -> 5011, wrong digit), AD9833 (needs the -REEL7
    tape-and-reel suffix), RS2 (Bourns part exists but zero stock; substituted
    Vishay Dale WSL2512 in stock), D1 (Comchip not on Mouser; substituted Diodes
    Inc SS54FSH), Y1 (EuroQuartz guess wasn't on Mouser; found IQD's part,
    confirmed matching package/voltage/output format), J0 (MaiXu not on Mouser;
    found a Molex 15-pos/5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
    [jlcpcb_bom.csv, mouser_cart.csv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]
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2026-09-26 BOM: pin down the exact SK6812 variant for D2
    Specify the 5050 RGB variant and list the look-alikes that won't fit the
    footprint (MINI, 2020/EC) or need different firmware (RGBW), plus the WS2812B
    fallback. Also note D2 runs from 3.3V, below the SK6812's typical VDD spec.
    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
2026-09-26 Firmware: generate the crank/Hall signal on GP2 with PIO
    A PIO state machine plays alternating phase lengths from its TX FIFO,
    refilled from an interrupt so main-loop stalls can't stretch a period.
    rpm 0-8000 (0 = stopped, VW-18 high); pulses per rev and duty are
    adjustable via "crank ppr|duty" since the real 2H Hall waveform isn't
    confirmed yet (defaults 2 ppr, 50%).
    Timing math is plain C and unit-tested on the PC; the assembled PIO
    program is checked in an independent PIO emulator for the N+4
    cycles-per-phase model the math relies on. Not yet run on hardware.
    Claude-Session: https://claude.ai/code/session_01XcEuUwwCT37oProAm8HYeY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
    [cmd.c]
2026-09-26 Firmware: drive the MCP4728 sensor DAC
    All channels use the internal 2.048V reference: air/water/afm at gain x2
    (1 mV per code, 0-3300 mV, VDD-limited), lambda at gain x1 (0.5 mV steps,
    0-2047 mV). Each update is a Multi-Write that re-sends reference and gain
    bits, so a DAC reset back to its EEPROM defaults can't mis-scale later
    writes; EEPROM is never written. I2C failures are reported per command
    and as dac_i2c in status.
    Frame encoding is plain C, unit-tested against bytes built from the
    datasheet (DS22187E fig. 5-8) and decoded back with its output formula.
    Not yet run on hardware.
    Claude-Session: https://claude.ai/code/session_01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
    [cmd.c, dac.c]
2026-09-27 Firmware: read ECU and idle-valve current/voltage from the INA226s
    Current is V_shunt / R_shunt straight from the shunt register (RS1 0.020R,
    RS2 0.033R), bypassing the calibration/current registers. U3's sign is
    flipped since its IN+ sits on the ECU side of RS2. 64-sample averaging at
    1.1 ms conversions (~141 ms per result) smooths the valve's PWM. Chips are
    only configured after answering with TI's manufacturer ID; missing ones
    read "na" and are retried on each read.
    Register conversions and current math are unit-tested on the PC against
    the datasheet (SBOS547). Not yet run on hardware.
    Claude-Session: https://claude.ai/code/session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
    [cmd.c, sense.c]
2026-09-27 Firmware: drive the AD9833 knock generator
    knock <hz> outputs a continuous sine (1-20000 Hz, 0.093 Hz steps from the
    25 MHz MCLK); knock off holds the chip in reset. Each change resets, loads
    FREQ0 as two 14-bit halves, zeroes PHASE0 and releases reset. SPI0 mode 2
    at 1 MHz with FSYNC on GP16 toggled per word. Register layout taken from
    the Linux ad9834 driver and cross-checked against the RobTillaart library
    (the datasheet PDF wasn't reachable from the build sandbox).
    Every hardware block now has a real driver, so the status stubs= field is
    gone. README notes that R12/C2 low-pass the output (~8 kHz corner) and that
    crank-synchronised bursts need ignition capture first.
    Word sequences are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
    [cmd.c, knock.c]
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2026-09-27 Firmware: crank-synchronised knock bursts
    "burst <start_deg> <len_deg> [every]" gates the AD9833 tone on each crank
    reference (VW-18 falling edge): a hardware alarm releases reset at the start
    angle and sets it again after the length, converting degrees with the
    measured reference period. Bursts must fit within one reference period; one
    still on when the next reference arrives is cut off there. A start time
    already past (0 deg) starts the burst immediately. SPI raised to 8 MHz so a
    start/stop word costs ~2 us in the IRQ.
    knock.c now runs on the PC against test/fake_sdk (simulated clock, alarm and
    SPI log); test_knock_burst.c checks every emitted word and its timing across
    normal bursts, eve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
    [capture.c, cmd.c, knock.c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]
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2026-09-27 Firmware 0.9.0: fixes from a deep review before first power-on
    - ECU over-current trip on U1 (ecu trip/reset, default 2500 mA, latched)
    - DAC and knock outputs parked while the ECU is off, restored on power-up
    - Knock bursts: ignore stale/early alarm callbacks (latched IRQ race)
    - Capture: one timestamp per interrupt, 64-bit time, glitch counter,
    no bogus period after a crank stop, capture pull-downs disabled
    - Watchdog (2 s) with boot=watchdog in status; I2C bus recovery at boot;
    DAC rewrites after a failed write; copy_to_ram build
    - Stricter number parsing, clearer rpm/ppr errors, ppr change checked
    against the active burst
    - bench.py: drop late replies before each command, clean tim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
    [bench.py, board.c, capture.c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]
2026-09-27 Add GitHub Actions: firmware build + tests, spell check, KiCad ERC/DRC
    - ci.yml: Pico SDK 2.1.1 firmware build with -Werror (new
    PRUEFSTAND_WERROR option), uf2/elf artifacts, all no-hardware tests
    via firmware/test/run_all.sh, codespell, and tag-triggered (fw-v*)
    firmware releases checked against FW_VERSION
    - board.yml: KiCad 10 ERC and DRC with schematic parity when board/
    changes; fails on errors, full reports uploaded
    - run_all.sh runs every PC test, the parser, bench.py via socat and the
    PIO emulator; STRICT=1 makes skipped checks fail
    - .codespellrc, requirements-test.txt, README CI section and badges
    Claude-Session: htt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
2026-09-27 UPSTREAM_BUGS.md: record filed circuit-synth #619, drop false sheet-pin report
    The pin name-over-number bug is filed upstream as #619 with a verified
    repro and fix. The sheet-pin 1.27 mm offset turned out harmless: KiCad
    snaps sheet pins onto the sheet border, and ERC is clean.
    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
2026-10-08 Board: restore pin-1 silk on U6-8, fix J0/J3 labels (from an assembly report)
    Found by rendering the actual silkscreen and cross-checking against the
    stock footprint and pad positions, via pcbnew scripts (not a full
    circuit-synth regeneration, which would discard the hand-routing and
    GND pour):
    - U6/U7/U8 (TS5A3159A): the stock SOT-23-6 footprint's pin-1 triangle
    was silently dropped when circuit-synth embedded its simplified copy
    into the board. Restored from the stock footprint's geometry.
    - J0: per-pin function labels (VW-25, GND, ...) sat on the side the
    harness bundle lies across once wired, unreadable after install.
    Moved to the other side of the connector; one label (+12V SW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
    [digifant2-pruefstand.kicad_pcb]
2026-10-08 BOM: fix resistors missing from the actual order, D2 source, hardware
    - mouser_cart.csv never included R9/R11/R17 (330R), R12 (200R) or RG1
    (100R), despite being in BOM.md since the start -- genuinely missing
    from what was ordered. Added now; BOM.md flags this for anyone who
    ordered from the original cart.
    - U1/U3 (qty 2 INA226) and U4 (AD9833) were already correct in the cart
    since the 2026-09-20 correction pass -- noted in BOM.md so a report
    of these being short points at checking order history, not the repo.
    - D2 (SK6812): added a concrete lead, OPSCO's plain SK6812 on LCSC
    (C5378720), flagged to verify pad pitch before ordering (body size
    differs slightly from our footprint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
    [mouser_cart.csv]
2026-10-08 BOM: add RS Components alternatives for the parts missing from the Mouser order
    For the resistors and ICs the user's assembly report flagged as short,
    cross-checked against RS Components directly (not just search snippets --
    several regional rs-online.com pages agreeing on the same stock number,
    or a direct fetch where that worked):
    - R9/R11/R17 (330R): RS 242-6990
    - R12 (200R): RS 242-6931 (MOQ x100 on the listing checked)
    - RG1 (100R): RS 618-5135
    - U1/U3 INA226AIDGST: RS 742-2889
    - U4 AD9833BRMZ: RS 183-2180 -- RS stocks the plain part, no -REEL7
    tape-and-reel suffix needed (unlike Mouser)
    Also checked and noted: RS's own SK6812 (1808086) is a 3535 package,
    confirmed too small for D2'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
2026-10-08 BOM: add J2's mating connector, missing from the BOM entirely
    J2 (the idle valve header) had no counterpart in the BOM at all -- the
    female housing and crimp contacts needed to actually wire the valve up
    to it. Added XHP-2 (housing) and SXH-001T-P0.6 (contact, x2), both
    confirmed at Mouser. Flagged the crimp-tool caveat given the valve's
    ~1.8A peak PWM current, and a pre-crimped pigtail cable as the
    practical no-tooling alternative.
2026-10-08 BOM.md: fix a stray blank line that broke the table from the standoffs on
    A blank line between the C2-C10 row and the M3 standoff row split the
    Markdown table in two there -- GFM tables end at the first blank line,
    so everything from the standoffs row onward rendered as an orphaned,
    header-less table (or not as a table at all, depending on the
    renderer). Removed it; the table is now one contiguous block.
2026-10-28 Fix two bring-up bugs: TS5A3159A COM pin, R10 injector pull-up
    U6-U8 (TS5A3159A, SOT-23-6): the ECU-side output was wired to pin 3 (NC)
    and COM (pin 4) was left open, so VW-9, VW-10 and VW-2 floated (0.3 V,
    0.4 V, 0.1 V instead of 1.000 / 2.500 / 0.450 V). Now wired to pin 4.
    Rev 1 boards need a wire from pin 4 to pin 3 on each chip; with it all
    four DAC outputs and the open-sensor switching check out.
    R10 (VW-12 injector pull-up): 1k left VW-12 at 0.8 V with the real ECU and
    no injector pulses. With ~180R (R10 || 220R) it injects once per crank
    revolution, ~3.5-3.9 ms at 850 rpm. R10 is now 220R; BOM.md updated, the
    order files still describe the Rev 1 build.
    DESIGN.md, USE_CASES.md and B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
2026-10-28 BRINGUP: record Stage 6 bench results (reference edge, ECU current, rework)
    Reference edge is the VW-18 rising edge for the injector (constant +1.3 deg
    offset at duty 30/50/70); ignition follows no single edge. Spark edge is
    still undetermined: the ignition output is angle-defined (low phase ~70 deg
    at every rpm), so the knock-retard test (U4) is needed. Also records the
    ECU current and the three rework items found on Rev 1.
2026-10-28 Firmware: drive the D2 status LED (SK6812 on GP10, PIO1)
    Dim white = ECU off, green = ECU on / crank stopped, blue = crank running,
    red = over-current trip latched. Colour rules live in status_led_core.c with
    a PC unit test; the driver resends the colour every 500 ms. Checked on the
    bench: all four colours show, and the trip test (100 mA limit against the
    connected ECU) trips at 523 mA, latches, refuses `ecu on`, clears on
    `ecu reset`.
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
